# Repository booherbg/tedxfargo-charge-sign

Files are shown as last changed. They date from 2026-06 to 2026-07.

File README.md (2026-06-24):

# TEDxFargo CHARGE — LED Sign

Parametric OpenSCAD system for generating 3D-printable STLs for an illuminated
"CHARGE" sign: channel-letter shells lit from behind by 12mm bullet pixels
through a clear, swappable diffuser panel.

See [`docs/superpowers/specs/2026-06-24-charge-led-sign-design.md`](docs/superpowers/specs/2026-06-24-charge-led-sign-design.md)
for the full design.

## Build

```bash
./build.sh          # renders every part in src/parts/ to ./stl/
```

Requires [OpenSCAD](https://openscad.org/). Override the binary with
`OPENSCAD=/path/to/openscad ./build.sh`.

## Layout

```
src/config.scad     all tunable knobs (edit this, then rebuild)
src/collar.scad     imports the calibrated press-fit collar
src/diffuser.scad   swappable diffuser panel
src/coupon.scad     depth-ladder test coupon
src/parts/*.scad    build targets (open any in the OpenSCAD GUI)
assets/             bullet-collar.stl, letter EPS, logo
stl/                generated output (git-ignored)
```

## First print: the stackup coupon

`stl/coupon_body.stl` is a 3-cell test rig with LED-to-panel gaps of 20 / 35 /
50mm and three merged press-fit collars. Print it in **opaque** filament. Print
`panel_{1,2,3}mm.stl` in **clear** filament and vary slicer infill
(gyroid/grid, top & bottom solid layers = 0) to test the diffuser. The panels
**press-fit** into the chimneys (size = opening − `panel_press_clear`), so you
can swap thicknesses freely. Press a pixel into each collar, and compare.

> Tune `dome_clear` in `config.scad` to your actual pixel's dome protrusion —
> the gap distances depend on it.

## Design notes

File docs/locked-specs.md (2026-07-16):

# Locked specs (validated)

Finalized, print-validated parameters for the **TEDxFargo CHARGE** neon-sign replica.
Change only with a new test. Full onboarding context: `docs/HANDOFF.md`.

## Bullet pixel — the hardware everything keys off
- dome **Ø8**, barrel **Ø12**, flange **Ø13.6 × 2mm**, dome-tip → flange **5.5mm**
- dome protrusion (`dome_clear`) = **4.0mm**; plate bore (`pixel_through`) = **12.3mm**
- calibrated press-fit collar `assets/bullet-collar.stl` (bore ~Ø12.19)
- 24V; **own 300, can buy up to 600**; 150W/24V PSU

## Diffusion recipe ✅ THE WIN
Cross-section = **white reflective shell + ~15mm air gap + chunky clear lens with a BAKED fuzzy top.**
- **Fuzzy winner = V3**: ~**1.5mm** bump cells, ~**0.8mm** bump height (`src/parts/fuzz_v3.dat`,
  regen `tools/make_fuzz.py OUT 1.5 0.8`). Best balance of texture + brightness; **hides individual
  LEDs**; pure heightfield → **no supports, no spaghetti**. (Bambu fuzzy-skin can't texture tops, so it's baked.)
- **Top surface pattern: Concentric.** Print **lens-UP**.
- **White interior recycles light** (fewer LEDs, more even). **Never a dark interior** facing the LEDs.
- Print settings (Adafruit-derived): 0.16mm layer · 0.42 line · 2 walls · 10% gyroid · 6 top/bottom ·
  supports off · brim · bridge fan on.

## LETTER cross-section — 3 colors (filament change)
1. **BLACK** — base/tile (billboard negative space) + channel outer structure.
2. **WHITE** — a couple layers lining the channel **rear (floor) + inner walls** (reflector).
3. **CLEAR** — chunky lens on top with the **V3 baked fuzzy skin**.

## Letters — faithful widened neon outline
- **Faithfully replicate the logo's hollow neon-outline letters** (`assets/svg/{C,H,A,R,G,E,CHARGE}.svg`,
  from EPS via `tools/eps2svg.sh`). **Both neon lines lit.**
- **Widen each neon tube +3mm/side → ~18mm channel** so the Ø12 pixel + collar fit; the hollow-outline
  look is preserved (verified in render).
- **NO letter splitting.** Cap height **270mm** — **rotate the wide letters 90°** so their width runs
  along the 320mm bed axis (at 270mm the widest letter H is ~320mm = the full bed; heights fit easily).
  Sign ≈ **1.6m** wide. (Absolute max ~310mm, but that splits ~5 of 6 letters for +40mm — not worth it.)
- **Pixel pitch ~17mm (TIGHT — chosen)** for a smooth "solid tube" glow → CHARGE + bolt ≈ **~510 pixels**
  at 270mm cap. Buy up to 600 (own 300 + 300 more). (Sparser ~32mm ≈ 270px is the fallback if budget bites.)
- Pixel placement needs a **tube-centerline extractor** (skeletonize each letter) — **TODO tooling.**

## Bolt lens fit ✅ printed & snapped — superseded by the INTEGRATED lens
- `bolt_lip_clear = -0.2` → lip Ø18.2 into the 18.0 channel (0.2mm interference). Material-robust
  (clear PETG + clear PLA). Dialed via `lens_fit_*` slices. The bolt is a **solid-stroke** channel;
  letters use the same channel construction along the neon path.
- **CURRENT (2026-07-02): the lens is co-printed** (`bolt_lens_integrated` in `src/bolt.scad`,
  print `stl/bolt2_2color.3mf`): welded roof + baked V3 fuzzy top, printed lens-UP in use
  orientation — no flip, no mirror, no press-fit. The -0.2 fit stays locked for any future
  separate-lens part. ALL-PETG build (same-material welds; settings-based haze levers dropped —
  tweaks proved unnoticeable; texture is baked geometry).
- **Slicing note (user-verified):** the baked fuzzy top staggers where top/bottom shells land in
  the thin lens → one mid-lens layer shows small "internal island" artifacts (a map of the tallest
  bumps). **Fix: bottom shell layers +1** (or lens infill 100%). Harmless either way — internal,
  hidden by the frosted top.

## Pixel clearance (matrix) ✅ collision-verified
- `led_void = 14.0`, `led_clear = 2.5`, masks on flared floor legs. `src/parts/lens_pixel_collision.scad`.

## Print orientation & support
- Everything prints **lens-up / plate-down, NO supports.** Chiral flip-to-use parts must be pre-mirrored
  (see the chiral-flip note) — but letters/testbox print in use-orientation, so it's moot for them.

## Bed envelope ✅ VALIDATED in Bambu Studio (2026-07-03)
- H2D dual-nozzle ("left/right nozzle only" side bands): the **both-nozzle zone fits the
  worst-case piece 316 × 295** placed 295-across / 316-deep — confirmed by placing
  `stl/bedcheck_316x295.stl` (chamfer = orientation) with the real 3-filament profile.
- Multi-color pieces must sit ENTIRELY between the side bands (every region needs both
  nozzles). Panelizer limits stay `--bed-long 316 --bed-short 296`.
- Print-card notes: prime tower **ON** (right-nozzle-only column — it fits: every plate and
  letter is ≤316 across, and the tower absorbs the black→clear flush), brim OFF on the long
  sides (~2mm spare); consider inner mouse-ears on big black plate corners.

## Letters — build pipeline ✅ LIVE (2026-07-02)
- **`tools/centerline.py`** (pure stdlib + ghostscript): EPS → raster → Zhang-Suen skeleton →
  ordered tube centerline(s) → pixel points at pitch → `src/parts/letter_<L>_data.scad`
  (+ a `.debug.ppm` overlay — always eyeball it). Letters are OPEN neon-tube runs, not closed
  outlines (the C = ONE 1161mm tube: outer sweep + mouth turn + inner sweep; 69 px @ 17mm).
- **`src/letter.scad`**: 3-color tile — BLACK base+outer wall / WHITE liner+inner wall+collars /
  CLEAR welded fuzzy lens. Channel cross-section identical to the bolt (18 interior / 22 outer).
- **C @ 270 cap**: tile 313×298×23mm — H2D fit only with width along the 320 axis, `lt_margin=2.5`.
  ⚠ At 270 cap the H's art is ~321mm wide and the +3mm/side WIDENED band ≈ **331mm → H will NOT
  fit the 320 axis**. When H's turn comes: cap ~255–260, or split H after all, or widen H's
  outer verticals inward-only. (Rotation can't save a 331×~290 tile on a 300×320 bed.)

## Still open
- **Generate the other letters** (H A R G E — extractor is generic) + integrate the bolt into the layout.
- **Mounting:** rear rail / black backer board (hides wiring + controller). Deferred.
- **Full-billboard extras** (arrow, TEDxFargo badge, 2026, yellow border, truss) — later scope.

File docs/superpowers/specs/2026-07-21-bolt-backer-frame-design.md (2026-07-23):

# Bolt backer frame — printed torsion box, vented, internal PSU

**Goal:** give the bolt board (410×550, 4 plates + 4 seam straps, no frame today)
a fully printed enclosure: stiff, clean, fully closed back with vent slits,
wall-hung or free-standing, controller AND PSU fully enclosed — ONE mains cable
through a side-wall gland and that's it. Experiment to replace the heavy
carpenter-built wood frame style used on the word sign.

User decisions (2026-07-21, three revision rounds same day): **picture-frame
torsion box** over sparse ladder and monocoque tub; **internal PSU from day
one** — plan for the whole 30-mm-tall LRS family (**LRS-50 / 75 / 100**, one
tray profile); cavity **36 mm** (tray floor 4 over the flange + PSU 30 + 2
clear; wall-FACE mounting like the word sign's exterior would need 50+ mm
walls, rejected); fully closed back **with vent slits**; snap-in **feet** in
bottom-rail slots; **two thick top handles** for carrying + wall-hanging
(replace the loops/keyhole idea); controller = **Gledopto Elite 2D-EXMU
(GL-C-616WL, 129×50×23)** inside, shell end-tab screws; **one PG9 gland,
printed open** — no knockouts to punch or drill, alternates are swap plates.
M3 self-tap into printed bosses now, bores sized so M3 heat-set inserts are a
later drop-in.

Total sign body ≈ 40 mm behind the plate front (plate 2 + cavity 36 + panel
2.4), plus the front shell as built.

**V1 AS-BUILT CONFIGURATION (2026-07-22, user simplification):** controller
mounts OUTSIDE on the left-wall pads (`fr_ctl_ext`, screws at the probed
122 × 26 diagonal, body spans y ≈ 96..225), fed by a plug-in PSU — nothing
electrical inside. One **PG7 gland threaded directly into the 3.0 mm wall**
(Ø12.5 hole at y = 275, z = 19; 3.0 ≤ the 3.5 clamp limit, so no plate)
passes the single jacketed 3 × 18 AWG V+/V−/D line into the cavity, 50 mm
(2 in) above the controller's top/output end for working room — the position
is capped by the y = 300 segment joint (asserted). Everything below —
internal trays, PSU patterns, gland plate — is BUILT and KEPT as the
enclosed-future path; `GLAND_PLATE = 1` in tools/boltframe.py restores the
plate opening for the internal-PSU pivot (rails reprint required then).

**V1.1 (2026-07-22, user): cavity 36 → 48, trim dropped.** Wall becomes
50.4 ≥ the Elite's 50 width, so the exterior controller sits FULLY FLUSH on
the outer face (body z 0.4..50.4, back coplanar with the panel plane — no
front/back overhang, wall-hang unaffected). Trim strips and their groove are
dropped (`TRIM = 0`; PART=6 remains printable if ever wanted). S3/S4 rails
8 → 44, legs parametrized to `fr_cavity`. Sign body ≈ 52 mm behind the plate
front. Note: the controller DOES fit INSIDE lying flat (27 < cavity) — the
deepening is only for the flush wall-face mount; interior tray unchanged.

## Frame rails (4 corner-L segments, white PETG)

- C-channel: **flange** 16 × 4 mm behind the plate perimeter with 14 pilot
  bosses at the existing `bb_scr` kind-0 positions (the wood-rail band —
  keepout already validated); plates screw down from the front, screws they
  already have. **Outer wall** 3 mm. **AS-BUILT AMENDMENT:** the 2 mm front
  reveal is a separate **snap-on trim strip** (frame_parts PART=6, groove in
  the wall outer face) — one-piece lip + rail can't print support-free, and
  the split lets rails print FLANGE-DOWN cleanly; `reveal=0` = don't print
  trim. The trim never covers a screw: holes sit 6 mm from the plate edge,
  hole rim at 3.75, trim covers 2 (generator asserts). Assembly: sign
  face-down, segments laid flange-down onto the plate backs, dovetails
  joined, flip once, drive the 14 screws, snap trim on last.
  **Ledge** 8 × 4 mm at cavity depth 36 with M3 panel bosses.
- Segments are corner-Ls meeting at **x=205 / y=300** (AS-BUILT: y moved
  275→300 — the probe caught the joint splitting the (6,275)/(404,275)
  bosses, and 300 also clears the S1/S2 strap band; asserted now). Joint =
  printed dovetail key in an inner-face pocket + M3 cross-screws from
  outside through wall+pad into the key.
- **Handles ×2** on the top rail near the corners: thick printed bars
  (grip opening ≈ 100 × 28, body ≥ 14 thick), each bolted with 2 × M4 +
  washer/nut into top-rail bosses. Back faces sit FLUSH with the back-panel
  plane so the sign hangs flat on a wall — the grip opening doubles as the
  hang point (screw head, cleat, chain, or zip tie through it) and as the
  carry handle. Printed lying flat so layer lines run along the load path.
- Bottom rail: 2 snap sockets in the underside for **snap-in feet**
  (AS-BUILT: split-prong arrowhead tab + barb pocket — a true T-slot can't
  insert from below; squeeze the prongs from inside to release; blade
  ≈ 90 mm fore-aft); sign is wall-hung with feet out.

## Strap interface (folds in the chirality reprint)

- **S3/S4 reprint** (already required — chirality fix 6edb95e): rails raised
  8 → 32 mm (web 4 + 32 = 36 = cavity depth) with M3 bosses on top; they become
  the panels' mid-span supports. Pass-hole chamfers already cut through rails.
- **Captive hex pockets dropped on the reprint** (user 2026-07-21: nut depth/
  alignment in a pocket is fiddly — prefers flat + washer): screw bores become
  plain Ø4.5 through-holes with a FLAT back face; washer + M4 nut tightened
  from the open back (panels aren't on yet at strap-install time; the 38 mm
  gap between the raised rails leaves driver room). Screw length changes:
  plate 2 + web 4 + washer + nut ≈ 10 — the existing M4×8 are too short,
  **use M4×10 (flush) or M4×12**. `nut_pocket` param restores the old pocket
  if wanted. S1/S2 keep their pockets (installed, working).
- **S1/S2 stay installed** (correct as printed): three Ø10 printed legs drop
  into the existing leg sockets, M3 boss on top at panel height (36).
- Plates, pixels, wiring untouched.

## Back panels (4 quadrants, vented, removable)

- ≈ 209 × 279 each (bed-fit), 2.4 mm skin + ribs, half-lap rebates at
  panel-to-panel edges so they register flush. M3 screws into ledge bosses,
  raised S3/S4 rail bosses, and S1/S2 leg tops — back comes off without
  touching the plates.
- Vents: angled louver slits (light-tight, dust-shedding), intake rows along
  the bottom panels, exhaust rows in the top third; one consistent pattern,
  plus a small cluster over the controller (mic aperture for audioreactive +
  convection over the equipment corners — PSU and controller both live up
  top, so the exhaust rows do double duty).

## Internal equipment (top corners — the verified pixel-free zones)

Placement is pinned by a clearance sweep against the real pixel map (the
originally-sketched lower-left PSU spot FAILED it — a pixel sat inside the
rect; the bolt's bottom and diagonal channels fill the lower half). The two
clean zones are the TOP corners. Devices lie FLAT on 4-mm tray floors that
span the flange band, integrated into the top corner-L segments; devices stay
with the sign when panels come off.

- **PSU tray (upper-LEFT)**: zone x ≈ 1..98, y ≈ 407..536 (AS-BUILT: slid
  down 8 so the top ledge bosses clear the tray) — 28.6 mm to the nearest
  pixel, 4 mm to S3's raised rail. Fits the whole family in portrait
  (all 30 tall, L=3.0 bottom taps, M3×7 through the 4 mm floor = 3 mm in):
  - LRS-50 (case 239A, 99×82) + LRS-75 (240A, 99×97): shared **slots** at
    length 20.5/75.5 spanning width 40.5→45.5 (AS-BUILT: the two patterns
    are 5 mm apart — one slot serves both)
  - LRS-100 (case 238A, 129×97): round holes (78, 34) + (78, 67)
  Terminals point DOWN toward the cavity. Before buying: match the voltage
  to the pixel string — LRS is 5/12/24 V.
- **Controller tray (upper-RIGHT)**: Elite vertical, zone x ≈ 342..392,
  y ≈ 405..534 (10.7 mm to the nearest pixel — generator asserts ≥ 8.5 + 2).
  Two bosses at the shell's end screws — **122.0 × 26.0 diagonal, Ø4.6**
  (probed from docs/elite2d_mount.stl; no adapter plate needed). Terminals
  face the cavity; WiFi works through PETG. USB-C/Ethernet/button need the
  panel off — accepted, WLED is OTA.
- **Wiring run**: mains in low on the left wall → up the flange shelf to the
  PSU AC end (cord FG lands on the LRS FG terminal); DC across the top rail
  channel to the controller INPUT; OUTPUT drops to the chain entry at
  (194, 180). All runs < 500 mm.
- **Gland plate** low on the LEFT side wall (side entry keeps free-standing
  on the feet stable; low = hidden, cord drops to the floor): a 2.5-mm-thick
  screwed-on plate (2 × M3 into wall bosses) over a rectangular opening.
  V1 plate ships with ONE **PG9** hole printed OPEN (Ø15.2, clamps 4–8 —
  takes a 3-wire SVT mains cord; no drilling, no punch-outs). Variant plates
  (PG7 Ø12.5, PG11 Ø18.6, or two-hole for a word-sign link) are 5-minute
  prints — swap the plate, not the rail. **Seats stay ≤ 3.5 mm** — PG thread
  is ~8 mm and the locknut needs ~5 (user has over-thickened walls before;
  generator asserts). Fusing and relays live on the controller.

## Fasteners / material / mass

White PETG throughout (matches straps). SIMPLIFIED BOM (2026-07-23): three
screw SKUs, all ordinary machine screws threading printed pilots —
- M4×12 black button ×25: 11 strap (+ M4 nuts, washers optional) + 14
  plate→flange (flange pilots Ø3.4; the M4 head covers the Ø4.5 plate hole,
  no washers anywhere)
- M4×30 button ×4 + washers: handles
- M3×12 flat/countersunk ×37: 29 panels + 8 dovetail keys (every M3 pilot
  Ø2.8 × 10.5 deep so one length fits all)
Boss OD 7 keeps the M3 heat-set upgrade path. Estimate ≈ 1.3–1.7 kg total:
4 rails (2 with equipment trays) + 4 panels + 2 handles + 2 feet + 3 legs
(+ S3/S4 ~265 g at the taller rails; trim strips optional glue-on).

## Build & verify

- New generator emits `frame_layout.scad` (rail segments, boss positions from
  `bb_scr`, panel outlines, tray anchors + PSU hole patterns, gland position,
  handle bosses) + part scads in the existing `-D PART=` style; build lines
  added to build_board.sh. Generator asserts: both tray rects ≥ 11 mm from
  every `bb_px`/`bb_bite`; PSU top clearance ≥ 2; tray clear of S3 rails.
- qa_board.py grows frame checks: flange bosses == `bb_scr` kind-0 positions
  (axis-aware — see the chirality lesson), every segment/panel fits 316×295,
  panel screw bosses land on ledge/strap/leg supports, joint keys clear
  screw holes, reveal lip clears every `bb_scr` hole rim, gland-plate seat
  thickness ≤ 3.5 (PG clamp limit), handle back faces coplanar with the
  panel plane.
- Print order: S3/S4 straps first (unblocks the strap swap), then rails,
  panels, handles, feet, gland plate.

## Config params (all have working defaults)

`psu` (LRS-50/75/100 hole pattern, default all), `gland` (PG9 default /
PG7 / PG11 / two-hole link variant), `reveal` (2, 0 disables), `nut_pocket`
(off), supply-cord diameter only if it falls outside PG9's 4–8 mm clamp.

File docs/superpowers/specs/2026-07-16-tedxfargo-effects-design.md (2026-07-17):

# TEDxFargo custom WLED effects — design (2026-07-16)

Geometry-aware custom effects for the CHARGE sign, compiled into one small WLED
usermod. This spec is written to be built from a **clean session** with no
dependence on the conversation that produced it — every load-bearing WLED fact is
stated with a source reference so the builder never guesses.

---

## 1. Goal

A handful of bespoke effects that know what the pixels *are* (which letter, where
in space, where in the wiring chain) — things no stock effect can do because stock
effects only see an anonymous grid. First deliverable: the full build pipeline
proven end-to-end on hardware with **one** effect (the neon boot-up), flashable and
eyeball-verifiable. Everything after is thin additions.

**Non-goals (this spec):** the bolt/board controller (deferred — still being
built), any triggered/event-cued show logic, cross-controller sync, and the
multiplayer letter game. All explicitly out of scope (§12).

---

## 2. Current state (what already exists)

- **The sign — word controller only for now.** 459 WS281x pixels, 6 letters
  C H A R G E, wired as one greedy tube-order chain. Physically a lightning/neon
  aesthetic in electric cyan with yellow/red accents.
- **The device is in 2D matrix mode** via a flashed `ledmap.json` (134×25 grid,
  12 mm cells — committed at `ad19744`, hardware-confirmed). `isMatrix` is true;
  stock 2D effects render in true sign space. ~90% of the 3350 grid cells are `-1`
  gaps (no LED). Controller: Gledopto **GL-C-616WL** (ESP32, **no PSRAM**, ~73 KB
  free heap — this is why heavy 2D effects sometimes deplete RAM).
- **`tools/gen_wiring.py`** already loads `src/parts/word_pixmap.json`, computes
  each pixel's grid (col,row) at `WORD_CELL_MM = 12.0`, and emits the ledmap +
  presets. It is the single source of truth for geometry. We extend it to also
  emit the C header this design needs.
- **`src/parts/word_pixmap.json`** — the wiring truth. `pixels[]`, one per LED, in
  chain order (index 0..458). Fields per pixel: `x`, `y` (physical mm), `letter`
  (`"C".."E"`), `piece` (1..6, physical print piece), `chain` (== array index).
- **Letters are contiguous ranges in chain order** (verified): C 0–61, H 62–142,
  A 143–214, R 215–295, G 296–378, E 379–458. So "letter membership" is just a
  range test — no per-pixel lookup table needed for grouping.
- **Custom palettes on device** (`wled/backups/palette0-2.json`): electric cyan +
  yellow/red lightning accents. These are the effects' default color intent.

---

## 3. Key decisions (with rationale)

1. **2D substrate — keep the ledmap, do NOT switch to a 1D strip.** The user's
   favorite effects (Palette bars sweeping, Hiphotic, Fire-from-both-sides, Meteor,
   Shimmer, PS Vortex) are all *spatial* — color moving through 2D space, letters
   relating to each other. That is exactly what a 2D matrix provides and a 1D strip
   fundamentally cannot (a strip has only chain order, no vertical axis, no
   "across"). Going 1D would mean reimplementing every favorite *and* discarding the
   quality that makes them land. So the device stays 2D; custom effects address
   real LEDs via a baked geometry table + `setPixelColorXY`.
2. **A usermod is the container; the effects are ordinary custom effects.** New
   effect logic must be compiled in — presets/playlists/JSON can only recombine
   existing effects. The two homes are core `FX.cpp` (scatters our code through
   core, fights every WLED update) or a usermod (isolated in `usermods/tedxfargo/`,
   registers via `strip.addEffect()` in `setup()`, and is the natural home for the
   shared geometry helpers and the future letter-coloring HTTP endpoint). Usermod
   wins on every axis. It's lightweight: a folder + a small class + one build flag.
3. **Ambient loop.** Effects live in normal playlists next to stock effects. No
   trigger, cue, or sync layer. The "hero moment" (boot-up → strike → burst) is a
   single phased effect that loops, not an event system.
4. **Base repo: direct clone of `GLEDOPTO/WLED` @ `gledopto-16.0.1`.** This is the
   exact firmware already running on the sign — stock WLED 16.0.1 plus a thin
   Gledopto config commit (board env, onboard mic, branding). Cloning it directly
   guarantees we build against a known-good config and only add our usermod.
   (Fork-strategy cleanup — rebasing onto a clean WLED fork — is deferred; "rectify
   later.") Every API fact below was verified against WLED 16.0.1, which this
   branch is.

---

## 4. Architecture

```
src/parts/word_pixmap.json ──► tools/gen_wiring.py ──► usermods/tedxfargo/charge_geometry.h
                                                              │
                                                              ▼
        usermods/tedxfargo/usermod_tedxfargo.h  (Usermod class)
          • setup(): strip.addEffect(255, &mode_fn, PSTR("meta")) per effect
          • owns geometry helpers over charge_geometry.h (the 5 primitives)
          • (later) registers the letter-coloring HTTP endpoint
                                                              │
             mode functions: mode_charge_bootup(), ...        │  each ~20 lines
                                                              ▼
        platformio env GL-C-616WL:  custom_usermods = tedxfargo
                                                              │
                                                              ▼
                              build ──► flash ──► effect appears in WLED effect list
```

Every effect follows one uniform pattern: iterate the 459 pixels, compute a color
from the baked fields (letter / x / y / height / chain), and place it with
`SEGMENT.setPixelColorXY(col, row, color)`. The ledmap routes (col,row) → the
physical LED. **Effects assume a full-canvas 2D segment anchored at (0,0)** (the
default segment), so segment-relative XY equals absolute grid XY.

---

## 5. The baked geometry header (`charge_geometry.h`)

Emitted by `gen_wiring.py`, indexed by chain index `i` (0..458). All arrays
`PROGMEM`, ~3 KB flash total.

```c
// Generated by tools/gen_wiring.py — DO NOT EDIT. Regenerate with the ledmap so
// COL/ROW stay in sync with the flashed ledmap.json (same WORD_CELL_MM).
#define CHARGE_NUM_PIXELS  459
#define CHARGE_NUM_LETTERS 6
#define CHARGE_GRID_W      134   // must equal the active ledmap width
#define CHARGE_GRID_H      25    // must equal the active ledmap height

// enum order = chain order of first appearance: C,H,A,R,G,E
const uint8_t  CHARGE_LETTER[459] PROGMEM = { 0,0,...,5 };  // 0=C .. 5=E
const uint8_t  CHARGE_COL[459]    PROGMEM = { ... };        // grid col 0..133
const uint8_t  CHARGE_ROW[459]    PROGMEM = { ... };        // grid row 0..24 (0=top)
const uint8_t  CHARGE_HEIGHT[459] PROGMEM = { ... };        // 0..255, 0 = base of its letter, 255 = top
const uint8_t  CHARGE_XNORM[459]  PROGMEM = { ... };        // 0..255 x across whole sign (left..right)

// letters are contiguous in chain order → ranges, not a lookup
const uint16_t CHARGE_LETTER_START[6] PROGMEM = { 0, 62, 143, 215, 296, 379 };
const uint16_t CHARGE_LETTER_COUNT[6] PROGMEM = { 62, 81, 72, 81, 83, 80 };
```

Derivations (all in `gen_wiring.py`, from the same data that builds the ledmap):
- `CHARGE_COL/ROW[i]` = `gen_wiring`'s existing grid mapping at `WORD_CELL_MM`
  (`gx = int((x-ox)/cell)`, `gy = int((h_mm-(y-oy)-eps)/cell)`). **Must match the
  flashed ledmap** — regenerate both together.
- `CHARGE_HEIGHT[i]` = normalize `y` within pixel i's letter's [ymin,ymax] → 0..255,
  base=0. (Physical y increases upward; base = smallest y.)
- `CHARGE_XNORM[i]` = normalize `x` across the whole sign [xmin,xmax] → 0..255.
- `CHARGE_LETTER_START/COUNT` computed from `letter` runs (assert contiguity).

**Coupling note:** the header's COL/ROW and the flashed `ledmap.json` are two
outputs of the same mapping. If `WORD_CELL_MM` changes, regenerate both and
re-flash both. `gen_wiring.py` emits them in one run — keep it that way.

---

## 6. The five primitives (helpers on the usermod class)

Thin accessors over the header. This is the entire shared surface every effect uses.

1. **Letter groups** — `for (i = LETTER_START[L]; i < LETTER_START[L]+LETTER_COUNT[L]; i++)`.
   Powers: boot-up, per-letter Pac-Man, per-letter Fireworks, letter flicker.
2. **Tube order within a letter** — chain order *is* tube order (wiring is greedy
   along the neon path), so iterating a letter's range walks its tube. Powers:
   tube-trace, flames climbing into a letter.
3. **Height within letter** — `CHARGE_HEIGHT[i]` (0=base). Powers: flames rising,
   bottom-up fills.
4. **X across the sign** — `CHARGE_XNORM[i]`. Powers: jet-stream / lightning /
   meteor sweeps, with letters as spatial waypoints.
5. **Audio** — the AudioReactive usermod is compiled into this build (§10). Effects
   read its shared FFT data (`um_data` bins) for reactive flames. (Access pattern:
   the standard `usermods.getUMData(&um_data, USERMOD_ID_AUDIOREACTIVE)` handshake —
   verify signature against the audioreactive usermod at build time.)

Place with `SEGMENT.setPixelColorXY(CHARGE_COL[i], CHARGE_ROW[i], color)`.

---

## 7. The usermod

Scaffold by **copying an in-repo template** so registration boilerplate is exact:
`usermods/EXAMPLE/` (general) and `usermods/PS_Comet/` (a usermod that adds an
effect — the closest reference). Do not hand-write the registration macro from
memory; copy it.

```
usermods/tedxfargo/
  charge_geometry.h        # generated (§5)
  usermod_tedxfargo.h      # Usermod subclass
```

`usermod_tedxfargo.h` responsibilities:
- Include `charge_geometry.h`.
- Define each effect's `mode_*` function + its metadata string (§8).
- In `setup()`: `strip.addEffect(255, &mode_charge_bootup, _data_CHARGE_BOOTUP);`
  once per effect. `id == 255` means "append to the next free slot" (verified,
  `FX.cpp` `addEffect`). Returns the assigned id, or 255 on failure — log if 255.
- Self-register with the same static-instance + registration macro the template
  uses.

Enable it in the board env: `custom_usermods = tedxfargo` (§10; the Gledopto env
enables the mic via a legacy define, so ours is the only `custom_usermods` entry).
The `pre:pio-scripts/load_usermods.py` script includes it from the folder name.

---

## 8. Writing an effect (verified API)

A WLED effect is a free/static function `void mode_x()` (WLED 16.0.1 —
`typedef void (*mode_ptr)()`; older WLED returned `uint16_t`). It reads/writes
through the `SEGMENT` macro; frame timing is derived from `strip.now`
(frame-coherent millis) inside the effect, not from a return value.

```c
static const char _data_CHARGE_BOOTUP[] PROGMEM = "CHARGE Boot@Speed,Flicker;;!;2";

void mode_charge_bootup() {
  // strip.now = frame-coherent millis (drive time-based animation from this)
  // SEGENV.step / .aux0 = free per-segment state; SEGENV.call = frame counter
  // SEGMENT.speed, SEGMENT.intensity = the two sliders (0..255)
  // ... compute per pixel, then:
  //   SEGMENT.setPixelColorXY(pgm_read_byte(&CHARGE_COL[i]),
  //                           pgm_read_byte(&CHARGE_ROW[i]), color);
  // no return (void)
}
```

**Metadata `@`-string format** (from `FX.cpp` `_data_FX_MODE_*`, verified examples):
`"Name@slider1,slider2,...;color1,color2,...;palette;flags;defaults"`
- `!` = use the default label (Speed, Intensity, `!` color = primary, etc.).
- Empty slot = hide that control.
- `flags`: `1`=offer in 1D, `2`=offer in 2D, `12`=both. **Ours use `2`** (we call
  `setPixelColorXY`, so they must be 2D-capable / offered in 2D mode).
- `defaults` (optional): e.g. `sx=128,ix=200,pal=6`.
- Real references: `"Meteor@!,Trail,,,,Gradient,,Smooth;;!;1"`,
  `"Fireworks@,Frequency;!,!;!;12;ix=192,pal=11"`. Copy the shape from the closest
  stock effect.

Verified API surface (all in the clean WLED 16.0.1 checkout):
| Need | Symbol | Source |
|---|---|---|
| Register an effect (append) | `strip.addEffect(255, fn, meta)` | `FX.h` decl / `FX.cpp` body |
| Current segment | `SEGMENT` macro | `FX.h` (`*strip._currentSegment`) |
| Place a 2D pixel | `SEGMENT.setPixelColorXY(x,y,color)` | `FX.h` |
| Per-segment runtime state | `SEGENV.call/.step/.aux0/.aux1`, `SEGENV.allocateData()` | `FX.h` |
| Sliders / options | `SEGMENT.speed/.intensity/.custom1..3/.check1..3` | `FX.h` |
| Palette color | `SEGMENT.color_from_palette(...)` | `FX.cpp` |
| Frame timing | `strip.now` (frame-coherent millis); mode fn is `void` | `FX.h` / `FX_fcn.cpp` |
| Is this segment 2D | `SEGMENT.is2D()`, `.virtualWidth()`, `.virtualHeight()` | `FX.h` |

---

## 9. First cut — "neon boot-up" (the deliverable to flash and see)

**What the first plan builds:** the whole pipeline — `gen_wiring.py` emits
`charge_geometry.h`; the `usermods/tedxfargo/` scaffold; one registered effect; the
`GL-C-616WL` env with the usermod enabled; a successful build; flash — proven by
one effect on the wall.

**Effect: "CHARGE Boot".** The sign ignites like a neon sign warming up.
- Letters light in chain order C → H → A → R → G → E, one at a time, paced by
  `Speed`.
- Each igniting letter flickers on — a few random on/off dips (amount = `Flicker`
  / `intensity`) before settling to steady cyan (the CHARGE electric color).
- Once all six are lit, hold briefly, then loop (re-ignite).
- Primitives used: **1** (letter groups) + light use of flicker randomness. Color:
  fixed electric cyan for v1 (palette wiring can come later).

**Why this is first light:** it exercises letter grouping *and* placement, and it's
trivially falsifiable — if letters light **in the right places and the right
order**, the entire chain (header correctness, COL/ROW ↔ ledmap agreement,
`addEffect` registration, `setPixelColorXY` routing, the build/flash) is proven at
once. If a letter lights in the wrong spot, the geometry header is wrong; if
nothing lights, registration/build is wrong. Clean signal either way.

**Verification (definition of done for cut 1):**
1. Build the `GL-C-616WL` env succeeds; "CHARGE Boot" appears in the effect list.
2. On hardware: selecting it makes the six letters ignite in order, in their
   correct physical positions, with visible flicker, then hold and loop.
3. Stock 2D effects still work (usermod didn't disturb the matrix).

---

## 10. Build & flash

**Base:** direct clone of `GLEDOPTO/WLED`, branch `gledopto-16.0.1` — the exact
build on the sign. Do our work on a new branch off it. `[env:GL-C-616WL]` already
exists there and already configures the board: `extends = esp32_eth`, relay
GPIO18, button GPIO17, data pins 16 & 2, Ethernet (`WLED_ETH_DEFAULT=13`), and the
onboard PDM mic via `${mic_pdm.build_flags}` (`-D UM_AUDIOREACTIVE_ENABLE`,
I2S SD=32 WS=15). We do **not** recreate any of that.

**Only env change — enable our usermod.** Add one line to `[env:GL-C-616WL]`:

```ini
custom_usermods = audioreactive tedxfargo
```

Notes:
- **`audioreactive` MUST be relisted** (corrected 2026-07-16 during the build,
  verified against the checkout): the parent `[env:esp32_eth]` sets
  `custom_usermods = audioreactive`, and defining the option in the child env
  REPLACES the inherited value — `custom_usermods = tedxfargo` alone silently
  drops the audioreactive usermod (mic + all AR effects gone). The env's
  `-D UM_AUDIOREACTIVE_ENABLE` does *not* compile the usermod in; in 16.0.1 it
  only flips the usermod's boot-time `enabled` default (audio_reactive.cpp).
- The real 459-LED count comes from the device config already on the controller —
  nothing to set in the env.
- Flash: `pio run -e GL-C-616WL -t upload` (USB) or OTA. Back up config + presets
  first (WLED UI → Backup).

**Toolchain:** VS Code + PlatformIO, or `pio run -e GL-C-616WL`.

---

## 11. Effect backlog (post-cut-1, each a thin function over §6)

Grouped by the primitive they lean on. Build/iterate in roughly this order.

- **Per-letter (prim 1,2):** per-letter Pac-Man; per-letter Fireworks (TedX
  colors); letter flicker (blue ↔ TedX morph); tube-trace comet.
- **Base-up + audio (prim 1,3,5):** flames at each letter's base, rising into the
  letter, height/energy driven by that letter's audio band; over a solid / gradient
  / slowly-rotating palette background.
- **Cross-sign sweeps (prim 4):** jet-stream pulse (burning edge sweeping across all
  letters, red bg / blue-yellow front); lightning that forks across the letters;
  meteor variants.
- **Composited:** sparkle / "electrical" layer (popcorn-style) over a palette field
  — mirrors the segment-overlay look the user already likes, as one effect.
- **Hero narrative (composes prim 1,4):** boot-up → hold → pause → lightning strike
  through all six letters → multicolor 2D burst finale → reset → loop.

The six stock 2D keepers (Hiphotic, Palette, PS Vortex, Shimmer+transpose, Fire
2012 both-sides, Meteor) stay as-is in playlists — no work.

**Letter-coloring HTTP app (later):** a usermod web endpoint that colors pixels by
`CHARGE_LETTER[i]` (zero bleed, unlike 2D rectangles). Lives in this usermod.

---

## 12. Out of scope

- **Bolt/board controller** — still being physically built; its geometry header,
  zones, and effects come later (the pattern here ports directly).
- **Multiplayer letter-completion game** — a networked, stateful, multi-client app,
  not an effect. Separate project.
- **1D device mode** — rejected (§3.1).
- **Triggered/cued show control & cross-controller sync** — ambient loop only.

---

## 13. Risks, gotchas, assumptions to verify at build start

- **Header ↔ ledmap sync.** COL/ROW must match the flashed ledmap grid. Both come
  from `gen_wiring.py` at `WORD_CELL_MM=12`; regenerate and re-flash together.
- **Ledmap byte-format gotcha (already handled, keep handled).** WLED finds the map
  with a raw byte search for `"map":[` — a space after the colon loads zero cells
  silently. `gen_wiring.py` already dumps compact + asserts; `tools/test_wled_ledmap.py`
  guards it. Not our code to touch, but don't regress it.
- **RAM.** Custom effects on the 459-real-LED set are light (iterate 459, one
  `setPixelColorXY` each — no big buffers). Safe on the 73 KB heap. Only avoid
  allocating a full W×H shadow buffer.
- **Usermod-enable.** `custom_usermods = audioreactive tedxfargo` — audioreactive
  must be relisted because setting the option in `[env:GL-C-616WL]` replaces the
  value inherited from `[env:esp32_eth]` (see §10 note; the original claim here
  was wrong and was corrected during the build).
- **Audio data access.** The `um_data` handshake signature — verify against the
  audioreactive usermod in the checkout before writing flame effects (not needed
  for cut 1).
- **Segment assumption.** Effects assume a full-canvas 2D segment at origin. If a
  preset uses a sub-segment, XY is segment-relative — document this for effect users.
- **`addEffect` returns 255 on failure** (list full / id clash). Log it in `setup()`.

---

## 14. Verification & testing

- **Unit-ish (host):** extend `tools/test_wled_ledmap.py` or add a small check that
  `charge_geometry.h` is internally consistent — letter ranges contiguous and
  covering 0..458, COL/ROW within grid bounds, every pixel's COL/ROW equals the
  ledmap's position for that physical index (header ↔ ledmap agreement).
- **On hardware (cut 1):** the boot-up acceptance in §9.
- **Regression:** stock 2D effects still render correctly after flashing the usermod
  build (the matrix/ledmap path is untouched).

---

## 15. Build order (for the implementation plan)

1. `gen_wiring.py`: emit `usermods/tedxfargo/charge_geometry.h` (+ host consistency
   check).
2. Scaffold `usermods/tedxfargo/` from the `EXAMPLE`/`PS_Comet` template; empty
   `setup()` that registers nothing yet; get it building + enabled in the env.
3. Add `mode_charge_bootup` + metadata; register in `setup()`.
4. Build `GL-C-616WL`, flash, run the §9 acceptance.
5. Then iterate the §11 backlog, one thin function at a time.

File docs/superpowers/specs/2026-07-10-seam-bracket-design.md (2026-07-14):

# Bolt-board seam brackets — continuous LEDs across the plate joints

**Goal:** kill the 34–58 mm dark spots where the bolt board's channels cross the
4-plate seams (pixels were kept ≥12.5 mm off every joint), while replacing the
LED-blocking y-seam wood rail with printed splice brackets the plates screw into.

User decisions (2026-07-10): plates NOT yet printed (regenerate freely); keep the
board at **137 pixels** (re-spread, no inventory impact — hard cap 600); captive
M4 hex nuts in the bracket, M4×8 black button-heads from the front; leg sockets
now, snap-in "pizza saver" legs only if the mounted panel flexes. Approach B
(hybrid) chosen over straddle-only (A) and full collar-carrier (C).

## Placement (approach B, verified by simulation)

- Keepout shrinks 12.5 → **9.5 mm** perpendicular (Ø16 collar hole keeps a
  1.5 mm web to the plate edge).
- At each channel/seam crossing, pixels are **pinned** symmetrically at arc
  offset 9.5/sinθ each side. Where the straddle arc exceeds 25 mm — the two
  shallow crossings, 31° at (153, 51) and 29° at (126, 401) — pin **one pixel ON
  the seam** instead; its collar lives in the bracket.
- Even-fill between pins/path ends; pitch solved to land exactly 137
  (sim: 21.5 mm). Existing relaxation de-conflicts tube crossings; pins are
  immovable and never dropped.
- Verified: every seam-adjacent gap ≤ 23.2 mm vs 21.5 running pitch; min pair
  spacing 14.2 (snug band 13–14.5 OK). Remaining big *arc* gaps are the
  bolt-tail hairpin (14.4 mm chord, both walls lit) and crossing pockets lit by
  the crossing tube — both exist in the approved design.

## Brackets (4 white PETG straps + pusher tool)

S1+S2 y=255 (410 mm, two lap-jointed segments), S3 x=126 (295 mm), S4 x=153
(255 mm). ~48 mm wide, 4 mm web, two 8 mm back rails (shallow U). Printed
**front-face-down** so the plate-mating face is flat and an embedded collar
prints in the same first-2 mm-on-bed orientation as plate collars (calibrated
press-fit transfers).

Generated features:
1. **Ø17 chamfered pass-through holes** at every pixel inside the strap
   footprint (pixel presses into its normal plate collar through the bracket).
2. **2 embedded collars** (standard collar STL) flush in the front face at the
   on-seam pixels; Ø14.5 flange pocket behind (bracket is exactly 4 = 2+2).
   Pixel seats 2 mm deeper: dome tip 17.5 mm from lens — inside the validated
   10–20 window. Plates get a **Ø13 bite** split across the mating edges
   (through black + white liner). No plate collar at these two positions.
3. **M4 nut pockets** (7.2 AF, 3.2 deep, opening back) paired across the seam
   every ~60–80 mm in black-field intervals; generator asserts ≥2 pairs per
   segment + a pair per T-junction quadrant, and that screw holes never pierce
   a channel (new check). ~15 pairs ≈ 30 × M4×8 + nuts.
4. **Leg sockets** Ø10.2 in 16 mm bosses at the two T-junctions + y-midspan;
   legs printed later at measured plenum depth if needed.

No wire slots needed: assembly is brackets-first (plates butted face-down →
brackets screwed on → panel to frame by perimeter screws → pixels press in from
behind through the bracket holes → chain). Wires always route behind the
bracket plane. Pusher = Ø13.5 slotted tube for seating pixels through Ø17 holes.

## Pipeline

`boltboard.py` gains the anchored placement + emits `bracket_layout.scad` and
bite positions in `board_layout.scad`; new `src/parts/bracket.scad` → white
STLs (single color, plain STL). Plates re-render via `build_board.sh` with mesh
audit + 2D-projection visual check. `bolt_pixmap.json`/chain regenerate.
Assembly card: y-seam rail removed from the frame plan; perimeter rails only.

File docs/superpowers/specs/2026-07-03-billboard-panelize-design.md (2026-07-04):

# CHARGE billboard — whole-word panelization + wood-frame mount (approved 2026-07-03)

Supersedes the per-letter rectangular-tile plan. The sign face is designed as ONE continuous
billboard and then cut into printable pieces; a wooden frame mounts it and swallows the wiring.
Cross-section/diffusion recipe is unchanged from `docs/locked-specs.md`.

## Size & face
- **Cap height 250 mm, uniform** (no per-letter distortion; the shared horizontal cut line across
  all letters aligns by construction). CHARGE face ≈ **1.56 m wide**.
- **Piece height uniform ≈ 295 mm** (tallest letters ~257 + top/bottom screw bands ~14 mm each;
  also keeps every piece ≤ 300 mm on the bed's short axis). Final number set by the generator.
- Face is **continuous black between letters** — no gaps, no per-letter tiles.
- Letters: hollow neon outlines from `assets/letters/*.eps`, tube centerlines extracted, channels
  widened to the locked **18 mm interior / 22 mm outer**; pixels at **~17 mm pitch** (~420 px for
  CHARGE; +22 bolt; 600 owned/ordered).
- Cross-section (locked): black 2 mm base + 1.2 black outer wall / 0.4 white liner + 0.8 white
  inner wall / 19 mm channel / 1.2 welded clear lens, baked fuzzy top (texture .dat swappable
  after the PETG fuzz bake-off). **All-PETG, 3-color** (black/white/clear → extruders 1/2/3).

## Panelization
- Generate the whole word, then cut into **~6 full-height pieces** along **corridor cuts**:
  top-to-bottom paths threaded entirely through black field, **≥5 mm clearance from any channel
  outer wall** — a seam never crosses a lit tube.
- **Flat butt joints**, ~0.12 mm clearance per cut face. No interlock tabs in v1 (wood rails do
  registration); optional printed back straps across a seam if needed.
- Panelizer must **verify every piece against the bed** (H2D 300×320; targets ≤296 short axis,
  ≤316 long axis) and fail loudly with dimensions if a piece won't fit.

## Wood frame (user-built; printed parts only interface with it)
- **Top + bottom horizontal rails** behind fixed bands; pieces screw to rail faces:
  **Ø4.5 screw holes, ≥2 top + 2 bottom per piece**, auto-placed in black field only.
  Black pan-head screws — invisible on the black face at distance.
- Rails lift the face **50–75 mm** → the cable plenum (pixel ~25 mm + ~85 mm folds hang loose).
  Free **Ø3.2 zip-tie hole pairs** along the path as transport insurance.
- Side verticals complete the rectangle; **PSU/controller board** on one side; **thin back skin**
  (hardboard/ply or printed) screwed to rails = anti-racking shear web. French-cleat or
  truss-mount the assembled box.

## Electrical
- **4-inch-pitch strings** chained in path order; jumpers with slack across piece seams.
- ~440 px ≈ 130 W at full white ≈ the 150 W/24 V PSU's edge → cap brightness ~80% or add a PSU.

## Pipeline (implementation scope)
1. **Extractor upgrade** (`tools/centerline.py`): graph-based segment decomposition (junction
   clusters, sliver-rung dropping) so the A extracts correctly; whole-word extraction from
   `CHARGE.eps` in one pass (all letters in shared word coordinates, cap 250 via H reference).
2. **Panelizer** (`tools/panelize.py`): clearance field on a coarse grid → corridor cuts between
   adjacent letters → piece regions, bboxes, bed-fit report; screw + zip-tie hole placement.
3. **Billboard generator** (OpenSCAD): continuous face from word paths; per-piece 3-color
   geometry clipped at cuts; per-piece 3MFs via `tools/make_3mf.py`.
4. **Cut preview** (web view): word bands + cut paths + piece dims/weights/pixel counts for
   approval BEFORE any geometry is rendered.
5. **Assembly map**: seams, screw positions, rail lines, wiring direction, per-piece stats.

## Estimates
~330 g and ~6–8 h per piece → **~2.0 kg, ~40 h print for CHARGE** (plus bolt).

## Later scope (explicitly deferred)
- **Bolt at logo proportion** (current `bolt2` print validates construction; final bolt is larger,
  gets its own board left of CHARGE, likely its own panelization).
- **Yellow accents** like the original billboard (yellow border tube, arrow, X-brace) — same
  channel construction with yellow/amber lensing or warm pixels; revisit after CHARGE.
- Full-billboard extras (TEDxFargo badge, 2026, truss dressing).

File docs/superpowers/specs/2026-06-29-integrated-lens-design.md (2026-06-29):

# Integrated lit-lens design — diffusion test matrix

**Date:** 2026-06-29
**Status:** implemented; STLs ready for a first print/eval pass
**Eventual goal:** a glowing **TEDxFargo** logo. These square cells are the optical
*coupon* — they find the cross-section (depth, mask, material split) that gives an
even, "sourceless" neon-style glow; that recipe then transfers to the letter-stroke
channels of the logo (the lightning-bolt work was the stroke-geometry precursor).

## Goal & principle

One **single-print, dual-material** cell that is *integrated* (no separate snap-in
lens, no assembly beyond inserting the pixel). The geometry simultaneously holds the
pixel, structures the light, and diffuses it. Primary visual target: **even sourceless
glow** (individual LED invisible), brightness second. Tension acknowledged up front:
"pull light forward" (brightness) and "scatter perfectly" (evenness) oppose each
other; the matrix samples several points on that trade-off.

## Hardware context

- **Printer:** Bambu **H2D**, dual independent nozzles → two materials co-printed in
  the same layer with minimal purge. Build vol (dual) 300×320×325; 350°C / 65°C chamber.
- **Material pair:** **white PETG + clear PETG** (same family → fused boundary; PETG
  heat-tolerant next to warm LEDs; ~95% white reflectance vs ~70% for white PLA).
- **Pixel:** 12mm bullet pixel, dome ~4mm above the plate (`dome_clear`), in the
  calibrated press-fit collar (`collar.scad`), bore Ø12.3.

## Cell architecture (`src/lens_cell.scad`)

Print **plate-down** (collar on bed, optic on top): no flip, **no chirality trap**
(see `[[chiral-flip-mirror-gotcha]]`), pixel inserts from the back afterward.

- **30mm interior square**, 2mm white walls (opaque → no cross-cell light bleed),
  6mm gaps, all tied to **one base slab** = a handleable tray.
- **Material split:** WHITE = base + walls + masks/reflectors (nozzle 1); CLEAR =
  face / fill / puck (nozzle 2). White and clear **abut with 0.1mm overlap** so the
  slicer fuses them.
- **Output:** two **co-registered** STLs — `stl/matrix_white.stl`, `stl/matrix_clear.stl`
  (same origin; verified bbox X −17..137, clear inset 1mm). Load both, assign nozzles,
  print as one job.
- **Labels:** each cell has *N* debossed dots on the tray bottom (cell index 1–8).

## Families & test matrix (8 cells, 4×2)

| # | Code | Family | Key params |
|---|---|---|---|
| 1 | A0 | Masked cavity — baseline | no mask, gap 15 |
| 2 | A1 | Masked cavity | **perforated white dot d14, 5mm above dome**, gap 15 |
| 3 | A2 | Masked cavity | perforated dot d16, gap 15 |
| 4 | A3 | Masked cavity — deeper | perforated dot d14, gap 18 |
| 5 | R1 | Reflector cone | white "volcano" around LED, gap 15 |
| 6 | B1 | Volumetric scatter | clear fill → **slice with ~15% gyroid infill**, gap 15 |
| 7 | C1 | TIR puck | clear + 90° center cone refractor, gap 15 |
| 8 | C2 | TIR puck | clear + 60° center cone refractor, gap 15 |

The **mask is perforated (~43% open), floated close to the LED** — this is the crucial
detail: it attenuates+recycles the central peak with a soft penumbra. An *opaque* mask
near the face creates a dark spot (see physics below). Family A is the workhorse; R/B/C
are exploratory points (efficiency vs evenness vs "alien" aesthetic).

## Research basis (sources)

- Hotspot masking → use **semi-transparent / perforated** masks, not opaque; reflective
  white dot recycles blocked light. [masking study](https://www.sciencedirect.com/science/article/abs/pii/S0030401813010419),
  [diffuser-dot patent](https://image-ppubs.uspto.gov/dirsearch-public/print/downloadPdf/11719978)
- Uniformity geometry: D/H ≈ 3 → uniformity > 0.88; gap/width ≈ 0.5 → **gap ≈ 15mm**.
  [panel design](https://www.researchgate.net/publication/286536701_Direct-down_LED_panel_light_design_for_uniform_illumination)
- White reflectance & per-bounce loss (~5%/bounce, compounding) → **white PETG**, keep
  bounce budget low. [reflector patent](https://image-ppubs.uspto.gov/dirsearch-public/print/downloadPdf/8740442)
- 3D-printed diffuser recipe: gyroid ~10–20%, few top layers, thin walls.
  [Adafruit neon](https://learn.adafruit.com/led-neon-signs-with-neopixels/3d-printing),
  [gyroid as diffuser](https://bigrep.com/posts/gyroid-infill-3d-printing/)
- TIR/batwing cone 60–90° spreads the forward beam sideways. [TIR optics](https://www.tandfonline.com/doi/full/10.1080/15980316.2019.1693436)

## Physics validation (2D Monte-Carlo, `analysis/cavity_sim.py`)

R_wall=0.92, 120k rays. peak/mean 1.0 = flat; CoV lower = more even.

| Config | Eff | peak/mean | CoV |
|---|---|---|---|
| A0 no mask | 94% | 1.21 | 14.8% |
| A1 perforated d14 | 82% | 1.07 | 5.0% |
| A2 perforated d16 | 81% | 1.07 | 6.4% |
| A3 perforated, gap18 | 81% | 1.06 | 5.2% |
| A1 *opaque* (contrast) | 66% | 1.22 | **center inverts → dark spot** |

Confirms: perforated dot flattens the hotspot (CoV 15→5%) at modest brightness cost;
opaque masking is the documented failure mode. 2D + idealized (no Fresnel/face
refraction) → trends/ranking, not absolute photometry.

## Known risks

- **A/R clear faces bridge ~30mm** (open cavity). Print with strong part cooling + a few
  solid top layers (Adafruit-proven). Minor sag is acceptable (adds diffusion). If it
  fails: add a 2mm crown or a clear cross-rib (round 2).
- **Perforations may clog** (over-extrusion shrinks holes) → would read as a dark center;
  fix by widening holes / pitch. The sim's opaque-contrast row is the tell.
- **C1 90° cone** sidewalls are at the ~45° self-support limit; C2 (60°) is safer.
- **B1** needs a per-object gyroid infill setting in the slicer (graceful: prints as a
  solid clear block if forgotten — still a diffuser, just not volumetric).

## Path to TEDxFargo

The winning cross-section (gap + mask/optic + white/clear split) becomes the channel
profile applied along the **TEDxFargo letter strokes** (stadium cross-section like the
bolt channel). Pixel pitch along strokes and per-letter wiring are later sub-projects.

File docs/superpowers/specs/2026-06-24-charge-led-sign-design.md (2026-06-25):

# CHARGE LED Sign — Parametric STL Generator

**Date:** 2026-06-24
**Status:** Approved (design); coupon fast-tracked for first print

## Goal

Generate 3D-printable STLs for an illuminated sign based on the TEDxFargo
"CHARGE" logo. Each letter is a channel-letter-style shell lit from behind by
12mm bullet pixels, with a clear printed diffuser face. Build the **CHARGE**
word first; the X/lightning bolt and other elements are stretch goals.

## Physical concept (per-letter stackup)

Front (viewer) → back (wall):

1. **Diffuser face** — clear filament; tunable thickness + slicer infill.
2. **Light-mixing air gap** — the main optical distance (LED tip → diffuser).
3. **Bullet pixel** — 12mm, press-fit nose-forward through a calibrated collar.
4. **Rear collar wall** — printed wall; collars merged in at each pixel.
5. **Mounting / wiring cavity** — room for wires + flat wall mount (later).
6. **Cover / backing panel** — separate, optional, added once optics work.

## Key decisions

- **Print strategy B (chosen):** print the shell *rear-wall-down* (collar holes
  flat on the bed for the crispest press-fit), front open; the **diffuser is a
  separate flat panel** that drops into / glues onto the front. This eliminates
  trapped supports and makes diffusers swappable for testing. Strategy A
  (one-piece, sparse transparent infill standing in for the air gap + support)
  is kept as a later optical experiment.
- **Collar:** `assets/bullet-collar.stl` is a pre-calibrated press-fit ring,
  OD 16mm, bore Ø12.19 necking to a Ø11.44 retention lip at mid-height, 2mm
  tall, **symmetric** (insertion direction agnostic). It is **merged (unioned)
  into the rear wall** at each pixel position; the wall gets a Ø12.3 clearance
  hole and the collar re-establishes the calibrated grip.
- **Toolchain:** **OpenSCAD**. Decisive because it natively imports the collar
  mesh and boolean-unions it at N positions, and exports STLs headlessly via
  CLI. (build123d/CadQuery rejected: poor mesh-STL booleans, would force
  re-modeling the collar and losing its calibration.)
- **Letters:** supplied as Illustrator EPS (vector). For OpenSCAD they must
  become SVG/DXF — export SVG from the `.ai` (preferred) or install
  `ghostscript`/`inkscape`. Not needed for the coupon.
- **Diffuser tuning split:** *thickness* = STL parameter (print slabs at
  1/2/3mm); *infill pattern/density* = Bambu Studio slicer setting on those
  slabs (gyroid/grid, top & bottom solid layers = 0 so the infill diffuses).
- **Pixel layout:** parameterized **density** — `pixel_pitch` along the path
  and `pixel_rows` across the stroke width (single centerline row for small
  letters; multiple rows when the stroke is wide).
- **Printer:** Bambu H2D (~350×320×325mm build volume). A single letter at
  ~300mm tall fits the bed.

## System architecture (OpenSCAD)

```
src/config.scad      all tunable knobs + derived values (the file you edit)
src/collar.scad      import bullet-collar.stl; place_collar(x,y)
src/diffuser.scad    diffuser_panel(thickness)
src/coupon.scad      depth-ladder test coupon
src/letter.scad      (later) outline -> shell -> collars -> rebate
src/pixel_layout.scad(later) outline/path -> pixel positions
src/main.scad        build entry point; selects part via -D part="..."
build.sh             openscad CLI -> exports STLs to ./stl/
assets/              bullet-collar.stl, *.eps, (later) *.svg
stl/                 generated output (git-ignored)
```

One module = one job. `build.sh` regenerates every STL from `config.scad`.

## Deliverable 1 — Stackup coupon (first print)

A single shared rear plate (2mm, on the bed, 3 merged collars) with **three
chimneys of different heights** = a depth ladder. Chimney heights set
`led_gaps` = 20 / 35 / 50mm clear LED-to-panel distance. Each chimney is a plain
open box; the diffuser panel **press-fits** straight into the opening
(`panel_press_clear` undersize), so panel thickness can vary freely and the
print stays support-free (every face is on the bed or an open top).

Print: 1 coupon body + diffuser panels at 1/2/3mm. Vary slicer infill on the
panels. Outcome: read distance × thickness × infill against each other, and
verify the real press-fit in a printed collar.

Tunables that matter: `dome_clear` (dome protrusion above the plate — measure on
the actual pixel), `led_gaps`, `panel_thicks`, `pixel_through`.

## Deliverable 2 — Mini "C" (150mm)

`C.svg` → `linear_extrude` open-front shell → `pixel_layout` places collars
along the stroke (`pixel_pitch`, `pixel_rows`) → front rebate → diffuser panel.
Applies the optical recipe found by the coupon and validates the EPS→collar
pipeline.

## Validation loop

Press a real pixel into a printed collar (calibration) → light it → compare
wells and panels → lock the recipe into `config.scad` → print the C.

## Pixel spec (measured from datasheet, 2026-06-25)

12mm bullet pixel: dome lens Ø8, barrel Ø12, flange+clip ring Ø13.6 × 2mm
thick, dome-tip→flange 5.5mm, flange→rear housing 13.5mm, overall 37mm. The
rear housing is wider than the flange and stays behind the rear wall. Collar
fit confirmed: Ø12 barrel through the Ø12.19 bore, Ø11.44 lip bites ~0.28mm/side,
Ø13.6 flange seats on the plate back. `dome_clear` set to 4.0mm.

## Cable management (constraint for the letter/cover, not the coupon)

Each pixel has molded leads; a few inches of cable + the rear housing (~13.5mm)
sit behind the rear wall. The mounting/wiring cavity and cover must allow:
rear-housing clearance + cable bend radius + a short service loop per pixel,
cable routing channels between pixels, an exit point, and tie-down/strain-relief
anchors. Leave ~15-25mm cavity depth as a starting point.

## Letter connection & mounting — chosen direction (detailed design deferred)

Join the letters with a **back spine / raceway** (option A). Chosen because it
solves spacing, cable routing, and wall-hanging in one move, and absorbs the
cover/backing.

- **Rail:** aluminum **2040 T-slot extrusion** (~1.5m for CHARGE). Stiffer than
  2020 over the span, holds ~2–3kg of letters without sag. Wood (1×3) is the
  budget fallback; a segmented printed rail is the all-printed fallback.
- **Attach:** two **printed bracket pads built into each letter's rear plate**
  (flat boss, counterbored Ø5.5 hole) → **M5 button-head screw** → **T-nut**
  dropped into the extrusion slot. Slide the letter to its mark, tighten,
  spacing locked. Removable / re-adjustable. Add a registration notch per
  letter position so spacing is foolproof.
- **Cables:** ride in a spare extrusion slot (slot clips / zip-ties). Controller
  + power injection can mount to the rail too.
- **Wall mount:** L-bracket or French cleat at each end → 2 anchors into studs;
  the whole word lifts on/off as one piece.
- **TODO when we return:** parametric `bracket` module (M5 + standard 2040
  T-nut dims); test-print one against a scrap of extrusion.

## Collar refinement ideas (STL is calibrated and works; change sparingly)

- Add an entry lead-in chamfer (~Ø13→Ø12.19 over 0.4mm) for easier starts —
  can be added in our model as a back-face countersink without editing the STL.
- If pixels pop out under cable tug, add a second lip / sharper cavity-side barb.
- If insertion force is too high at scale, switch the full lip to 3–4 discrete tabs.

## Open / deferred

- Confirm `dome_clear` by seating a real pixel and measuring protrusion.
- How literally to follow the neon-tube outline aesthetic vs. solid channel
  letters (a later letterform decision).
- EPS→SVG conversion path (Illustrator export vs. installed tool).
- Backing/cover, heat-sink posts, mounting features (after optics are proven).

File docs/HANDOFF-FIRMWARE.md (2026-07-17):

# TEDxFargo CHARGE — Firmware & Effects Handoff (2026-07-17)

**What this is:** the custom-effects subsystem, written to be picked up from a
clean session. 16 geometry-aware WLED effects run on the sign's word controller,
developed and QA'd in a bit-exact browser simulator, **flashed and confirmed on
hardware 2026-07-17**. The physical build is covered by `docs/HANDOFF.md`;
design rationale in `docs/superpowers/specs/2026-07-16-tedxfargo-effects-design.md`.

## 0. State at a glance
- **On the wall:** all effects working after OTA. 16 registered (Raider shelved
  behind `CHARGE_ENABLE_RAIDER`). Flash 85.4% of the 1.5 MB OTA slot — watch
  headroom as effects grow.
- **Two repos:** this one is the source of truth; the WLED clone
  (`~/workspace/WLED-charge`) is **disposable** — `sh tools/setup_wled.sh
  [--build]` rebuilds it from nothing (pins base commit `0e009863` of
  GLEDOPTO/WLED @ gledopto-16.0.1, patches the ini, syncs the usermod).
- **Everything lives in** `wled/usermods/tedxfargo/` + `sim/` + one ini line.
  WLED core is never modified.

## 1. The one-source-of-truth architecture
```
tools/gen_wiring.py ──► charge_geometry.h (PROGMEM tables: letter/col/row/height/xnorm
                        per chain index; letters are contiguous chain ranges)
wled/usermods/tedxfargo/charge_fx.h   ◄── ALL effect logic. No WLED includes.
        │                                  Compiled into BOTH targets:
        ├── tedxfargo.cpp + wled.h  ──► firmware (usermod; also registers the
        │                                8 goblin palettes as native usermod
        │                                palettes, IDs 255..248)
        └── sim/sim_main.cpp + sim/wled_shim.h ──► wasm simulator
```
The shim's fidelity tiers (in order): (1) **compile the real thing** —
`sim/vendor/fastled_slim.{h,cpp}` vendored byte-for-byte from the checkout;
(2) **verbatim ports with the source cited** — color_fade, color_blend,
ColorFromPalette, color_from_palette, loadPalette, allocateData; (3)
**documented approximations** — seeded PRNG, hash-based Random-Cycle palette.
Palette DATA is extracted from source by `sim/extract_palettes.py`, never
transcribed. **On WLED upgrade: re-vendor fastled_slim, re-run the extractor,
re-diff every cited port.**

## 2. Daily workflows
```bash
python3 sim/serve.py                  # sim at localhost:8000/sign-preview/simulator/
                                      #   (no-store headers — ALWAYS use this server;
                                      #    3 different stale-cache bugs died here)
sh sim/build.sh                       # rebuild wasm + refresh sim data files
sh sim/qa.sh                          # full QA (must stay green; see §4)
sh sim/test_native.sh                 # UBSan soak, 16 fx × 7 param corners × 20 min
sh tools/setup_wled.sh --build        # firmware build (also re-syncs the usermod)
node sim/render_dump.mjs DIR && python3 sim/render_sheets.py DIR
                                      # frame dumps + PNG contact sheets — LOOK at
                                      # them; visual review caught ~15 real issues
python3 tools/test_charge_geometry.py # geometry ↔ ledmap agreement (after regen)
```
**OTA:** upload `~/workspace/WLED-charge/build_output/release/WLED_16.0.1_GL-C-616WL.bin`
at `http://<device-ip>/update`. Via the device AP you must first uncheck the
same-subnet OTA guard (Config → Security & Updates). USB fallback:
`pio run -e GL-C-616WL -t upload`. Config/presets/ledmap survive OTA.

## 3. Hardware truths (each cost real debugging)
1. **Effects assume the clean full-canvas segment** — one segment, 0,0→134,25,
   grouping 1, spacing 0, reverse/mirror/transpose OFF. The device had
   reverse+spacing from an old preset → letters reversed + every-other-LED
   dark. Normalize in the UI, save as the boot preset.
2. **WLED recycles effect data buffers without zeroing.** Stateful effects
   (Pac-Man, Ants, Gravity tube-fall) MUST use magic-byte init guards
   (0x9C / 0xA7 / 0x6B) — `inited == 1` trusts garbage. The sim's zeroed pool
   cannot reproduce this class; only hardware shows it.
3. **WLED-macro collisions:** FX.h defines WHITE, GREY, RED, ORANGE, PINK…
   Locals with those names break ONLY the firmware build (the shim compiled
   fine both times it happened). Prefer `duskC`-style names.
4. **WLED's web UI caches effect metadata keyed by version** — both firmwares
   say 16.0.1, so hard-refresh the device UI after flashing or new
   sliders/checkboxes silently don't appear.
5. **Timeline effects must anchor to effect start** (`SEGENV.step` latch),
   never `now % total` — or selecting the effect joins mid-scene.
6. Effect **indices shift** when the registry changes → re-save any presets
   that reference effect IDs after flashing.

## 4. Effect-code rules (QA enforces most)
- Names start with **"CHARGE "** (QA-enforced). Metadata carries smart
  defaults; palette-aware effects declare `!,!,!;!` + a `pal=` default and keep
  **palette Default = the classic look** (Boot cyan, Lava classic, Storm
  electric…). `custom3` is WLED's 5-bit slider (0..31).
- **Frame-coherent randomness:** persistent choices come from `charge_hash()`
  of stable inputs; `hw_random8()` is for ephemeral flicker only. Timers
  compare wrap-safe: `(int32_t)(now - deadline) >= 0`.
- **Palette blend zones:** WLED palettes resample to 16 entries and always
  interpolate between adjacent entries, so hard-banded palettes (TEDx) have
  ~16/255-wide washed transitions. Deliberate color *picks* go through
  `charge_cfp_vivid()` (nudges to the nearest saturated hue);
  `charge_letter_colors()` also keeps adjacent letters visibly different.
  Continuous gradients (Flow trail, Dreamwave field) stay raw on purpose.
- Brightness falloffs: prefer **hold-bright quadratics** (`255 - t²/256`) —
  linear/ease-out curves read dim on the wall (Comet tails, firework sparks).
- QA (`sim/qa.mjs`) checks: name prefix, defaults, determinism, liveness, no
  writes to unmapped cells, **every declared param changes output** (with a
  dependent-param retry), millis-wrap survival, palette response, audio
  response. Add effects ⇒ keep it green; it has caught real bugs (undeclared
  Tube fall checkbox, invisible ants).

## 5. The 16 effects (30-second tour)
Ambient: **Boot** (neon ignition; Electrify lightning, per-letter palette
colors), **Surge** (packets + arc-flashes; Accumulate → Color wave finale),
**Comet**, **Marquee** (Color-mode slider), **Neon Morph**, **Lava**, **Flow**
(synced palette comets), **Dreamwave** (letters take turns "speaking").
Games/sims: **Pac-Man** (real rules, portals from tube geometry, magic-pellet
2D shockwaves), **Ants** (colony economy — piles = palette colors, rich
colonies glow their letter), **Gravity** (bounce + Tube-fall marble drain).
Particles: **Fireworks** (PS-1D-style physics; Grand dial c3 = whole-sign
showpiece w/ flood), **Drip**, **Pulse** (audio: device mic / sim beat+mic).
Stories: **Premiere** (~22 s film: right-side spotlight sweep → fills →
lightning → full-color blast) and **Storm** (rain forever; stepped-leader
lightning loads letters C→E; barrage + shockwave finale).

## 6. Where discussion lives
- Spec: `docs/superpowers/specs/2026-07-16-tedxfargo-effects-design.md`
  (§10 corrected: `custom_usermods = audioreactive tedxfargo` — the child env
  REPLACES the inherited value; the legacy define never compiled the mic in).
- Plan (executed through hardware acceptance):
  `docs/superpowers/plans/2026-07-16-tedxfargo-effects-firstcut.md`.
- Session memory: `memory/charge-led-sign-project.md` +
  `memory/wled-firmware-build-gotchas.md` (pio needs Python ≤3.13; pipx venv
  needs ensurepip).
- Deferred: bolt/board controller effects (same pattern ports directly),
  Raider revival, show control/sync, the multiplayer letter game.

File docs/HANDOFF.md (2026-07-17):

# TEDxFargo CHARGE — Sign Build Handoff (refreshed 2026-07-05, overnight bolt sprint)

**What this is:** a 3D-printed, LED-lit replica of the TEDxFargo CHARGE 2026 neon-billboard logo
(`assets/tedxfargo-full-logo.png`). White-reflector channels + frosted clear lenses, lit from
behind by 12 mm bullet pixels. Read top-to-bottom for full context; numeric truth lives in
`docs/locked-specs.md`; print/assembly steps in `docs/assembly-charge.md`.

> **Firmware / effects / simulator have their own handoff:** `docs/HANDOFF-FIRMWARE.md`
> (16 custom WLED effects, flashed and confirmed on hardware 2026-07-17).

## 0. State at a glance
- **CHARGE word: RESTORED to the APPROVED design (2026-07-05) — do not restyle.**
  A bridging experiment (closing the letterforms' open strokes) was built and then
  REVERTED at the user's direction: the open strokes ARE the font; "no gaps" applies to
  the BOLT BOARD ONLY. Word = the approved 454 px / original letterforms / original cuts.
  Pieces re-rendered from the restored data (identical inputs to what the user sliced);
  prints pending white PETG delivery. tools/bridge_word.py remains in the repo but MUST
  NOT be run on the word.
- **Bolt board: CONTINUOUS MODE, plates rebuilt 2026-07-05.** Element 6 (the logo's left
  panel) as ONE bridged closed loop + the billboard's red zigzag. 410×550 face, 4 plates;
  channels now CROSS the plate joints (no pullback breaks — user chose continuity over
  joint-free lenses); 7 hairline lens joints; one global fuzz field keeps texture continuous.
  137 px @20 mm, **sign total 591 px** (of EXACTLY 600 owned — hard inventory cap).
  `stl/board1..4_3color.3mf`. User approved the look; gaps feedback applied (BOLT ONLY);
  slicing pending.
- **PETG fuzz bake-off** (testboxes v3–v6, picks the lens texture): ready to print on the
  ~100 g white remnant; a texture change is a one-line .dat swap + clear-body re-render.
- Wood frame, wiring, mounting: user-built later; interface specs in the assembly card.

## 1. Locked build facts (never re-derive)
- Word: cap 250 mm uniform; face 1597×295; 6 pieces, corridor cuts through black only; auto-kern
  applied (A|R +1.2, R|G +5.9). Letters @17 mm pitch.
- Cross-section (word AND board): black 2 mm plate + 1.2 black outer wall / 0.4 white liner +
  0.8 white inner wall / 19 mm channel (18 interior) / 1.2 clear lens + baked **V8 texture**
  (jittered pyramid facets 2.0/0.6 mm, max-union tents, FLOATED 0.02 mm above the lens plane —
  no dead-band pass; see make_fuzz.py --mode=pyramid-jitter). ALL-PETG, 3 colors.
- Pixels: Ø12 bullets, flange Ø13.6 (**14.5 mm min spacing; 13.0–14.5 = snug/flange-snip**),
  collar `assets/bullet-collar.stl`. 4-inch strings.
- Bed truth (H2D, validated `stl/bedcheck_316x295.stl`): both-nozzle zone 316×295; place 295
  across, long side deep. Multi-color parts must sit between the nozzle bands.
- Slicing: 0.20 Standard + card overrides. LAYOUT (chosen 2026-07-05): black+clear on the
  RIGHT nozzle (AMS, black backup pair), white LEFT external; 3MF filament order 1=black,
  2=clear, 3=white. Only swap = black→clear ≈ z21 (flush 700–800 mm³); prime tower ON in
  the right-nozzle column; skirt/brim OFF.
- **PIXEL INVENTORY IS THE HARD CAP: user owns EXACTLY 600 (strings of 50).** Sign total
  **591** (word 454 + board 137 @20 mm) → 9 spares. Any change that adds pixels needs
  user sign-off. (Power is secondary: ~591 px also sits at the 150 W PSU's full-white
  edge → cap ~80% or add PSU.)

## 2. Bolt board — final design (element 6, C1 colorway)
- **Source truth:** `RedNeon/TEDx_RedNeon_6.psd` = the logo's left panel: flat-top bolt and X
  are ONE fused outline (one closed loop in art, painted with a neon break at the bolt-tail
  tip + two kiss-junctions where the tail weaves the X's top bar). Extraction:
  `assets/bolt_element6.pgm` → `tools/centerline.py --target-h 505` → `src/parts/boltx_data.scad`
  (3 open runs, 2,456 mm tube, centerline bbox 355×493, panel ≈ 2.06× letter cap — the
  deployed-logo proportion).
- **Red inner:** the billboard's red is a SINGLE-STROKE zigzag tube (not an outline): top tip →
  long diagonal down-left → flat bar right → long diagonal down to a tip just below the weave.
  Ours is 4 vertices, hand-fit to the billboard and clearance-audited legal (26 mm rule):
  `RED_PATH` in `tools/bolt_compose6.py` = (228,466)→(118,349)→(253,349)→(194,239) in boltx
  data coords. **Billboard-fidelity compromises (physics, not taste):** the bar can't tilt
  up-right (X-top-bar/notch-shelf corridor is exactly 0 mm at 22 mm bands) and the tail stops
  at y≈239 (wedge corridor pinches shut below). An 18 mm red band would buy only ~10 mm more
  tail — not worth a second cross-section.
- **Board:** 410×550, content margins ~17 mm. **Piecewise seams** (a full-height vertical seam
  cannot avoid grazing the X's near-vertical legs): y=255 full width, then top row splits at
  x=126, bottom row at x=153. Plates B1 153×255 / B2 257×255 / B3 126×295 / B4 284×295 — all
  fit 316×295. **CONTINUOUS MODE (2026-07-05):** channels cross the joints — 7 hairline lens
  joints instead of pullback breaks; graze/corner checks still gate seam placement;
  ONE global fuzz field (fuzz_board_global.dat).
- **SEAM STRAPS (2026-07-10, spec docs/superpowers/specs/2026-07-10-seam-bracket-design.md):**
  4 white PETG splice straps (S1+S2 y=255 butt @145.5 / S3 x=126 / S4 x=153; 48 wide, 4 web +
  8 rails, ~226 g) behind the seams REPLACE the y-seam wood rail. Plates screw to them with
  M4×8 + captive hex nuts (23); frame catches PERIMETER wood screws only (14). Straps carry
  Ø17 pass-holes for near-seam pixel bodies, leg sockets (Ø10.2 ×3, empty until sag says
  otherwise), and TWO embedded collars.
- **Pixels:** 137 (116 yellow / 21 red) @21.5 mm pitch, ANCHORED at the 7 seam crossings
  (straddle pinned at ±9.5 mm perpendicular, keepout floor 9.5 — 1.5 mm collar web).
  The two shallow crossings (31°/29°) pin the pixel ON the seam: collars live in the straps,
  plates get Ø13 bites, pixel seats 2 mm deeper (inside the 10–20 optics window). Worst
  seam-adjacent gap 23.5 mm (was 34–58). Assembly is BRACKETS-FIRST, then pixels through the
  strap holes (printed pusher) — wires always route behind. `src/parts/bolt_pixmap.json` =
  color zone + plate + `mount` (plate|bracket) + chain (136 links, jumpers at 86/107).
  Review page: docs/sign-preview/bracket-preview.html (tools/gen_bracketpreview.py).
- (Historic note: the earlier pullback design read as 4 aligned breaks across the X's waist;
  superseded by continuous mode per user feedback.)

## 3. Pipeline (all committed, reproducible)
Word: `tools/centerline.py` → `tools/panelize.py` → `tools/gen_pieces.py` →
`src/parts/piece.scad` → `build_pieces.sh` → `tools/make_3mf.py` (manifold audit inline).
Word bridging: `tools/bridge_word.py` (letters -> closed loops, in word_cuts.json).
Board: `tools/bolt_compose6.py` (bridge + piecewise seam scan, CONTINUOUS mode; graze check,
corner keepout, tangent-apex rejection) → `tools/boltboard.py` (anchored seam-crossing
placement, pitch auto-solved to the 137 budget; channel-aware seam screw pairs; emits
board_layout + bracket_layout + pixmap; zip-ties removed 2026-07-06 — light leaks) →
`src/parts/bolt_piece.scad -D PIECE=1..4 -D COL=1..3` + `src/parts/bracket.scad -D STRAP=1..4`
→ `build_board.sh` (plates, straps, pusher).
Audits: `tools/clearance_audit.py` (26 mm channel rule with crisp-crossing exemption — run it
on any new path vs the yellow), `tools/bolt_preview.py` (fast raster comps).
Letter pixel truth: `src/parts/word_cuts.json` (454). Board: `bolt_el6.json` + pixmap.

## 4. Morning-review queue (user)
0. The overnight review artifact (lit-sign render, billboard gate-check, physics notes,
   iteration verdicts, wiring chain, print queue, phase-2 accents teaser):
   https://claude.ai/code/artifact/1eb4e351-e13a-43f7-a56d-8fafd92376fa
1. Look at `docs/sign-preview/full-sign.html` (regenerate: `python3 tools/gen_preview.py`)
   and the artifact — composition, seams, red shape.
2. If the red gesture or seam positions want tweaking: edit `RED_PATH` / re-run composer
   (the seam scanner re-picks automatically), then `boltboard.py`, then `build_board.sh`.
3. Slice `stl/board1..4_3color.3mf` in the GUI (same 0.20 process as the word; plates are
   smaller). Note: Bambu's headless CLI was probed overnight — it only slices project 3MFs
   with plate metadata and silently no-ops on our geometry 3MFs, so GUI import remains the
   flow (our 3MFs load as ONE co-registered multi-part object, verified).
4. Bolt-vs-word hang alignment is a frame decision (word band currently centered on 550).

## 5. Non-obvious gotchas (hard-won, keep)
- Skeleton tips have no degree-1 endpoints (ZS clumps) → open/closed by walk behavior.
- The art paints breaks as notches; element 6's outline is 3 open runs, not a closed loop —
  two of the six ends are kiss-junctions that FUSE in the 22 mm band (by design).
- A vertical seam through this art almost always grazes a steep stroke — the graze check in
  bolt_compose6.py is what makes seams legal; don't bypass it. (Historic pullback-mode note:
  pullbacks must be perpendicular-normalized, arc = 13/sin θ.)
- Fuzz heightfields near the lens plane make CGAL micro-slivers → 0.02 floor + off-lattice
  base (0.1504) + ±50 µm dead-band; `make_3mf.py` audits every mesh.
- Bambu: "filament change times" on H2D = free per-layer nozzle swaps, not purges. 3MF-imported
  filaments are unbound until synced; verify mapping in the send dialog. AMS backup = identical
  preset+color in two slots on the SAME side. Left nozzle has no AMS (weigh before big blacks).
- Nesting two 22 mm channels needs ≥26 mm centerline gap; long parallel sub-26 = rejected mush;
  crisp crossings/pockets = accepted (letter-A precedent). `clearance_audit.py` encodes this.
- OBSOLETE (deleted 2026-07-05): el-5 bolt artifacts (bolt5*_data, bolt_final2.json c1/c2,
  bolt_c1_clean.json, old 2-plate board*_c* STLs/3MFs, tools/bolt_compose.py). Element 5
  turned out to BE the red inner's slim-bolt shape, not the panel outline.

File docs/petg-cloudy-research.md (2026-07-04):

# Making transparent PETG print CLOUDY (for LED diffusion)

Research summary (2026-07-01). Goal: take on-hand *clear* PETG and make it milky/diffusing.

> **UPDATE 2026-07-02:** in practice, slicer-setting adjustments made **no noticeable difference**
> for us — the project's cloudiness lever is now **baked lens geometry** (the fuzz-texture ladder,
> `tools/make_fuzz.py`; V5 chunky + V6 two-scale added for the PETG bake-off). All-PETG decided.
> The settings recipe below is kept for reference; the white-skin-over-clear V2 lens remains the
> fallback if geometry alone isn't milky enough.

**Mechanism:** haze = light scattering at internal air↔plastic interfaces (unfused
bonding-neck gaps, micro-voids, moisture bubbles; air n≈1.0 vs PETG n≈1.57, same physics
as frosted glass). To make PETG cloudy you **maximize** those interfaces — the exact
inverse of every "crystal-clear PETG" recipe.

## Ranked methods (best → worst for an *even* milky glow)

| # | Method | Setting | New filament? | Notes |
|---|---|---|---|---|
| 1 | **Textured PEI plate, face-DOWN** | use the H2D's textured plate; print diffuser face against it | **No** (own it) | Most *even*, zero tuning. Frosts only the face touching the plate — but our lens already prints face-down, so it's free. |
| 2 | **Under-extrude** | flow **~88–92%** (start 90%, lower = more haze) | **No** | Even *volumetric* haze through the whole wall; stacks with #1. Don't go so low layers fail/weaken. Test. |
| 3 | **Cooler nozzle** | **~225–235°C** (vs 240–260 for clarity) | **No** | Incomplete fusion → voids. Modest lever; non-monotonic (too hot also hazes). Too cold → blotchy. |
| 4 | **High part-cooling fan** | **80–100%** (vs 0% for clarity) | **No** | Locks in layer boundaries. Weak effect ("a bit milky") and can be uneven. |
| 5 | **Fast print speed** | above the ~20mm/s clarity setting | **No** | ⚠ Least reliable — the peer-reviewed study found faster = *clearer*, and it adds uneven ringing. Don't lead with it. |
| — | **Wet/undried PETG** | skip drying | No | ❌ Not recommended — real mechanism (steam microbubbles) but uncontrolled, blotchy, weakens the part. |

**Recommended starting recipe (H2D, clear PETG):** face-**down** on the textured plate +
flow **~90%** + nozzle **~230°C** + fan **~100%**; dial flow down further for more milk.

## Refuted / not a lever
- **Layer height** — NOT a reliable lever. The study found **0.2mm = peak clarity**; both
  thinner *and* thicker transmit less, so "thicker = cloudier" is false. Don't rely on it.

## Untested here (no verified evidence — treat as unknown)
- Infill pattern/gyroid volumetric scatter behind a thin skin; top/bottom/wall counts
- Fuzzy skin on the diffuser face
- Matte/frosted PETG or diffusion-additive filament
- Post-processing: sanding, bead/sand blasting, matte clear-coat spray, solvent vapor
  (note: PETG is largely **acetone-resistant**, so ABS-style vapor smoothing likely won't work)
- Bed temperature effect on face clarity

## How this fits our project
- If the **PLA heat test passes**, PLA is cloudy for free → this is moot.
- If heat forces **PETG**, two paths: (a) the **white-skin-over-clear** trick (V2 lens) —
  the white layer does the diffusing, so PETG's clarity no longer matters (likely simplest);
  or (b) make the PETG itself cloudy via the recipe above (no second filament needed).
- **Free win regardless of material:** the lens already prints face-down, so using the
  **textured plate** frosts the viewer face automatically.

Sources: [CNC Kitchen](https://www.cnckitchen.com/blog/transparent-fdm-3d-prints-are-clearly-stronger) ·
[Bambu wiki](https://wiki.bambulab.com/en/knowledge-sharing/transparent-petg) ·
[NCSU BioResources 2024](https://bioresources.cnr.ncsu.edu/resources/effect-of-slicing-parameters-on-the-light-transmittance-of-3d-printed-polyethylene-terephthalate-glycol-products/) ·
[3DBite](https://3dbite.com/transparent-glass-like-3d-prints-petg-pla-settings/) ·
[Hackaday](https://hackaday.com/2025/11/29/how-to-print-petg-as-transparently-as-possible/)

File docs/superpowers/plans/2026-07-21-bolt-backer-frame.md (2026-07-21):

# Bolt Backer Frame Implementation Plan

> **For agentic workers:** REQUIRED SUB-SKILL: Use superpowers:subagent-driven-development (recommended) or superpowers:executing-plans to implement this plan task-by-task. Steps use checkbox (`- [ ]`) syntax for tracking.

**Goal:** Generate and render every part of the printed torsion-box frame for the
bolt board (spec `docs/superpowers/specs/2026-07-21-bolt-backer-frame-design.md`),
with layout-level asserts, QA checks, build lines, and a committed web preview.

**Architecture:** A new generator `tools/boltframe.py` reads the existing
`board_layout.scad` / `bracket_layout.scad` (source of truth for plates, pixels,
screws, straps) and emits `src/parts/frame_layout.scad` + runs clearance
asserts. Three OpenSCAD part files consume it: `frame.scad` (4 corner-L rail
segments, `-D SEG=`), `frame_panel.scad` (4 vented quadrant panels,
`-D PANEL=`), `frame_parts.scad` (handle/foot/leg/key/gland-plate/trim/coupon,
`-D PART=`). The strap part `bracket.scad` gains two `-D`-able params
(`bk_rail_h`, `bk_nut_pocket`) so the S3/S4 reprint builds tall flat-seat
variants from the SAME source. QA and preview follow the house pattern.

**Tech Stack:** Python 3 (no deps), OpenSCAD CLI, existing qa_board.py probe
helpers (`read_stl`, `vset`, `ring_r`).

## Global Constraints

- Board 410 × 550; plate back = z 0, cavity grows +z; plate front at z −2.
- CLR 0.5, WALL 3.0, CAVITY 36.0, PANEL_T 2.4, WALL top 38.4 (= 36 + 2.4).
- FLANGE 16 wide × 4 thick (z 0..4); LEDGE 8 wide × 4 thick (z 32..36).
- Frame outer rect −3.5..413.5 × −3.5..553.5; segment joints at x=205, y=275.
- **Print orientation decision (amends spec):** rails print FLANGE-DOWN
  (flange + tray floors on the bed, wall rising 38.4, 45° chamfer under the
  ledge). The 2 mm reveal lip therefore CANNOT be part of the rail — it is a
  separate snap-on **trim strip** (PART=6); `reveal=0` = don't print trim.
- Straps S3/S4 rebuild with `-D bk_rail_h=32 -D bk_nut_pocket=0` (web 4 +
  32 = 36); S1/S2 untouched.
- Chirality insurance: every mirrored-part lesson applies — tray hole
  patterns get a 1.2 mm printable COUPON (PART=7) and `ctl_diag` / PSU
  patterns stay parametric until the coupon is verified against the units.
- Bed cap 316 × 295. All M3 pilots Ø2.8, boss OD 7. White PETG.
- Commit after every task; `openscad` binary from PATH (as build_board.sh).

---

### Task 1: `tools/boltframe.py` — layout generator with clearance asserts

**Files:**
- Create: `tools/boltframe.py`
- Output (generated): `src/parts/frame_layout.scad`

**Interfaces:**
- Consumes: `src/parts/board_layout.scad` (`bb_scr`, `bb_px`, `bb_bite`),
  `src/parts/bracket_layout.scad` (`bk_span`, `bk_socket`).
- Produces `frame_layout.scad` variables (all consumed by Tasks 3–5, 6, 8):
  `fr_face, fr_clr, fr_wall, fr_cavity, fr_panel_t, fr_flange_w, fr_flange_t,
  fr_ledge_w, fr_ledge_t, fr_reveal, fr_boss` (14 pts), `fr_joint` (=[205,275]),
  `fr_panels` (4 rects), `fr_panel_scr` (per-panel [x,y] lists),
  `fr_ledge_boss, fr_rail_boss` (S3/S4 rail-top pts), `fr_leg` (3 pts),
  `fr_tray_psu, fr_psu_holes` (6 pts), `fr_tray_ctl, fr_ctl_holes` (2 pts),
  `fr_gland` (=[cy, cz]), `fr_handle` (2 spans + bolt xs), `fr_feet` (2 xs),
  `fr_vent_rows`, `fr_mic` (=[367,470]).

- [ ] **Step 1: Write the generator** — full content:

```python
#!/usr/bin/env python3
"""Backer-frame layout for the bolt board (spec 2026-07-21).
Reads board_layout/bracket_layout (truth), emits frame_layout.scad.
Every placement is asserted against the pixel map — the lower-left PSU
lesson: never place cavity equipment without sweeping bb_px."""
import math, re

def grab(txt, name):
    return eval(re.search(name + r"\s*=\s*(\[.*?\]);", txt, re.S).group(1))

bl = open("src/parts/board_layout.scad").read()
bk = open("src/parts/bracket_layout.scad").read()
SCR, PX, BITE = grab(bl, "bb_scr"), grab(bl, "bb_px"), grab(bl, "bb_bite")
SOCK = grab(bk, "bk_socket")
FW, FH = 410.0, 550.0
CLR, WALL, CAV, PT = 0.5, 3.0, 36.0, 2.4
FLW, FLT, LGW, LGT, REV = 16.0, 4.0, 8.0, 4.0, 2.0
JX, JY = 205.0, 275.0
PXPTS = [(p[0], p[1]) for p in PX] + [tuple(b) for b in BITE]

def rect_px_clear(r, need, what):
    x0, y0, x1, y1 = r
    d = min(math.hypot(max(x0-x, 0, x-x1), max(y0-y, 0, y-y1))
            for x, y in PXPTS)
    assert d >= need, f"{what}: {d:.1f} < {need} to a pixel"
    return d

# 14 frame bosses = the wood-screw band (validated keepout)
boss = [(s[0], s[1]) for s in SCR if s[2] == 0]
assert len(boss) == 14, "expected 14 perimeter wood-screw points"
for x, y in boss:   # reveal lip (trim) never covers a hole rim
    e = min(x, y, FW - x, FH - y)
    assert e - 2.25 >= REV + 0.5, f"lip too close to screw at {(x,y)}"

# trays (verified zones; see spec)
TRAY_PSU = (1.0, 415.0, 98.0, 544.0)
TRAY_CTL = (342.0, 405.0, 392.0, 534.0)
rect_px_clear(TRAY_PSU, 11.0, "PSU tray")
rect_px_clear(TRAY_CTL, 10.5, "controller tray")
S3L = 126 - 24          # S3 raised-rail outer edge
assert TRAY_PSU[2] <= S3L - 3.5, "PSU tray must clear S3's raised rail"
assert 4 + 30 + 2 <= CAV, "PSU (30) + floor (4) + 2 clear must fit cavity"

# PSU bottom-hole patterns (Mean Well datasheets; L=3.0 max depth).
# Portrait, terminal end DOWN, case corner at tray corner (x0, y0):
# (w_off across x, l_off along y) per model.
x0, y0 = TRAY_PSU[0], TRAY_PSU[1]
psu = {"LRS-50":  [(40.5, 20.5), (40.5, 75.5)],
       "LRS-75":  [(45.5, 20.5), (45.5, 75.5)],
       "LRS-100": [(34.0, 78.0), (67.0, 78.0)]}
psu_holes = [(round(x0+w, 2), round(y0+l, 2)) for m in psu.values() for w, l in m]
for i in range(len(psu_holes)):     # union pattern must not merge bores
    for j in range(i+1, len(psu_holes)):
        assert math.dist(psu_holes[i], psu_holes[j]) >= 5.5, "PSU holes collide"

# Elite shell screws: ±61 along length, ±13 across width (probed from
# docs/elite2d_mount.stl). ctl_diag flips the diagonal after coupon check.
ctl_diag = 1
cx, cy = (TRAY_CTL[0]+TRAY_CTL[2])/2, (TRAY_CTL[1]+TRAY_CTL[3])/2
ctl_holes = [(round(cx - 13*ctl_diag, 2), round(cy - 61, 2)),
             (round(cx + 13*ctl_diag, 2), round(cy + 61, 2))]

# panel quadrants + fixing points
panels = [(0, 0, JX, JY), (JX, 0, FW, JY), (0, JY, JX, FH), (JX, JY, FW, FH)]
ledge_c = 3.5           # ledge boss centerline, inboard of plate edge
ledge_boss = ([(x, ledge_c) for x in (60, 150, 260, 350)]          # bottom
            + [(x, FH - ledge_c) for x in (60, 150, 260, 350)]     # top
            + [(ledge_c, y) for y in (120, 210, 340, 395)]         # left
            + [(FW - ledge_c, y) for y in (120, 210, 340, 470)])   # right
for p in ledge_boss:    # bosses must not sit inside a tray footprint
    for r, nm in ((TRAY_PSU, "PSU"), (TRAY_CTL, "ctl")):
        assert not (r[0]-4 < p[0] < r[2]+4 and r[1]-4 < p[1] < r[3]+4), \
            f"ledge boss {p} inside {nm} tray"
rail_boss = ([(126 - 21.5, y) for y in (330, 470)]     # S3 raised rails
           + [(126 + 21.5, y) for y in (330, 470)]
           + [(153 - 21.5, y) for y in (60, 190)]      # S4
           + [(153 + 21.5, y) for y in (60, 190)])
legs = [(q[0], 255.0) for s in SOCK for q in s]
assert len(legs) == 3, "expected 3 S1/S2 leg sockets"
supports = ledge_boss + rail_boss + legs
pscr = [[p for p in supports
         if r[0] - 1 <= p[0] <= r[2] + 1 and r[1] - 1 <= p[1] <= r[3] + 1]
        for r in panels]
for i, ps in enumerate(pscr):
    assert len(ps) >= 6, f"panel {i+1} has only {len(ps)} fixings"

# gland (left wall, low), handles (top rail), feet (bottom rail)
GLAND = (70.0, 19.0)            # (y along wall, z up the wall) hole center
assert not (TRAY_PSU[1] - 30 < GLAND[0] < TRAY_PSU[3]), "gland under PSU tray"
HANDLE = [(60, 150, 65, 145), (260, 350, 265, 345)]   # span x0,x1, bolt xs
for h in HANDLE:
    assert not h[0] < JX < h[1], "handle crosses the top joint"
FEET = [105.0, 305.0]
vent_rows = {"intake": [14, 23, 32, 41, 50], "exhaust": [500, 509, 518, 527, 536]}
MIC = (367.0, 470.0)

def fmt(pts):
    return "[%s]" % ",".join("[%.2f,%.2f]" % (p[0], p[1]) for p in pts)

with open("src/parts/frame_layout.scad", "w") as f:
    f.write("// AUTO-GENERATED by tools/boltframe.py — backer frame layout\n")
    f.write("// Board coords, z=0 at plate BACK, +z into the cavity.\n")
    f.write("fr_face=[%.1f,%.1f]; fr_clr=%.1f; fr_wall=%.1f; fr_cavity=%.1f;\n"
            % (FW, FH, CLR, WALL, CAV))
    f.write("fr_panel_t=%.1f; fr_flange_w=%.1f; fr_flange_t=%.1f;\n"
            % (PT, FLW, FLT))
    f.write("fr_ledge_w=%.1f; fr_ledge_t=%.1f; fr_reveal=%.1f;\n"
            % (LGW, LGT, REV))
    f.write("fr_joint=[%.1f,%.1f];\n" % (JX, JY))
    f.write("fr_boss=%s;\n" % fmt(boss))
    f.write("fr_panels=[%s];\n" % ",".join(
        "[%.1f,%.1f,%.1f,%.1f]" % p for p in panels))
    f.write("fr_panel_scr=[%s];\n" % ",".join(fmt(ps) for ps in pscr))
    f.write("fr_ledge_boss=%s;\n" % fmt(ledge_boss))
    f.write("fr_rail_boss=%s;\n" % fmt(rail_boss))
    f.write("fr_leg=%s;\n" % fmt(legs))
    f.write("fr_tray_psu=[%.1f,%.1f,%.1f,%.1f];\n" % TRAY_PSU)
    f.write("fr_psu_holes=%s;\n" % fmt(psu_holes))
    f.write("fr_tray_ctl=[%.1f,%.1f,%.1f,%.1f];\n" % TRAY_CTL)
    f.write("fr_ctl_holes=%s;\n" % fmt(ctl_holes))
    f.write("fr_gland=[%.1f,%.1f];\n" % GLAND)
    f.write("fr_handle=[%s];\n" % ",".join(
        "[%.1f,%.1f,%.1f,%.1f]" % h for h in HANDLE))
    f.write("fr_feet=[%.1f,%.1f];\n" % tuple(FEET))
    f.write("fr_vent_intake=%s;\n" % vent_rows["intake"])
    f.write("fr_vent_exhaust=%s;\n" % vent_rows["exhaust"])
    f.write("fr_mic=[%.1f,%.1f];\n" % MIC)
print("frame_layout: 14 bosses, %d PSU holes, %d panel fixing sets — asserts OK"
      % (len(psu_holes), len(pscr)))
```

- [ ] **Step 2: Run it** — `python3 tools/boltframe.py`
Expected: `frame_layout: 14 bosses, 6 PSU holes, 4 panel fixing sets — asserts OK`
- [ ] **Step 3: Negative test** — temporarily set `TRAY_PSU = (22,55,121,137)`
  (the failed lower-left zone), rerun, expect `AssertionError: PSU tray: 0.0 <
  11` — then restore. This proves the sweep guards.
- [ ] **Step 4: Commit** — `git add tools/boltframe.py src/parts/frame_layout.scad
  && git commit -m "feat: backer-frame layout generator with pixel-sweep asserts"`

### Task 2: tall flat-seat S3/S4 straps

**Files:**
- Modify: `src/parts/bracket.scad` (params + conditional nut pocket)
- Rebuild: `stl/strap_s3.stl`, `stl/strap_s4.stl`
- Modify: `tools/qa_board.py` (strap C-section knows tall/flat variants)

**Interfaces:**
- Produces: `bk_rail_h` / `bk_nut_pocket` as `-D`-able params; S3/S4 STLs
  become web 4 + rail 32 with plain Ø4.5 bores (flat z=4 seat, no hex).

- [ ] **Step 1: Parameterize bracket.scad** — change the two constants:

```scad
bk_rail_h    = 8.0;   // stiffening rails above the web (-D 32 for frame)
bk_nut_pocket = 1;    // 1 = captive hex (as-built S1/S2); 0 = flat seat
```

and make the nut cut conditional:

```scad
        for (q = bk_nut[i]) translate([q[0], q[1], 0]) {
            translate([0, 0, -0.1])
                cylinder(h = bk_web_t + bk_rail_h + 0.2, d = bk_scr_d);
            if (bk_nut_pocket)
                translate([0, 0, bk_web_t - bk_nut_t])
                    cylinder(h = bk_nut_t + 0.1, d = bk_nut_af / cos(30), $fn = 6);
        }
```

(bore extended through any rail the screw line crosses — harmless when clear.)
- [ ] **Step 2: Rebuild tall straps**
`for S in 3 4; do openscad -D STRAP=$S -D bk_rail_h=32 -D bk_nut_pocket=0 -o stl/strap_s${S}.stl src/parts/bracket.scad 2>stl/strap${S}.log; done`
- [ ] **Step 3: Probe** — max z == 36.0; screw bores present as Ø4.5 rings at
  z=0; NO hex ring at z 0.7–0.9 (reuse qa ring_r via a one-liner or the
  scratch probe script).
- [ ] **Step 4: Teach QA the variants** — in qa_board.py section C, replace the
  unconditional hex probe with:

```python
TALL = {"S3", "S4"}          # tall flat-seat frame variants
rail_h = 32.0 if name in TALL else 8.0
...
        rh = ring_r(verts, q[0], q[1], 0.7, 0.9, 6, rmin=3.0)
        if name in TALL:
            if rh is not None:          # flat seat: hex must be ABSENT
                bad.append(("hex-should-be-flat", q, rh))
        elif rh is None or not 3.4 <= rh <= 4.3:
            bad.append(("hex", q, rh))
```

and assert strap height: `zmax = max(v[2] for v in verts)` == `bk_web_t + rail_h`
(±0.1) as a new per-strap check.
- [ ] **Step 5: Run** `python3 tools/qa_board.py` — expect all PASS (45 checks:
  43 + 2 height checks fold into existing strap lines is fine either way).
- [ ] **Step 6: Commit.**

### Task 3: `src/parts/frame.scad` — 4 corner-L rail segments

**Files:**
- Create: `src/parts/frame.scad` (`-D SEG=1..4`; 1=BL, 2=BR, 3=TR, 4=TL)

**Interfaces:**
- Consumes: every `fr_*` from frame_layout.scad.
- Produces: `stl/frame_seg1..4.stl`, printable flange-down, bbox ≤ 316×295.

- [ ] **Step 1: Write frame.scad** — model the FULL frame in board coords
(z per Global Constraints), then clip per segment and lay flat. Core:

```scad
include <frame_layout.scad>
SEG = 1;
ox0=-fr_clr-fr_wall; ox1=fr_face[0]+fr_clr+fr_wall;
oy0=-fr_clr-fr_wall;  oy1=fr_face[1]+fr_clr+fr_wall;
wz1 = fr_cavity + fr_panel_t;          // wall top 38.4
in0x=-fr_clr; in1x=fr_face[0]+fr_clr;  // wall inner faces
in0y=-fr_clr; in1y=fr_face[1]+fr_clr;

module ring(w) difference() {          // outer perimeter band, width w inboard
    translate([ox0,oy0]) square([ox1-ox0, oy1-oy0]);
    translate([ox0+w,oy0+w]) square([ox1-ox0-2*w, oy1-oy0-2*w]);
}
module frame_body() {
    linear_extrude(wz1) ring(fr_wall + fr_clr);                  // walls
    linear_extrude(fr_flange_t) ring(fr_wall + fr_clr + fr_flange_w); // flange
    translate([0,0,fr_cavity-fr_ledge_t]) linear_extrude(fr_ledge_t)
        ring(fr_wall + fr_clr + fr_ledge_w);                     // ledge
    hull_ledge_chamfer();
    tray_floors(); boss_pads();
}
```

with these features (each a module, subtracted or unioned as appropriate):
- `hull_ledge_chamfer()` — 45° wedge under the ledge ring (printable shelf).
- `tray_floors()` — PSU rect + controller rect, z 0..4, merged to the walls.
- 14 flange bosses: cylinder Ø7 z 0..4 at `fr_boss` + Ø2.8 pilot z −0.1..4.1
  (bosses live INSIDE the flange band — union then drill).
- ledge bosses at `fr_ledge_boss`: Ø7 columns z 4..fr_cavity, Ø2.8 pilot from
  the top, 8 deep.
- tray drills: `fr_psu_holes` Ø2.8 through floor; `fr_ctl_holes` Ø3.2.
- gland: on the LEFT wall at y `fr_gland[0]`, z `fr_gland[1]`: outer-face
  recess 45×30×1.5, through-opening 36×22, two Ø2.8 pilots at y ±20.
- handle pads: top wall inner face, 20×12 pads z wz1−12..wz1 at `fr_handle`
  bolt xs, Ø3.4 pilot bored 10 down from the top face.
- feet pads: bottom wall inner, 36×12 pads z 0..14 at `fr_feet`, T-slot cut
  from below: stem 10.4×3.2 + cross 16.4×3.2, 9 deep.
- dovetail joints at x=fr_joint[0] (top+bottom) and y=fr_joint[1] (sides):
  bowtie pocket 24×14×5 recessed into the wall inner face spanning the cut,
  Ø2.8 pilot each side for the key screws.
- trim groove: 1.6×2 groove in the wall front edge (z −? n/a — wall starts
  z 0; groove in the wall OUTER face at z 0..3, 1.2 deep) for the snap trim.
- segment clip: `intersection()` with the quadrant box for SEG (split at
  fr_joint), then `translate` so bbox min = origin (print plate placement).
- [ ] **Step 2: Render all 4** — `for G in 1 2 3 4; do openscad -D SEG=$G -o
  stl/frame_seg$G.stl src/parts/frame.scad 2>stl/frameseg$G.log; done`
- [ ] **Step 3: Probe** — per segment: manifold (log "Simple: yes"), bbox ≤
  316×295×38.5, flange-boss rings found at the expected subset of `fr_boss`
  (transformed by the same clip translate — emit the offset in a comment line
  of frame_layout or derive: segment 1 offset = (−ox0, −oy0)).
- [ ] **Step 4: Commit.**

### Task 4: `src/parts/frame_panel.scad` — 4 vented quadrant panels

**Files:**
- Create: `src/parts/frame_panel.scad` (`-D PANEL=1..4`)

**Interfaces:**
- Consumes: `fr_panels`, `fr_panel_scr`, `fr_vent_*`, `fr_mic`, `fr_joint`.
- Produces: `stl/frame_panel1..4.stl`, flat prints, outside face down.

- [ ] **Step 1: Write it** — per panel: 2.4 skin sized to its quadrant minus
  0.3 edge clearance, +half-lap rebates (6 wide, 1.2 deep — panels 1,3 carry
  the lap on top of the x=205 edge, panels 2,4 the underside; same for
  y=275 between 1↔3, 2↔4), rib grid 4×8 on 60 pitch on the inside face,
  Ø3.4 screw holes countersunk at its `fr_panel_scr` points, louver rows
  (`louver()` = 22×2.6 slit + 45° interior hood, open DOWNWARD in sign
  orientation): intake rows on panels 1–2 at `fr_vent_intake` y's, exhaust
  on 3–4 at `fr_vent_exhaust`; mic cluster on panel 4 (contains `fr_mic`):
  5×5 grid of Ø2.5 at 6 mm pitch centered on `fr_mic`... panel 4 is
  x>205 — `fr_mic=(367,470)` lives in panel 4 ✓.
- [ ] **Step 2: Render 4 panels; probe** bbox ≤316×295, screw holes present at
  transformed `fr_panel_scr` points, manifold.
- [ ] **Step 3: Commit.**

### Task 5: `src/parts/frame_parts.scad` — small parts + chirality coupon

**Files:**
- Create: `src/parts/frame_parts.scad` (`-D PART=1..7 [-D GLAND=7|9|11]`)

**Interfaces:**
- Produces: `stl/frame_handle.stl` (×2 print), `frame_foot.stl` (×2),
  `frame_leg.stl` (×3), `frame_key.stl` (×4), `frame_gland_pg9.stl`
  (`GLAND` variants), `frame_trim.stl` (edge trim strips, ×4 corner-L),
  `frame_coupon.stl`.

- [ ] **Step 1: Write the parts:**
  1 handle: outer 120×44×15 rounded bar, 96×24 grip opening, 2 tabs with
    Ø4.5 counterbored bolt holes at 80 spacing; prints on its side.
  2 foot: T-tab (16.0×3.0 cross, 10.0×3.0 stem, 8.6 tall, split spring slot
    + 0.8 click ridge) on a 90×24×6 blade.
  3 leg: Ø10.0×13 pin + Ø14×2 shoulder + Ø10 column to z 36 from plate
    back = total 13+2+20... column such that top face lands at cavity 36
    over the S1/S2 strap boss (boss top at 14): 22 above shoulder; Ø2.8
    pilot 8 deep in top.
  4 gland plate: 45×30×2.5, PG bore per `GLAND` (7→12.5, 9→15.2, 11→18.6),
    2 Ø3.4 holes at ±20.
  5 key: bowtie 23.6×13.6×4.8 with 2 Ø3.4 holes.
  6 trim: corner-L strips matching each segment's outer profile: L-angle
    4.5 (covers plate edge + clr + wall front) × (fr_reveal+... ) — profile:
    leg A covers the wall front edge (3 wide), leg B the reveal face 2 over
    the plate front; snap tongue 1.4×1.8 engaging the wall groove. Rendered
    per SEG via `-D SEG=` like frame.scad, flat.
  7 coupon: 60×150×1.2 plate with BOTH candidate Elite diagonals (holes +
    embossed "A"/"B") and all 6 PSU holes + case-corner engraving — verify
    against the physical units, then set `ctl_diag`/`psu` and reprint straps
    of truth (rails) only after it passes.
- [ ] **Step 2: Render each; probe** hole positions on gland plate + coupon
  (ring probe), manifold all.
- [ ] **Step 3: Commit.**
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

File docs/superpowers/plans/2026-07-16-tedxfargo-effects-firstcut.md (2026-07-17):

# TEDxFargo Effects — First Cut Implementation Plan

> **For agentic workers:** REQUIRED SUB-SKILL: Use superpowers:subagent-driven-development (recommended) or superpowers:executing-plans to implement this plan task-by-task. Steps use checkbox (`- [ ]`) syntax for tracking.

**Goal:** Prove the whole custom-effect pipeline end-to-end on hardware with one effect — the CHARGE sign ignites like neon (letters flickering on C→H→A→R→G→E), driven by a geometry-aware WLED usermod.

**Architecture:** `tools/gen_wiring.py` emits a baked geometry header (`charge_geometry.h`) from the wiring data. A small WLED usermod (`usermods/tedxfargo/`) includes it, defines the `mode_charge_bootup` effect, and registers it via `strip.addEffect()`. The usermod source is versioned in this (CHARGE) repo and copied into a clone of the WLED firmware to build/flash. The device stays in 2D matrix mode; the effect places color at real LEDs with `SEGMENT.setPixelColorXY(col, row, color)`.
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

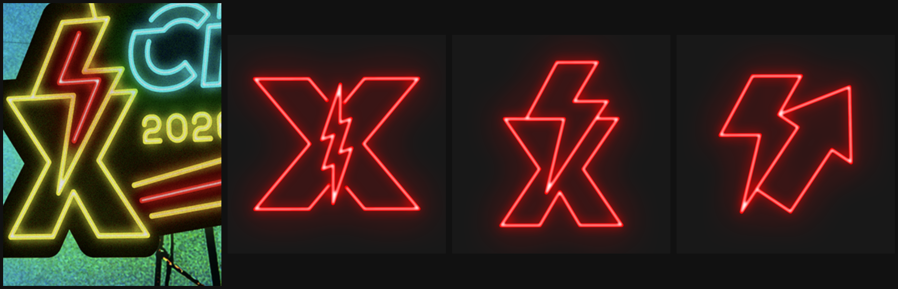
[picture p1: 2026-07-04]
docs/img/bolt-element-compare.png

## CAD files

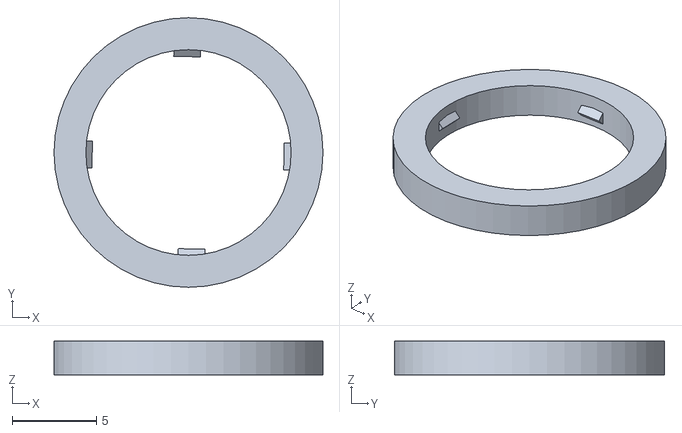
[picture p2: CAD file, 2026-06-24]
assets/bullet-collar.stl
16.0 x 16.0 x 2.00

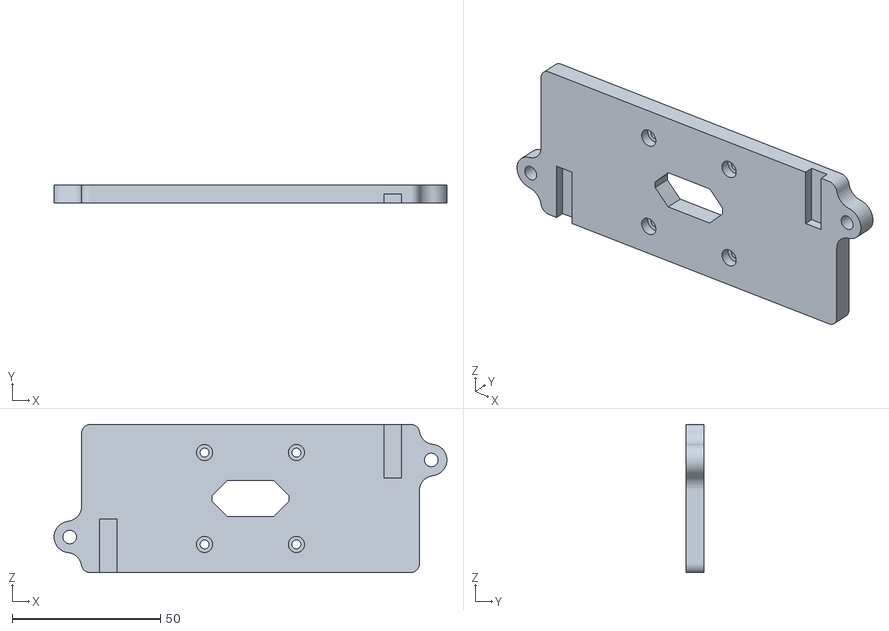
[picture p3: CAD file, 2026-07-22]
docs/elite2d_mount.stl
132.6 x 6.00 x 50.0

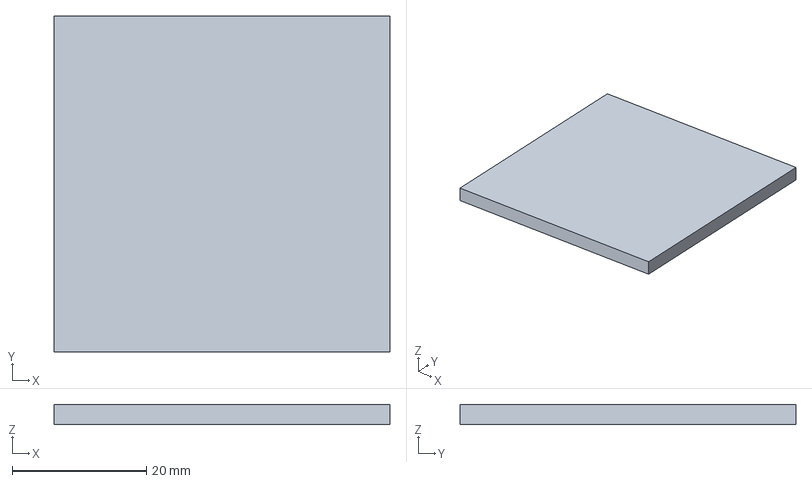
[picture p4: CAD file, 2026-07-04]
profiles/petg_-_transparent_parameters_-_0.4_mm_nozzle.3mf
50.0 x 50.0 x 3.00 mm

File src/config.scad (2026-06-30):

// ===== CHARGE LED sign — global config =====
// Edit this file; then run ./build.sh to regenerate every STL.

$fn = 72;

// ---- bullet pixel datasheet (measured + validated) ----
// dome Ø8, barrel Ø12, flange Ø13.6 x 2mm, dome-tip -> flange 5.5mm.
// Above the plate: ~Ø12 barrel for ~0.5mm, then the Ø8 dome to a tip ~dome_clear
// above the plate front. Drives pixel_through, dome_clear, and led_void clearances.

// ---- calibrated collar (press-fit for 12mm bullet pixel) ----
collar_stl    = "../../assets/bullet-collar.stl"; // path resolved from src/parts/ entry files
collar_h      = 2.0;     // Z span of the collar STL
collar_od     = 16.0;    // collar outer diameter
collar_cx     = 43.0;    // STL native X center (Y center is 0)
pixel_through = 12.3;    // clearance hole through the plate (just over bore Ø12.19)
dome_clear    = 4.0;     // dome protrusion above plate front. Spec: 5.5mm dome-tip-to-flange,
                         // flange seats on plate back, minus 2mm plate ~= 3.5-4mm. Seat a real
                         // pixel and measure to lock it in.

// ---- shell ----
plate_t    = 2.0;        // rear plate thickness (== collar_h, so the collar sits flush)
wall_t     = 2.5;        // chimney wall thickness
cell_inner = 30;         // square interior of each test cell (the press-fit opening)

// ---- diffuser panels (flat, drop-in — kept for the final glued option) ----
panel_press_clear = 0.25; // panel is this much SMALLER than the opening (total) -> friction fit
panel_thicks      = [1, 2, 3];

// ---- diffuser CAP (slides over an ISOLATED chimney; not used on touching rows) ----
cap_fit_clear = 0.4;   // skirt-inner minus chimney-outer (total); bigger = looser slide
cap_skirt_t   = 1.6;   // skirt wall thickness
cap_skirt_h   = 7;     // how far the skirt grips down over the chimney

// ---- diffuser LID = flanged plug (plug locates in the opening, flange catches on the rim) ----
lid_flange_cover = wall_t;  // flange overhang per side ~= wall width (rests on rim, can't fall in)
lid_flange_gap   = 0.3;     // shrink the flange a hair so neighbour lids don't clash
lid_plug_h       = 4;       // how far the plug drops into the opening (0 = plain flat tile)
lid_plug_clear   = 0.2;     // plug-outer = opening minus this (total) -> friction fit
                            // (was 0.5/loose; PETG plug in a PLA hole grips well at 0.2)
lid_plug_wall    = 1.5;     // plug-frame wall thickness

// ---- coupon depth ladder ----
led_gaps = [10, 15, 20]; // clear LED-tip -> diffuser distance, per cell (mm)
                         // (was [20,35,50] — 35/50 went too dim/washed; 20 is the new max)

// ---- collar v2: original bore + lip, plus a 45-deg lead-in chamfer ----
bore_face_r   = 6.10;    // collar bore radius at each face (~Ø12.2)
chamfer_depth = 0.5;     // axial depth of the 45-deg lead-in at each face
mouth_r       = bore_face_r + chamfer_depth;  // chamfer mouth radius (~Ø13.2)

// ---- collar A/B test harness ----
harness_w     = 52;      // tile width
harness_d     = 30;      // tile depth
harness_t     = plate_t; // match the real wall thickness for a faithful fit test
harness_pitch = 24;      // spacing between the two hole centers

// ---- derived ----
cell_pitch = cell_inner + 2 * wall_t;      // outer cell footprint (35)
n_cells    = len(led_gaps);
plate_w    = n_cells * cell_pitch;
plate_d    = cell_pitch;
panel_side = cell_inner - panel_press_clear;
function cell_x(i)     = i * cell_pitch + cell_pitch / 2;   // column center (distance)
function cell_y(j)     = j * cell_pitch + cell_pitch / 2;   // row center (for grid coupons)
function chimney_H(i)  = plate_t + dome_clear + led_gaps[i];

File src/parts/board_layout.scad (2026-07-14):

// AUTO-GENERATED by tools/boltboard.py — element-6 bolt board
bb_face = [410.0, 550.0];
bb_plates = [[0.0,153.0,0.0,255.0],[153.0,410.0,0.0,255.0],[0.0,126.0,255.0,550.0],[126.0,410.0,255.0,550.0]];
bb_paths = [
  [[190.14,173.29],[192.38,176.59],[194.62,179.91],[196.87,183.22],[199.07,186.56],[201.31,189.87],[203.54,193.19],[205.79,196.50],[208.01,199.81],[210.26,203.12],[212.48,206.45],[214.72,209.76],[216.94,213.09],[219.17,216.42],[221.38,219.74],[223.59,223.08],[225.85,226.38],[228.10,229.68],[230.34,233.00],[232.60,236.30],[234.82,239.62],[237.04,242.95],[239.26,246.28],[241.47,249.61],[243.70,252.93],[245.91,256.25],[248.13,259.59],[250.35,262.90],[252.56,266.25],[254.85,269.52],[257.06,272.86],[259.30,276.18],[261.51,279.50],[263.75,282.81],[266.00,286.12],[268.23,289.44],[270.44,292.78],[272.67,296.10],[274.88,299.43],[277.10,302.75],[279.31,306.09],[281.54,309.42],[283.82,312.69],[286.03,316.03],[288.25,319.35],[290.48,322.68],[292.70,326.00],[294.93,329.31],[297.18,332.62],[299.42,335.94],[301.67,339.25],[303.94,342.54],[306.24,345.81],[308.55,349.07],[311.90,351.09],[315.80,351.54],[319.80,351.50],[323.80,351.50],[327.80,351.50],[331.77,351.22],[335.77,351.22],[339.77,351.22],[343.77,351.22],[347.77,351.22],[351.77,351.22],[355.77,351.22],[359.77,351.22],[363.77,351.22],[367.77,351.22],[370.57,349.44],[369.67,345.55],[368.63,341.69],[366.59,338.26],[364.38,334.94],[362.15,331.61],[359.94,328.29],[357.68,324.99],[355.42,321.69],[353.12,318.41],[350.89,315.10],[348.61,311.81],[346.36,308.50],[344.12,305.19],[341.81,301.92],[339.57,298.61],[337.32,295.31],[335.03,292.03],[332.80,288.70],[330.53,285.41],[328.25,282.13],[326.01,278.81],[323.74,275.52],[321.44,272.25],[319.23,268.93],[316.94,265.63],[314.68,262.35],[312.45,259.02],[310.17,255.74],[307.88,252.46],[305.65,249.14],[303.36,245.87],[301.11,242.56],[298.84,239.27],[296.55,235.99],[294.32,232.67],[292.05,229.38],[289.75,226.09],[287.55,222.77],[285.23,219.51],[282.99,216.20],[280.76,212.88],[278.45,209.61],[276.20,206.31],[274.19,202.87],[273.24,199.01],[274.01,195.11],[276.09,191.70],[278.31,188.38],[280.53,185.05],[282.84,181.78],[285.08,178.48],[287.31,175.15],[289.59,171.87],[291.87,168.58],[294.08,165.26],[296.33,161.95],[298.65,158.69],[300.87,155.36],[303.15,152.08],[305.43,148.79],[307.65,145.47],[309.94,142.19],[312.21,138.90],[314.44,135.58],[316.75,132.30],[319.00,129.00],[321.20,125.67],[323.50,122.40],[325.77,119.11],[328.00,115.78],[330.28,112.50],[332.56,109.21],[334.78,105.89],[337.06,102.60],[339.33,99.31],[341.56,95.99],[343.86,92.71],[346.12,89.42],[348.37,86.11],[350.65,82.83],[352.89,79.52],[355.18,76.23],[357.44,72.94],[359.69,69.62],[361.94,66.32],[364.20,63.03],[366.44,59.71],[368.69,56.40],[370.89,53.07],[373.12,49.74],[375.33,46.42],[377.53,43.07],[379.70,39.72],[380.99,35.96],[381.94,32.08],[380.08,29.27],[376.08,29.26],[372.08,29.26],[368.08,29.26],[364.08,29.26],[360.08,29.21],[356.11,28.98],[352.11,28.98],[348.11,28.98],[344.11,28.98],[340.11,28.98],[336.11,28.98],[332.11,28.98],[328.11,28.98],[324.11,28.98],[320.11,28.98],[316.11,28.98],[312.12,28.98],[308.12,28.98],[304.12,28.98],[300.12,28.98],[296.12,28.98],[292.12,28.98],[288.12,28.98],[284.12,28.98],[280.12,28.98],[276.12,28.98],[272.12,28.98],[268.12,28.98],[264.13,29.21],[260.55,30.71],[258.22,33.96],[256.07,37.34],[254.00,40.76],[251.95,44.19],[249.89,47.62],[247.84,51.05],[245.78,54.48],[243.72,57.91],[241.66,61.33],[239.59,64.76],[237.53,68.19],[235.47,71.62],[233.41,75.04],[231.34,78.47],[229.28,81.90],[227.23,85.33],[225.19,88.76],[223.12,92.19],[221.06,95.62],[219.00,99.04],[216.94,102.47],[214.87,105.89],[212.81,109.31],[210.69,112.72],[208.62,116.13],[206.56,119.56],[204.25,122.79],[200.69,124.48],[196.91,123.45],[194.25,120.56],[192.19,117.13],[190.14,113.69],[188.10,110.26],[186.06,106.82],[184.01,103.38],[182.00,99.93],[179.97,96.48],[177.91,93.05],[175.88,89.61],[173.82,86.18],[171.79,82.73],[169.73,79.30],[167.69,75.86],[165.66,72.42],[163.62,68.98],[161.57,65.54],[159.53,62.10],[157.50,58.66],[155.46,55.22],[153.43,51.78],[151.38,48.35],[149.32,44.91],[147.28,41.48],[145.25,38.03],[143.03,34.71],[140.59,31.53],[137.53,29.12],[133.57,28.71],[129.57,28.71],[125.58,28.71],[121.59,28.68],[117.60,28.43],[113.60,28.43],[109.60,28.43],[105.60,28.43],[101.60,28.43],[97.60,28.43],[93.60,28.43],[89.61,28.43],[85.61,28.43],[81.61,28.43],[77.61,28.43],[73.61,28.43],[69.61,28.43],[65.61,28.43],[61.61,28.43],[57.61,28.43],[53.61,28.43],[49.61,28.43],[45.61,28.43],[41.61,28.43],[37.62,28.43],[33.62,28.43],[29.62,28.43],[28.06,31.30],[29.04,35.17],[30.27,38.94],[32.43,42.31],[34.63,45.66],[36.86,48.97],[39.10,52.29],[41.33,55.60],[43.56,58.92],[45.80,62.24],[48.03,65.55],[50.25,68.88],[52.47,72.21],[54.69,75.54],[56.90,78.87],[59.16,82.17],[61.46,85.44],[63.69,88.76],[65.91,92.09],[68.12,95.42],[70.36,98.73],[72.64,102.01],[74.90,105.32],[77.12,108.64],[79.34,111.97],[81.56,115.30],[83.83,118.59],[86.07,121.90],[88.34,125.19],[90.56,128.52],[92.78,131.85],[95.00,135.17],[97.28,138.46],[99.52,141.77],[101.77,145.08],[104.00,148.40],[106.22,151.73],[108.43,155.05],[110.71,158.34],[112.95,161.66],[115.21,164.95],[117.44,168.27],[119.65,171.59],[121.92,174.90],[124.15,178.22],[126.40,181.53],[128.62,184.84],[130.85,188.16],[133.13,191.45],[135.16,194.88],[136.16,198.75],[135.31,202.62],[133.28,206.06],[131.03,209.37],[128.72,212.62],[126.50,215.95],[124.17,219.20],[121.94,222.52],[119.63,225.78],[117.38,229.09],[115.07,232.34],[112.82,235.66],[110.53,238.94],[108.26,242.23],[105.95,245.49],[103.70,248.80],[101.41,252.06],[99.14,255.37],[96.87,258.65],[94.57,261.93],[92.33,265.24],[90.02,268.50],[87.78,271.81],[85.45,275.06],[83.23,278.38],[80.90,281.64],[78.67,284.95],[76.36,288.23],[74.10,291.53],[71.83,294.81],[69.55,298.10],[67.28,301.40],[64.98,304.67],[62.75,307.98],[60.42,311.23],[58.19,314.55],[55.90,317.82],[53.65,321.13],[51.38,324.43],[49.13,327.74],[46.89,331.05],[44.67,334.38],[42.48,337.72],[40.45,341.15],[39.37,345.00],[38.40,348.88],[39.50,350.40],[43.49,350.40],[47.48,350.40],[51.46,350.40],[55.45,350.40],[59.44,350.40],[63.42,350.40],[67.41,350.40],[71.40,350.40],[75.39,350.40],[79.37,350.40],[83.36,350.40],[87.35,350.40],[91.33,350.40],[95.32,350.40],[99.30,350.66],[103.22,350.56],[107.18,350.40],[111.16,350.40],[115.15,350.40],[119.14,350.40],[123.13,350.40],[127.11,350.40],[131.09,350.23],[135.06,350.12],[139.06,350.12],[143.03,350.30],[147.02,350.40],[151.00,350.40],[155.00,350.40],[158.97,350.40],[162.97,350.40],[166.95,350.40],[170.94,350.40],[174.92,350.40],[178.91,350.40],[182.91,350.40],[186.88,350.40],[190.88,350.40],[194.87,350.40],[198.85,350.40],[202.84,350.40],[206.82,350.40],[210.50,349.28],[210.94,345.49],[210.54,341.51],[209.82,337.60],[208.89,333.73],[207.94,329.86],[207.06,325.97],[206.16,322.09],[205.20,318.20],[204.34,314.31],[203.42,310.44],[202.50,306.56],[201.62,302.68],[200.66,298.81],[199.73,294.93],[198.82,291.05],[197.89,287.17],[196.95,283.29],[196.03,279.40],[195.12,275.54],[194.14,271.67],[193.22,267.79],[192.31,263.90],[191.38,260.02],[190.44,256.15],[189.53,252.28],[188.60,248.40],[187.64,244.53],[186.75,240.64],[185.79,236.77],[184.88,232.89],[183.94,229.02],[183.03,225.14],[182.09,221.26],[181.17,217.38],[180.25,213.50],[179.34,209.62],[178.38,205.75],[177.51,201.86],[176.62,197.97],[175.70,194.09],[174.78,190.22],[173.84,186.34],[172.91,182.46],[171.97,178.59],[171.06,174.71],[170.09,170.84],[169.19,166.96],[168.54,163.03],[168.16,159.06],[167.88,155.09],[190.14,173.29]],
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

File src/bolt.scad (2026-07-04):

bolt_pts  = [[155.0,300.0], [75.0,180.0], [130.0,180.0], [45.0,30.0]];
pixel_pts = [[155.0,300.0], [145.5,285.8], [136.0,271.5], [126.5,257.2], [117.0,243.0], [107.5,228.8], [98.0,214.5], [88.5,200.2], [79.0,186.0], [95.1,180.0], [112.3,180.0], [129.4,180.0], [121.4,164.8], [113.0,149.9], [104.5,135.1], [96.1,120.2], [87.6,105.3], [79.2,90.4], [70.8,75.5], [62.3,60.6], [53.9,45.7], [45.4,30.8]];

// ===== CHARGE lightning-bolt test piece — option C (~18mm channel) =====
bolt_inner     = 18;                       // channel interior (collar O16 fits)
bolt_wall      = 2;                         // wall thickness
bolt_outer     = bolt_inner + 2*bolt_wall; // 22mm outer stroke
bolt_gap       = 15;                       // LED-tip -> lens
bolt_ch_h      = dome_clear + bolt_gap;    // wall height above plate
bolt_lens_t    = 1.5;                       // lens face thickness  <-- TUNE (look/diffusion; = white-base layer count if 2-tone)
bolt_lip_h     = 2;                         // lens locating lip depth  <-- TUNE (how far the lip grips into the channel)
bolt_lip_clear = -0.2;                      // LOCKED: 0.2mm interference = perfect snap-in, material-robust (clear PETG and clear PLA both validated), 2026-06-30
bolt_lip_t     = 1.2;                       // lip wall thickness

module bolt_stroke(w) {
    for (i = [0 : len(bolt_pts) - 2])
        hull() {
            translate(bolt_pts[i])     circle(d = w);
            translate(bolt_pts[i + 1]) circle(d = w);
        }
}

// wall_h = channel wall height above the plate (gap = wall_h - dome_clear).
// The lens caps the cross-section, so the SAME lens fits any wall_h.
module bolt_shell(wall_h = bolt_ch_h) {
    difference() {
        union() {
            linear_extrude(plate_t) bolt_stroke(bolt_outer);
            translate([0, 0, plate_t]) linear_extrude(wall_h)
                difference() { bolt_stroke(bolt_outer); bolt_stroke(bolt_inner); }
        }
        for (p = pixel_pts)
            translate([p[0], p[1], -0.1]) cylinder(h = plate_t + 0.2, d = pixel_through);
    }
    for (p = pixel_pts) place_collar(p[0], p[1]);
}

module bolt_lens() {
    // Pre-mirror: same chirality-on-flip reason as bolt_overcap (this lens is
    // printed face-down and flipped lip-down to drop into the channel).
    mirror([1, 0, 0]) union() {
        linear_extrude(bolt_lens_t) bolt_stroke(bolt_outer);
        translate([0, 0, bolt_lens_t]) linear_extrude(bolt_lip_h)
            difference() {
                bolt_stroke(bolt_inner - bolt_lip_clear);
                bolt_stroke(bolt_inner - bolt_lip_clear - 2 * bolt_lip_t);
            }
    }
}

// ---- INTEGRATED lens (current spec): welded clear roof + baked fuzzy top ----
// One 2-color print, lens-UP, in USE orientation: white = bolt_shell() as-is
// (filament 1), clear = this (filament 2), fused to the wall tops by i_fuse overlap.
// Same construction as the proven testbox. No flip -> NO mirror (chirality moot).
// Replaces the press-fit bolt_lens: no lip, no clearance — the print welds it on.
i_lens_t = 1.2;    // integrated lens thickness (testbox-validated)
i_fuse   = 0.1;    // white/clear overlap so the slicer fuses them
bolt_ctr = [100, 165];  // bolt bbox center (x 34..166, y 19..311) — fuzz grid center

module bolt_lens_integrated(datfile = "fuzz_bolt.dat", cell = 1.5) {
    z0  = plate_t + bolt_ch_h - i_fuse;                  // fused to walls
    top = plate_t + bolt_ch_h + i_lens_t;                // nominal flat top
    union() {
        translate([0, 0, z0]) linear_extrude(top - z0) bolt_stroke(bolt_outer);
        intersection() {                                  // baked fuzzy bumps, clipped
            translate([bolt_ctr[0], bolt_ctr[1], top - 0.1]) scale([cell, cell, 1])
                surface(file = datfile, center = true, convexity = 8);
            translate([0, 0, top - 0.3]) linear_extrude(3) bolt_stroke(bolt_outer);
        }
    }
}

// ----- snap-OVER lens: a cap that wraps the WHOLE bolt outside (skirt grips the
// 22mm outer wall). Works because the bolt is a single isolated piece. Top = the
// diffuser face. Print top-down, flip in use; fits any bolt height.
// 2-filament: clear for the first cap_top_t (top), white above (skirt) via a
// slicer height color-change. 3-filament: also paint the skirt's outer wall black.
cap_clear   = 0.3;   // skirt-inner = bolt_outer + this (slide/snap over)
cap_wall    = 1.6;   // skirt wall thickness
cap_top_t   = 1.2;   // diffuser top thickness
cap_skirt_h = 9;     // how far the skirt wraps down the bolt sides

module bolt_overcap() {
    si = bolt_outer + cap_clear;
    so = si + 2 * cap_wall;
    // Pre-mirror: this cap prints skirt-up (top face on bed) and is FLIPPED to
    // seat. A flip mirrors the footprint, and the bolt is chiral, so without this
    // the flipped cap is a backwards bolt that won't register. Mirroring here means
    // the flipped part is just a rotation of the bolt footprint -> aligns by eye.
    mirror([1, 0, 0]) union() {
        linear_extrude(cap_top_t) bolt_stroke(so);
        translate([0, 0, cap_top_t]) linear_extrude(cap_skirt_h)
            difference() { bolt_stroke(so); bolt_stroke(si); }
    }
}

// Fit-test chunk: a short straight section of the over-cap at a chosen skirt
// clearance. Slide it onto a straight part of the printed bolt to feel the fit.
// `marks` debossed dots on the bed face = which one it is (more dots = tighter).
module cap_chunk(clear, marks, L = 45) {
    si = bolt_outer + clear;
    so = si + 2 * cap_wall;
    difference() {
        union() {
            linear_extrude(cap_top_t)
                hull() { translate([-L/2,0]) circle(d=so); translate([L/2,0]) circle(d=so); }
            translate([0,0,cap_top_t]) linear_extrude(cap_skirt_h)
                difference() {
                    hull() { translate([-L/2,0]) circle(d=so); translate([L/2,0]) circle(d=so); }
                    hull() { translate([-L/2,0]) circle(d=si); translate([L/2,0]) circle(d=si); }
                }
        }
        for (i = [0 : marks - 1])
            translate([-L/2 + 9 + i*4, 0, -0.1]) cylinder(h = 0.8, d = 1.8);
    }
}

// Fit-test slice of the INNER lens: a short STRAIGHT section of the lens face +
// locating lip at a chosen lip clearance. Press the lip into a straight run of
// the printed channel (the bolt's middle segment is ~55mm straight) to feel the
// fit -- no need to print a whole lightning bolt. `clear` = total lip clearance
// into the channel (lip outer = bolt_inner - clear); SMALLER = tighter. `marks`
// debossed dots on the bed/face = which one (more dots = tighter). Straight =>
// mirror-symmetric, so no chirality concern (unlike the full lens).
module lens_chunk(clear, marks, L = 40, label = "") {
    lip_o = bolt_inner - clear;          // lip outer width (drops into channel)
    lip_i = lip_o - 2 * bolt_lip_t;      // lip inner width
    difference() {
        union() {
            // face: full outer width, bed-face down
            linear_extrude(bolt_lens_t)
                hull() { translate([-L/2,0]) circle(d=bolt_outer); translate([L/2,0]) circle(d=bolt_outer); }
            // locating lip on top of the face
            translate([0,0,bolt_lens_t]) linear_extrude(bolt_lip_h)
                difference() {
                    hull() { translate([-L/2,0]) circle(d=lip_o); translate([L/2,0]) circle(d=lip_o); }
                    hull() { translate([-L/2,0]) circle(d=lip_i); translate([L/2,0]) circle(d=lip_i); }
                }
        }
        // dots = quick tightness order (more = tighter), at the centerline
        for (i = [0 : marks - 1])
            translate([-L/2 + 9 + i*4, 0, -0.1]) cylinder(h = 0.8, d = 1.8);
        // clearance value debossed on the bed face (mirrored to read from below)
        if (label != "")
            translate([0, -bolt_outer/2 + 4, -0.1]) linear_extrude(0.9)
                mirror([1,0,0]) text(label, size=4.5, halign="center", valign="center");
    }
}

// ---- two-color bolt lens: white/clear STRIPE on the viewer (bed) face ----
// The lens prints face-DOWN, so the bed layers ARE the viewer face. A white region
// on the bottom ~lens_white_t scatters light (milky); the rest stays clear. In-layer
// 2-color (needs the 3MF). Two variations:
//   V1: WHITE center stripe (over the LED line) + clear edges
//   V2: CLEAR center stripe + WHITE edges
// Lip (above the face) stays clear in both -- validated -0.2 fit. Export white+clear
// STLs, combine with tools/make_3mf.py, same as the matrix.
lens_white_t  = 0.4;   // white depth from the bed/viewer face (~2 layers); = bolt_lens_t -> full-thickness stripe
lens_stripe_w = 12;    // center-stripe width over the LEDs (face is bolt_outer = 22 wide)
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

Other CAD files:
src/collar_v2.scad
src/collar.scad
src/coupon.scad
src/diffuser.scad
src/harness.scad
src/lens_cell.scad
src/letter.scad
src/parts/bolt2_clear.scad
src/parts/bolt2_preview.scad
src/parts/bolt2_white.scad
src/parts/bolt_lens.scad
src/parts/bolt_lens_2c_preview.scad
src/parts/bolt_lens_v1_clear.scad
src/parts/bolt_lens_v1_white.scad
src/parts/bolt_lens_v2_clear.scad
src/parts/bolt_lens_v2_white.scad
src/parts/bolt_overcap.scad
src/parts/bolt_piece.scad
src/parts/bolt_shell.scad
src/parts/bolt_shell_short.scad
src/parts/boltx_data.scad
src/parts/bracket.scad
src/parts/bracket_layout.scad
src/parts/cap_fit_0p0.scad
src/parts/cap_fit_0p1.scad
src/parts/cap_fit_0p2.scad
src/parts/collar_harness.scad
src/parts/collar_v2.scad
src/parts/coupon3x3.scad
src/parts/coupon_body.scad
src/parts/coupon_cut.scad
src/parts/frame.scad
src/parts/frame_layout.scad
src/parts/frame_panel.scad
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

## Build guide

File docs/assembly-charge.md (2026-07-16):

# CHARGE billboard — print & assembly card

Six 3-color word pieces (`stl/piece<N>_3color.3mf`) + four bolt-board plates
(`stl/board<N>_3color.3mf`). Cut preview / seam map:
`docs/sign-preview/cut-preview.html`; full composition `docs/sign-preview/full-sign.html`.
Specs: `docs/locked-specs.md`,
`docs/superpowers/specs/2026-07-03-billboard-panelize-design.md`.

## Pieces (rendered weights, PETG @1.27)

Letterforms are the APPROVED originals (the art's open strokes are the font).
The 2026-07-05 bridging experiment was reverted at the user's direction — the
"no gaps" scope applies to the BOLT BOARD ONLY.

| # | letter | footprint (mm) | black | white | clear | total | pixels |
|---|---|---|---|---|---|---|---|
| 1 | C | 295 × 295 | 225 g | 60 g | 43 g | 328 g | 62 |
| 2 | H | 316 × 295 | 234 g | 78 g | 56 g | 368 g | 81 |
| 3 | A | 296 × 295 | 222 g | 63 g | 46 g | 331 g | 67 |
| 4 | R | 292 × 295 | 252 g | 80 g | 57 g | 389 g | 82 |
| 5 | G | 300 × 295 | 235 g | 79 g | 57 g | 371 g | 82 |
| 6 | E | 290 × 295 | 240 g | 78 g | 56 g | 374 g | 80 |
| | **total** | face 1597 × 295 | 1408 g | 438 g | 315 g | **2161 g** | **454** |

Pixel layout is relaxation-solved: min spacing 14.2 mm (flange is 13.6). Three snug pairs
sit in the R's lower leg (~x 957–989) — press those firmly; no trimming needed. One pixel
deliberately omitted at the A's tube crossing (shared light pocket).

## Bolt board (element 6: fused bolt+X, yellow + red inner)

Board face 410 × 550 mm, four plates, piecewise seams (y=255 full width; top row
splits at x=126, bottom row at x=153). CONTINUOUS MODE: channels cross the plate
joints (7 hairline lens joints; butt the plates snug — one global fuzz field keeps
the lens texture continuous). **SEAM STRAPS (2026-07-10, spec
`docs/superpowers/specs/2026-07-10-seam-bracket-design.md`): printed white splice
straps behind each seam replace the y-seam rail; LEDs run continuously across the
joints.** 137 pixels @ 21.5 mm (116 yellow / 21 red), pinned at every crossing
(±9.5 mm straddle); worst seam-adjacent spacing 23.5 mm (was 58). TWO pixels sit ON
a seam — their collars are embedded in straps S4/S3 (they seat 2 mm deeper; in the
validated optics window). `src/parts/bolt_pixmap.json` maps color zone + plate +
`mount` (plate|bracket) + chain (136 links; extension jumpers at chain 86 and 107).
Review page: `docs/sign-preview/bracket-preview.html`
(`python3 tools/gen_bracketpreview.py`).

| plate | position | footprint (mm) | black | white | clear | total | pixels |
|---|---|---|---|---|---|---|---|
| B1 | bottom-left | 153 × 255 | 113 g | 22 g | 17 g | 152 g | 18 |
| B2 | bottom-right | 257 × 255 | 193 g | 44 g | 33 g | 270 g | 39 |
| B3 | top-left | 126 × 295 | 101 g | 13 g | 10 g | 124 g | 12 |
| B4 | top-right | 284 × 295 | 259 g | 78 g | 58 g | 395 g | 68 |
| | **total** | board 410 × 550 | 664 g | 157 g | 118 g | **939 g** | **137** |

Same 0.20 Standard process and filament layout as the word pieces (all plates are
smaller than the worst word piece; 295 side across the bed). Plates splice on the
printed straps (S1+S2 on y=255, butt joint x=145.5; S3 on x=126; S4 on x=153) with
**M4×8 black button-heads into captive hex nuts** (23 face holes along the seams);
the panel then mounts to the frame by **perimeter wood screws only** (Ø4.5, 14 —
bottom/top rails + side stiles; NO y-seam rail). Straps print in white PETG,
front-face-down, no supports (S1 37 g / S2 67 g / S3 68 g / S4 54 g ≈ 226 g total),
plus the pixel-pusher tool. Leg sockets (Ø10.2, three on the y-straps) stay empty
unless the mounted panel flexes — then print Ø10 friction legs at plenum depth.
Labels debossed on bed faces (B1–B4).

## Slicing (per validated specs)
- **CHOSEN LAYOUT (2026-07-05): black + clear on the RIGHT nozzle (AMS side), white on
  the LEFT (external spool).** 3MF filament order matches: **1 = black (right), 2 = clear
  (right), 3 = white (left)**. Load a second black spool in the right AMS as a
  same-filament backup pair (auto-failover on the heavy consumer — black is 2/3 of all
  filament). Black and white still sit on different nozzles → the per-layer wall
  alternation stays purge-free. The print's ONLY filament change is black→clear on the
  right nozzle at the lens (~z21, black is finished by then); bump the black→clear
  flush volume to ~700–800 mm³ — the prime tower absorbs it.
- Prime tower ON, placed in the right-nozzle-only column (fits all pieces; across-bed
  footprint is uniformly 295). Prepare-stage tower warnings that vanish after slicing
  are safe to ignore. Verify the filament→nozzle grouping in the slicer preview before
  sending (known Bambu Studio grouping quirk — use Rearrange Filament if needed).
- **These are SLICER settings — the 3MFs carry only geometry + filament order.** Set
  flush volumes / tower / nozzle mapping once per session, then **File → Import** each
  3MF into that one project (each becomes its own plate). Do NOT File → Open each file —
  that resets the project and your settings. Black→clear flush: verify the matrix cell
  (auto-calc is usually high for dark→light, but check ≈700–800 mm³).
- White (left, no backup): worst single piece uses ~81 g — weigh the spool before
  starting a piece if it's running low.
- **0.20 mm Standard** process validated in a test slice: ~8h51m/piece, ~0.25 g purged,
  ~106 "filament changes" = free per-layer nozzle swaps, not purges.
- Place **295-side across the bed** (between the H2D nozzle bands), 316-side deep. Validated
  with `stl/bedcheck_316x295.stl`.
- 0.16 mm layer · 0.42 line · 2 walls · 10% gyroid · 6 top / **7 bottom** (the +1 kills the
  fuzzy-top shell islands) · concentric top · supports OFF · **brim OFF** · bridge fan ON ·
  **prime tower ON** (see above — the tower is what absorbs the black→clear flush; do not
  re-flip this to OFF).
- Lens texture is **V8** (PETG bake-off winner): jittered pyramid facets, 2.0 mm cells /
  0.6 mm peaks — "uniform but scattered," brighter and clearer than the old V3 frost.
- **Import note:** R, G, E and board B4 may trigger Bambu's "model has issues → Fix?" on
  import — click **Fix** (it welds the µm-scale export slivers; validated benign class).
  C, H, A and B1–B3 import clean.
- Label (piece # + letter) is debossed on the bed face of each black body.

## Assembly
1. Wood frame (full sign ≈ 2.07 m wide: board 410 + 60 gap + word 1597; 50–75 mm standoff
   depth; thin back skin as shear web; PSU/controller on one side):
   - **Word zone**: top + bottom rails spanning the 1.6 m word run, catching each piece's
     corner/mid screws (as before).
   - **Board zone (seam-strap design, 2026-07-10)**: PERIMETER ONLY — bottom rail
     (screws at y≈6), top rail (y≈544), and side stiles (x≈6 / x≈404, mid-height
     screws). NO y-seam rail: the printed straps splice the plates into one rigid
     panel, and pixel bodies now live right at the seams where a rail would collide.
     Board is 550 tall vs the word's 295; share stiles at the 60 mm gap as before.
1b. **Board panel first, off the frame**: plates face-down and butted (B1|B2, B3|B4,
   rows together), M4 nuts dropped into the strap pockets, straps on (S1+S2 butt at
   x=145.5 — a screw pair flanks each side), M4×8 black button-heads from the front.
   THEN pixels — brackets-first means wires can never be pinched under a strap.
2. Word pieces butt left→right (1→6); seams are pre-relieved 0.12 mm/joint. Screw through
   the pre-drilled Ø4.5 holes (6 per piece: 4 corners + 2 mids) with black pan-heads into the rails.
   **Snug, not tight — let the pieces float.** PETG moves ~14× more than a wood rail along grain
   (70 vs 5 µm/m/°C): across the 1597 mm run a 10 °C rise wants 1.04 mm the frame won't give, and
   the 5 seams relieve only 0.6 mm total — the balance becomes bow, seam crush, or elongated holes
   (20 °C → 1.48 mm over). The LEDs make this a **standing** delta, not a seasonal one: they warm
   the PETG inside the plenum while the rail stays at ambient. If it bows, slot the outer holes on
   pieces 1 and 6. (Matched-CTE printed frame would remove it — priced and declined in
   `docs/superpowers/specs/2026-07-15-printed-frame-feasibility.md`.)
3. Pixels press into collars from behind, chained in path order within each letter, jumper
   slack across seams. 4-inch strings → ~85 mm folds; tuck loose in the plenum.
   (Zip-tie holes removed 2026-07-06: through-holes in the black face leak light
   as bright pinpricks with the plenum lit. Wood-screw holes remain.)
   **Board near-seam pixels** pass through the straps' Ø17 chamfered holes — seat them
   with the printed pusher (Ø14 slotted tube). The TWO on-seam pixels (marked
   `mount: bracket` in the pixmap, at (153,51) and (126,401)) press into the strap
   collars through the plates' Ø13 bites and sit 2 mm deeper — by design.
4. Pixels: **591 total** (454 word + 137 board) of EXACTLY 600 owned (strings of 50 —
   hard cap, user-confirmed). Leave the last string's unused 9-px tail ATTACHED and
   tucked in the plenum — it is the only spare stock (warranty covers DOA).
   Power: 591 also ≈ the 150 W/24 V PSU's full-white edge → cap ~80% or add a second PSU.
   Colors-only scenes draw far less.
5. Board wiring: ONE 137-px data chain (pixels are addressable; color zones are
   software) — follow the `chain` index in `bolt_pixmap.json`; extension jumpers
   at chain 86 and 107; jumper slack across seams like the word pieces.
6. Hardware shopping: 23× M4×8 black button-head + 23× M4 hex nut (+ spares).

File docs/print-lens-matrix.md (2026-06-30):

# Print card — lit-lens diffusion matrix

Goal: print 8 diffuser test cells in one dual-material job, light them, and pick the
recipe that glows most evenly. Full rationale: `superpowers/specs/2026-06-29-integrated-lens-design.md`.

## File to load
- **`stl/lens_matrix_2color.3mf`** — open this one file. It loads as a single object
  with two parts already mapped: **white body → filament 1, clear optic → filament 2.**

Regenerate if it gets overwritten:
```
./build.sh        # rebuilds stl/matrix_white.stl + matrix_clear.stl (source)
python3 tools/make_3mf.py stl/matrix_white.stl stl/matrix_clear.stl stl/lens_matrix_2color.3mf
```

## Bambu Studio (H2D)
1. Open the `.3mf`. (You'll get a "saved outside Bambu" banner — normal; the part→
   filament assignment still loads.)
2. Set **filament slot 1 = white, slot 2 = clear**. Use the **same polymer family for
   both** (both PLA *or* both PETG) — a PLA+PETG mix bonds poorly at the seam.
3. **Orientation:** leave as-is — already plate-down (collar tray on the bed, optics
   up). Do **not** flip.

## Slicer recipe — Adafruit neon settings (verified), go all-in
Source: https://learn.adafruit.com/led-neon-signs-with-neopixels/3d-printing

| Setting | Value |
|---|---|
| Layer height | **0.16mm** (0.20 = faster / Adafruit's implied default; avoid ≥0.24 — visible striping) |
| Line width | default **0.42mm** is fine (Adafruit says 0.4 nominal; 0.02 doesn't matter) |
| Wall loops | **2** |
| Infill | **10% gyroid** |
| Top/bottom layers | **6** |
| Supports | **off** (sealed cavities — can't remove internal supports anyway) |
| Brim | 3–5mm (adhesion for the thin walls) |
| Cooling | bridge fan **on** (A0–A3/R1 clear faces bridge ~30mm); don't crank the global fan on PETG |

Material/temps: Adafruit uses **PLA @ 220°C / 60°C bed** — match that for a literal
replication, or use **PETG** (Bambu PETG profile temps) for heat tolerance near the LEDs.
Either is fine for this test; just keep both colors the same family.

This one recipe covers all 8 cells. *Optional:* for a "purer" gyroid in the B1 cell
(light straight through the lattice, no solid skin), give it **1 top layer** instead of
6 — but that needs B1 as its own file; ask and I'll split it out.

## After printing
- Press a 12mm bullet pixel into each collar from the **back**.
- Light all 8 (white-ish, mid brightness). Look straight at the faces in a dim room.
- **Read the dot code** on the tray bottom (1–8) to know which is which.

## Cell legend (dots = cell #)
| Dots | Cell | What it is | Expect |
|---|---|---|---|
| 1 | A0 | cavity, **no mask** | brightest, but a center hotspot |
| 2 | A1 | perforated dot d14 @5mm | **even** (predicted best), ~mild dimming |
| 3 | A2 | perforated dot d16 | even, slightly wider block |
| 4 | A3 | perforated dot d14, deeper (gap18) | even, a touch softer |
| 5 | R1 | white reflector cone | bright, partial hotspot reduction |
| 6 | B1 | clear gyroid fill | even volumetric glow, dimmer ("alien") |
| 7 | C1 | clear + 90° TIR cone | bright, beam spread sideways |
| 8 | C2 | clear + 60° TIR cone | bright, more sideways spread |

## What to look for
- **Even, sourceless** glow (no bright dot over the LED) = winner.
- If a cell shows a **dark center** → its perforations clogged (over-extrusion); tell
  me and I'll open the holes up. (The physics sim shows an *opaque* dot inverts to a
  dark center — that's the tell.)
- Note brightness vs evenness per cell; we lock the winning cross-section and move it
  onto the TEDxFargo letter strokes.
```
tray layout (top view):
  [A0][A1][A2][A3]      <- masked-cavity sweep
  [R1][B1][C1][C2]      <- reflector / gyroid / TIR
```

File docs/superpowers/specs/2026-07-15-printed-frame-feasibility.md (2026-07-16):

# Printed frame / back panels / legs — feasibility (2026-07-15)

**Question:** could the wood frame, back skin, and legs all be 3D printed instead?

**Verdict: possible, and physics is never the blocker — print time is.** ~84 h and ~3.3 kg of
PETG to replace ~$25 of lumber that is stiffer per gram and per dollar. **Wood remains the
plan.** Recorded so a revisit doesn't redo the analysis.

Motivation if revisited (user, 2026-07-15, priority order): (1) avoid woodworking, (2) a
fully-printed / reproducible artifact, (3) structural integration. Mounting reality: the bolt
board hangs off the **left side of the wood-framed CHARGE sign** — so no base/stand is needed.

## Numbers

Sign envelope 2067 mm (board 410 + gap 60 + word 1597). Back-skin area 0.697 m². PETG @1.27,
observed rate ~41 g/h (360 g avg piece / 8h51m), ~$22/kg.

| item | mass | print | $ |
|---|---|---|---|
| back skin @2 mm | 1769 g | 43.5 h | $39 |
| frame @75 mm deep, ~5 m of member | 1508 g | 37.1 h | $33 |
| **added total** | **~3.3 kg** | **~84 h** | **~$72** |

Doubles project filament (3.3 kg printed → 6.7 kg). Panelization falls out exactly: back skin
needs **6 word + 2×2 board = 10 panels**, mirroring the front's 6+4 — same seams, same strap
vocabulary, nothing new to invent. Frame would need ~16 spliced joints.

## Why the section is never the problem

Every load case lands 50–200× under limits, because the word band is **295 mm deep as a beam**
over a ~2 m span:

| load case | result |
|---|---|
| hanging, full 2067 mm span | 0.37 mm sag |
| word band as a 1597 mm cantilever | 0.85 mm tip deflection |
| flange stress | 0.243 MPa = **0.5% of PETG yield** |

At 0.5% of yield, **creep is a non-issue too** (needs sustained stress near yield or temps near
Tg). The intuition "a printed frame will sag over time" is not supported by the arithmetic.
Freestanding was analysed and set aside once mounting was settled; for the record, a
self-supporting version tips at **9.8°** (95 mm footprint vs 275 mm CG) and would need 200–320 mm
of outrigger plus likely ballast — stability wants mass and width, which printing is worst at.

## Fastening (if revisited)

No new vocabulary needed — reuse the seam-strap pattern that passed 43 QA checks: butt the
members, splice with a printed strap, **M4×8 button-heads into captive hex nuts** (~16 joints ≈
64 screws + nuts). Carry over the **0.12 mm/joint seam relief**; 16 unrelieved butt joints stack
±2.4 mm across the span.

## Rule the numbers support

**Print connectors, not spans or sheets.** Brackets are complex geometry where printing wins.
Long members and flat panels are where it loses to a saw — a flat sheet is the single worst
geometry for a printer (slow, warp-prone, seam-heavy), and the sag math shows the back skin
carries no bending anyway. Its real jobs are hiding wiring and blocking light.

## The one thing this changed in the wood plan

Printing the frame would eliminate the **PETG-on-wood thermal differential** via matched CTE —
the only genuine engineering argument found in favour, and still not worth 84 h. The differential
is real and is now recorded as an assembly note in `assembly-charge.md` (step 2):

| ΔT | word run grows | wood rail grows | differential | vs 0.6 mm relief |
|----|---|---|---|---|
| 10 °C | 1.12 mm | 0.08 mm | 1.04 mm | **0.44 mm interference** |
| 20 °C | 2.24 mm | 0.16 mm | 2.08 mm | **1.48 mm interference** |

PETG ~70 µm/m/°C vs wood along grain ~5. The LEDs make this a **standing** delta — they warm the
PETG inside the plenum while the rail sits at ambient — not merely seasonal.

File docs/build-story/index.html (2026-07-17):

# Teaching a neon sign to play Pac-Man

How the CHARGE custom effects were built — one C++ header, a bit-exact browser simulator, and a long evening of live iteration. July 16–17, 2026.

▶ open the live simulator ← the sign build story

The sign is 459 WS281x pixels behind a 3D-printed neon-tube replica of the TEDxFargo CHARGE logo, driven by a Gledopto ESP32 controller running WLED 16.0.1. Stock WLED has hundreds of effects, but none of them know what the pixels are — which letter, where in space, where along the tube. This is the story of the seventeen effects that do (sixteen shipped; one shelved), and of the simulator that made it possible to build them on a couch instead of in front of the wall.

## 1 · Why the mapping had to exist first

Everything below rests on one piece of luck and two deliberate files, and it's worth understanding why — this duality is what makes every effect on this page possible.

Physically, the sign is one wire: a single 459-LED chain snaking through six letterforms, wired greedily along the neon path (each tube run end-to-end, nearest-end hops between tubes, letters strictly left to right). Out of the box, WLED sees that as an anonymous 1D strip — pixel 300 is just "pixel 300," with no idea it's halfway up the R.

The 2D layer: tools/gen_wiring.py emits ledmap.json — a 134×25 grid of 12 mm cells where each cell holds either -1 (no LED) or the chain index of the LED that physically sits there. Flash it and WLED becomes a true 2D matrix: stock spatial effects (plasma, sweeps, fire) render in real sign space, and custom effects can draw in actual geometry — lightning bolts that walk across the sky, shockwaves that radiate from a burst point, waves that wash left to right in millimeters rather than wire-order.

The 1D layer is the luck: because the wiring is greedy along the tube path, chain order is tube order. Walking indices 143→214 traces the letter A's neon tube end to end, every bend included. That's a free second coordinate system — "inside the glass" — that no grid can give you. A comet running the chain doesn't wipe across the sign; it threads through every letter. Pac-Man's maze corridors, the ants' tunnels, fireworks climbing before they burst — all of that is just iterating a contiguous index range.

The bridge between them is a baked header, generated in the same pass as the ledmap so the two can never drift:

// charge_geometry.h — emitted by tools/gen_wiring.py, indexed by chain i
const uint8_t  CHARGE_LETTER[459];   // 0=C .. 5=E  (letters are contiguous ranges!)
const uint8_t  CHARGE_COL[459];      // grid column   — the 2D world
const uint8_t  CHARGE_ROW[459];      // grid row
const uint8_t  CHARGE_HEIGHT[459];   // 0..255 within its letter — "gravity" axis
const uint8_t  CHARGE_XNORM[459];    // 0..255 across the whole sign
const uint16_t CHARGE_LETTER_START[6], CHARGE_LETTER_COUNT[6];

So a single effect can, in one frame: iterate letter A's tube (1D), find each pixel's true position (2D), ask how high it is inside its letterform (height), and place color through the same ledmap the device uses. The Storm effect is the clearest demo of the duality: its lightning bolts are jagged random walks in grid space, but the letter each bolt "loads" is addressed as a chain range — two coordinate systems, one strike.

A host-side test (tools/test_charge_geometry.py) proves the bridge: for every pixel, ledmap[row·W + col] == chain index — the header and the flashed map agree exactly, or CI fails. One hard-won detail carried over from earlier work: WLED finds the map array with a raw byte search for "map":[ — a single space after the colon and the device silently loads zero cells. The emitter asserts byte-compactness on every write.

## 2 · The bet: one source of truth, compiled twice

"i also want a detailed web simulator that uses the exact algorithms and mappings that we're using so we can test effects before actually flashing… sweet if we can transpile from c/c++ to js via wasm but not sure if it works like that... but the closer to real the better (vs two languages, same algorithm, maybe buggy)."— Blaine, opening request

That parenthetical — two languages, same algorithm, maybe buggy — is the whole design constraint. A JavaScript "port" of each effect would drift the moment anyone touched one side. So the architecture guarantees it can't:

wled/usermods/tedxfargo/charge_fx.h     ← ALL effect logic. Zero WLED includes.
        │
        ├── tedxfargo.cpp + wled.h      → ESP32 firmware (PlatformIO)
        └── sim_main.cpp + wled_shim.h  → WebAssembly    (Emscripten)

The effect header is written against a deliberately tiny API surface — SEGMENT.setPixelColorXY / fill / speed / intensity / customN / checkN, SEGENV.step/aux/call, strip.now, and a handful of color functions. The firmware provides that surface via the real wled.h; the simulator provides it via a ~200-line shim. The effect code itself is never ported — Emscripten compiles the identical .h file to wasm. When you drag a slider in the browser, the same bytes of arithmetic run that will run on the wall.

Why wasm matters here specifically: these effects are full of 8-bit integer tricks — qsub8 saturating math, fixed-point positions, deliberate uint8 wraparound in wave phases, WLED's exact color_fade rounding. In a hand-ported JS version every one of those is a chance for the sim to lie. Compiled C++ can't lie about its own arithmetic. Over the whole session the simulator's predictions held so well that every single hardware surprise turned out to be environmental (segment flags, buffer recycling, browser caches) — never the effect math.

## 3 · The steps, in the order they actually happened

1. Verify every claim against source. The design spec was written in a previous session and read confidently. Rule one of the build session: trust nothing that hasn't been grepped in the actual checkout. This immediately paid off — the plan's instruction custom_usermods = tedxfargo would have silently removed the microphone: the board env inherits custom_usermods = audioreactive from its parent, and a child env replaces that value rather than extending it. (The legacy -D UM_AUDIOREACTIVE_ENABLE define the spec leaned on turns out to only set a boot default inside the usermod — it compiles nothing in.) The fix is one line, but only if you know to write it: custom_usermods = audioreactive tedxfargo.
2. Geometry header, test-first. charge_geometry.py written against a failing test, including the ledmap round-trip check above.
3. Scaffold the usermod from WLED's own PS_Comet pattern (never hand-write registration boilerplate from memory), prove the firmware compiles with it enabled.
4. One effect end-to-end before anything else. "CHARGE Boot" — letters igniting C→H→A→R→G→E — was chosen as first light because it's trivially falsifiable: if letters light in the right places and the right order, the entire chain (header ↔ ledmap agreement, registration, XY routing, build, flash) is proven at once. If a letter lights in the wrong spot, the geometry is wrong; if nothing lights, the build is wrong. Clean signal either way.
5. The simulator (shim + wasm + canvas page), then the QA harness, then effects in batches — each new effect inheriting the whole test battery for free.
6. Palettes, hardware, and live iteration — the rest of this page.

"also - make sure all effects start w/ the same prefix so i can find them all easiliy :) (like "CHARGE" is great)"— Blaine (the QA suite now enforces the prefix, so it can never regress)

## 4 · Inside the simulator (the optional deep dive)

The shim is honest about what it is. Every piece sits on an explicit fidelity ladder, strictest first:

Tier | What | Examples
1 · Compile the real thing | WLED's own source, vendored byte-for-byte with a 12-line pgmspace.h stub | fastled_slim.{h,cpp} — CRGB, CRGBPalette16, gradient loading
2 · Verbatim ports, source cited | Functions copied line-for-line from the checkout, each with a comment naming its source file, re-diffed on WLED upgrades | color_fade, color_blend, ColorFromPalette, Segment::color_from_palette, loadPalette, allocateData, setPixelColorXY bounds semantics
3 · Documented approximations | Semantically equivalent, sequence differs — stated on the sim page itself | hw_random8() = seeded xorshift (reproducible runs!); the "Random Cycle" palette; browser mic vs. onboard mic

Palette data gets a fourth rule: never transcribed. sim/extract_palettes.py parses the 7 FastLED tables, 59 gradient palettes, and 72 names out of palettes.cpp in the WLED checkout at build time; the device's own custom palette backups load alongside them at the same IDs WLED assigns. If a byte of palette data is wrong in the sim, it's wrong in the firmware too — which is the point.

The page itself closes the loop the same way: it fetches the committed ledmap.json and applies it exactly like WLED's customMappingTable (grid cell → physical LED), then draws each LED at its true wired millimeter position from word_pixmap.json. On load it runs prechecks — byte-compact map, grid dimensions match the baked header, all 459 pixels routed, geometry round-trips — and refuses quietly plausible-looking wrongness.

Two things the sim deliberately does not simulate: stock WLED effects, and effect/palette transitions. Both proved relevant on hardware day (§7).

## 5 · The test battery

Three layers, all runnable from the repo root, all green before every commit:

- sh sim/qa.sh — per effect, against the wasm build: metadata well-formed with smart defaults and the CHARGE prefix; determinism (same seed + ticks twice → identical output); liveness (lights up and animates); cleanliness (never writes a grid cell the ledmap doesn't route — catches stray geometry writes); every declared slider and checkbox provably changes the output, with a retry harness for dependent params (palette-gated, checkbox-gated, or slow-cycle params get a longer window with other controls enabled); survival across the 49.7-day millis() wraparound; audio effects tracking the level.
- sh sim/test_native.sh — the same shared sources compiled natively and soaked: every effect × 7 parameter corners × 20 simulated minutes at 42 fps, with an audio sweep and a wrap crossing, under UBSan in trap-on-error mode. ASan turned out to be broken on this macOS/clang combo, so the harness carries its own canary guard bands around the frame buffer — which is how a real misaligned-struct bug was caught the frame Pac-Man's game state first allocated.
- Visual review — §6. The one layer a script can't do.

The param-effectiveness check earned its keep twice: it's how the sim proved that a checkbox the code implemented was never declared in the metadata (the Gravity "Tube fall" toggle existed with no way to reach it — the QA line literally said "3 params verified" where it should have said 4), and it forced a design improvement when the Ants colony-size slider changed nothing observable, which became "waiting ants visibly mill around the nest."

## 6 · "Go watch the demo"

"do a quality check on everything and use visualization to look at the Sims to make sure they're not too jarring or anything like that."— Blaine

This request produced the harness that ended up catching more real issues than anything else: sim/render_dump.mjs runs every effect in the wasm and dumps sampled LED frames plus temporal smoothness metrics (frame-to-frame luminance jumps, flash events, lit fraction), and sim/render_sheets.py renders contact sheets — pure-stdlib PNG writer, every LED drawn at its wired position. Then the sheets get looked at, frame by frame.

The metrics caught Boot ending its loop with a 66.7% full-sign luminance drop in a single frame — a hard cut to black nobody had noticed in motion. The eyeball pass caught a muddy Dreamwave, sparse Fireworks, invisible Ant tunnels, marble physics that jittered forever at the bottoms of letters. Later in the session the harness became the answer to the bluntest possible bug report:

"also gravity - way more balls, and they should respawn more often w/ tubes especially. go watch the demo its kind of boring/broken"— Blaine

…and watching the demo confirmed it exactly: balls spawned dead on the tube crest where the height gradient is zero (stuck forever), and oscillated at the bottoms because the gradient flips sign every frame. Both visible in eight still frames, both invisible in the code.

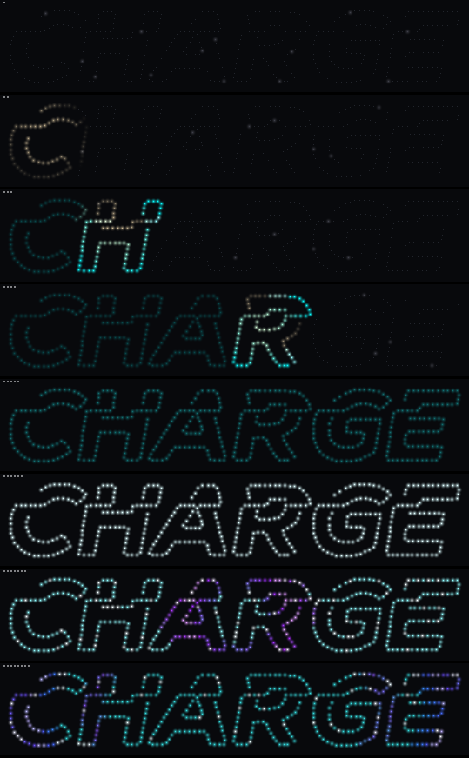
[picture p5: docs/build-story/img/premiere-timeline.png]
Premiere timeline contact sheet


Premiere's full timeline as a contact sheet: motes → spotlight → fills → swell → lightning → finale. Sheets like this verified every story effect frame-by-frame. run it live →

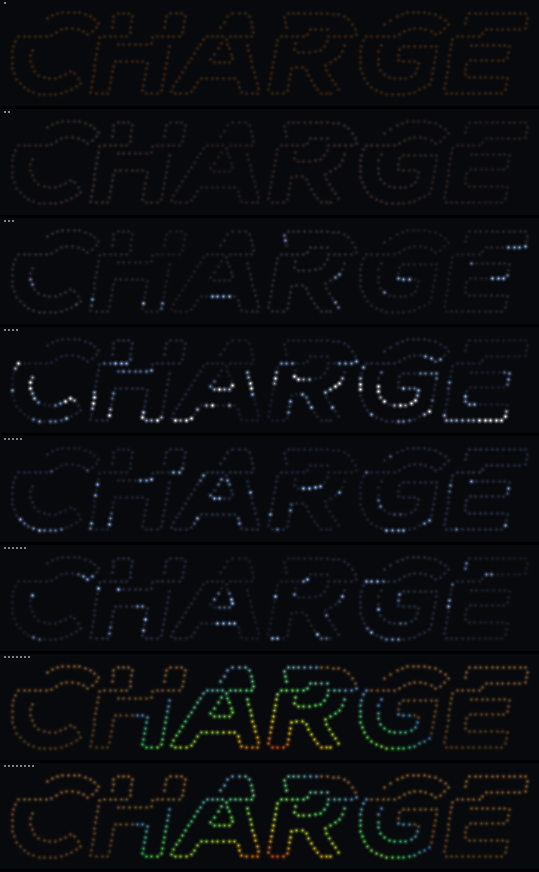
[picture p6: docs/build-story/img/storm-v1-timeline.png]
Storm v1 timeline


Storm v1's weather arc — dusk, rain, a bolt in frame 4, then the rainbow. The user's verdict rewrote it around the lightning (§8). run v2 live →

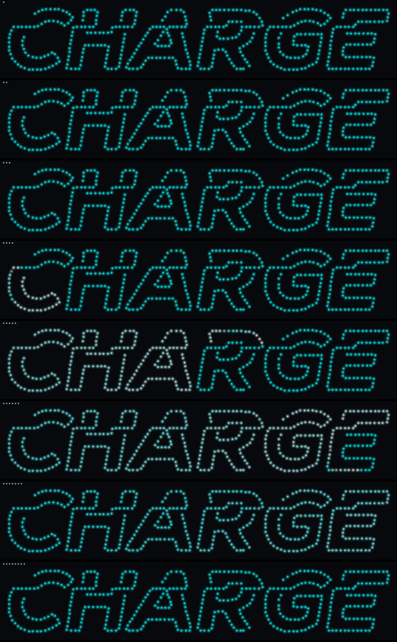
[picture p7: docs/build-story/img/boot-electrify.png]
Boot with Electrify


Boot's "Electrify": the bolt races left-to-right through the tubes (frames 4–8), leaving an overcharge glow that cools behind it. run it live →

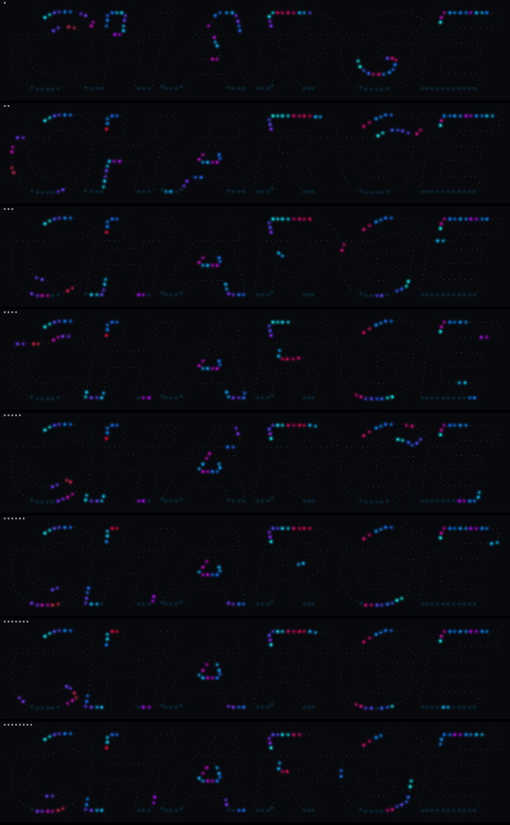
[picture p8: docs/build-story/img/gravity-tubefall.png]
Gravity tube-fall


Gravity's marble-drain after the physics fix: trains of marbles settling into the low bends of each letterform. run it live →

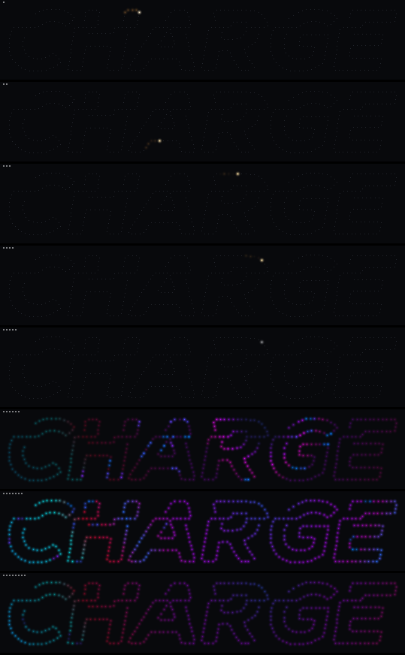
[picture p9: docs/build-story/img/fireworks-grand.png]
Grand firework sequence


The Grand firework: one rocket threads the whole 459-px chain, hangs, then floods the entire sign radially. run on the TEDx palette →

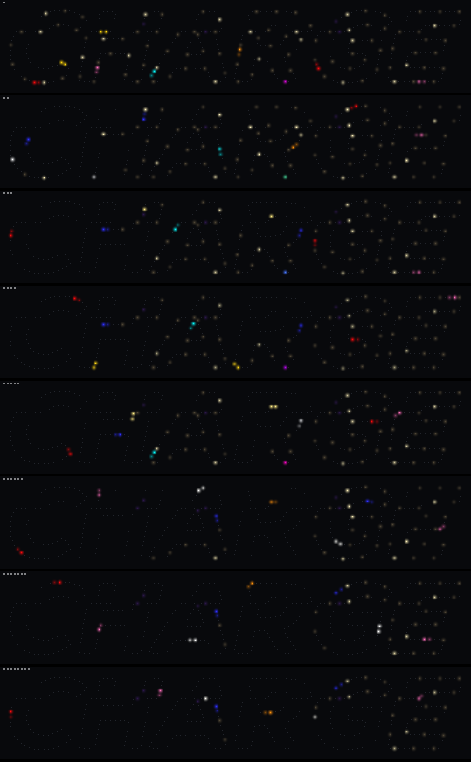
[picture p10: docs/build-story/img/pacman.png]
Pac-Man board


Pac-Man as a real game: pellets depleting across frames, classic ghosts (one frightened blue in frame 2), violet portal markers. run it live →

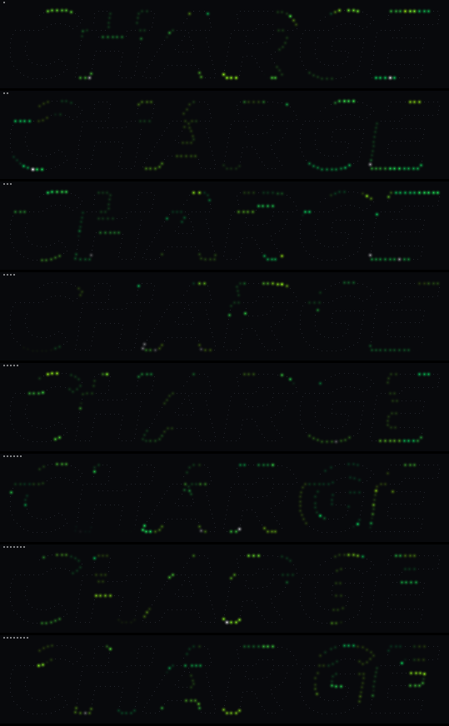
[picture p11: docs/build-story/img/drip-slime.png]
Drip in slime


Drip on the Slime palette — beads swell at the top of each letterform, fall through (x, height) space, splash at the base. run it live →

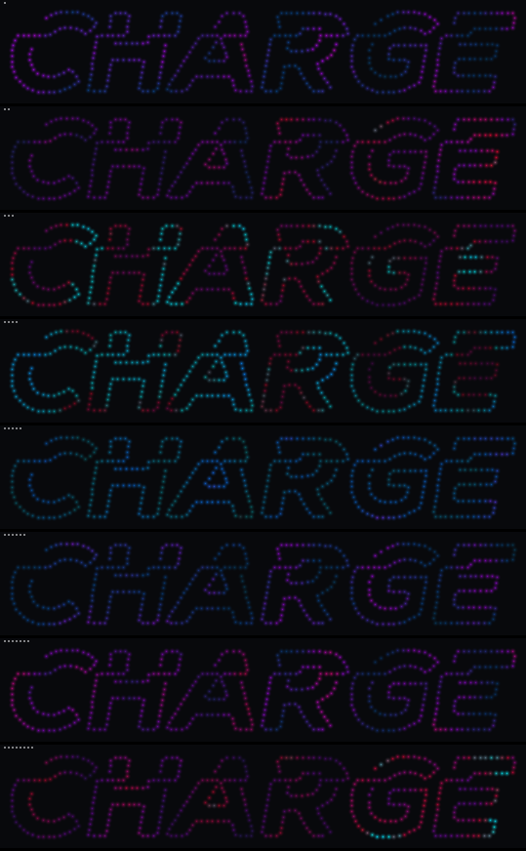
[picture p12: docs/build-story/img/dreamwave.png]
Dreamwave interference


Dreamwave: six wave sources (one per letter centroid) interfering across the sign. Its later "letters take turns speaking" story came from the review: "what's the story?" run it live →

## 7 · The palette bridge, and the patch it needed

Rather than invent a color system, the effects joined WLED's: they read the segment's palette through the real color_from_palette path, and the eight custom "goblin" palettes register as native usermod palettes — they appear in the standard WLED dropdown as "CHARGE: Brand Trip" etc., which means stock effects can use them too. House rule throughout: palette "Default" always reproduces each effect's classic look, so nothing beloved ever changed underneath a new feature.

Then the sign's own brand palette exposed a real limitation:

"for the tedx palette - i want to ensure the only options are the brightest of all: red, teal, yellow - no gradients that can be dimmer."— Blaine

First attempt: rebuild the palette as hard full-brightness bands with hairline transitions (duplicated gradient stops). It helped — and wasn't enough: "double check the TEDx palette - sometimes i still see blended colors (weaker) instead of full hue teal/red/yellow." The reason is structural: WLED resamples every palette into a 16-entry table and the renderer always linearly interpolates between adjacent entries. Even a zero-width stop in the source data becomes a ~16/255-wide washed transition zone after resampling. You cannot fix it in the palette data.

So it's fixed at the picker instead:

// palette color at pos, nudged off blend zones: step aside to the
// nearest fully saturated hue (spread = max-min channel >= 140)
static inline uint32_t charge_cfp_vivid(uint8_t pos) {
  static const int8_t off[5] = { 0, 8, -8, 16, -16 };
  ...
}

Every deliberate color choice — per-letter colors, cycle colors, finale glitter — goes through charge_cfp_vivid(), plus an adjacency rule (charge_letter_colors()) that re-rolls until neighboring letters are visibly different. Continuous gradients (Flow's trail, Dreamwave's field, the wave washes) stay raw on purpose — there, the blend is the look. On TEDx, letters now only ever come up pure teal, pure yellow, or pure red.

## 8 · Hardware day

"ok so the firmware flashed, which is good news. bad news - the effects partially work. seems like the mapping is off. for example, 'boot' light up in reverse - 'e' first... also each of the letters seems to be missing maybe every other LED - general locations seem ok - but things are definitely 'off'."— Blaine, first flash

"General locations seem ok" was the diagnostic gift in that report: it proved the ledmap had loaded and the geometry agreed with it — broken mapping looks like scrambled noise, not mirrored order. Both symptoms mapped to one cause: the active segment's transform flags, preserved from an old preset on the device filesystem. Reverse flips X across the matrix (letter C's pixels render at E's position → "E first"); Spacing=1 turns the 2D canvas into a dotted sub-grid ("missing every other LED"). Normalize the segment — one full-canvas segment, grouping 1, spacing 0, all transforms off — and:

"heck yeah that did it"— Blaine

Hardware then found the one bug class the simulator structurally cannot reproduce. Ants ran perfectly in the sim and glitched on the wall ("no resources"). Cause: WLED recycles effect data buffers without zeroing when you switch effects — if the previous effect's allocation was larger, the new effect receives its garbage. The sim's data pool always zeroes, so inited == 1 was trusting leftovers only on real hardware. All stateful effects now use magic-byte init guards (0x9C / 0xA7 / 0x6B) that garbage can't fake.

And then there was the cache saga — three separate flavors in one session: the device's own web UI caches effect metadata keyed by version (both firmwares say "16.0.1", so new sliders silently didn't appear); the browser cached charge_sim.wasm even after the JS glue was cache-busted (the metadata lives in the wasm — "i dont see it in the sim"); and finally index.html itself, which carries the busters, was cacheable. The end state kills the class: python3 sim/serve.py serves everything with Cache-Control: no-store. When a control seems missing, it's the server you're not using.

Honesty note: the "missing checkbox" was misdiagnosed as cache once when it was actually a metadata line lost to a crashed edit script — the QA output said "3 params verified" where it should have said 4, and that line got read past. The lesson stuck both ways: the harness had already caught it; the human-side failure was not reading the harness.

## 9 · Iterating live (the fun part)

"you're a psychedelic goblin who loves this sign and are creating masterpieces"— Blaine, setting the creative brief

Most of the suite's personality came from a long stretch of the user in the browser (later: in front of the wall) firing observations while effects were rewritten under them. A sampling of feedback → what it became:

The feedback, verbatim | What it became
"ants is neat but i feel like its just a version of pacman. ants should be *doing* something. maybe there's a pile of resources in one of the letters… resource = color?" | The colony economy: piles are palette colors, a lone scout recruits the colony with its first haul, and rich colonies glow their whole letter in the color of their latest delivery.
"boy the lightning is really good, how it criss-crosses and then fires. most realistic lightning yet. lets rethink this to focus on the lightning - maybe every flash loads one of the letters? and it keeps raining?" | Storm v2 — the weather-story timeline was deleted; stepped leaders hunt a dark letter, the return stroke loads it, rain never stops. (The "criss-cross then fire" they loved was stepped-leader flicker between two seeded bolt paths before the return stroke — so v2 leaned into exactly that.)
"the colors dont stay in the air very long. is that gravity? something else? fireworks 1d ps has a good way of doing that i think" | Not gravity — the decay curve. Sparks dimmed on an ease-out that dies fast; they now decay on a hold-bright quadratic (255 − t²/256), the same fix Comet's tails needed. That curve became a house rule: linear falloffs read dim on a physical wall.
"when a pellette is eaten, reverse and try to eat the ghosts" | Real Pac-Man rules: power pellets flip pac into a 4-second hunt; ghosts flee blue, blink, get eaten, respawn. Portals — tube positions far apart on the wire but physically adjacent, computed from the real grid geometry — let a cornered pac escape.
"dreamwave is neat but kind of dim at times, not quite sure what its point is again? … what's the story?" | The letters take turns "speaking": every ~12 s one letter brightens while its ripples surge across the other five. (Its later "stutter" report was a real discontinuity — integer weight steps re-normalizing the whole field — fixed with fixed-point weights.)
"its weird to me that entire letters just dont fire for sevral cycles" / "when switching to grand firework - should wait for all little ones to finish then go - it interrupts them currently" | Every letter fires every window, and Grand mode became era choreography: letters simply don't start a window they can't finish before the showpiece — they wrap up, one quiet beat, then the big one.

A pattern worth naming: the user's "something feels slightly off" reports went about six-for-six mapping to genuine discontinuities in the math — Premiere's spotlight hand-off jump, its finale brightness snap, Dreamwave's weight quantization, Flow's bounce color flip, the post-grand mid-flight resume. Perceptual instincts made excellent bug reports precisely because the simulator was trustworthy enough to rule out everything else.

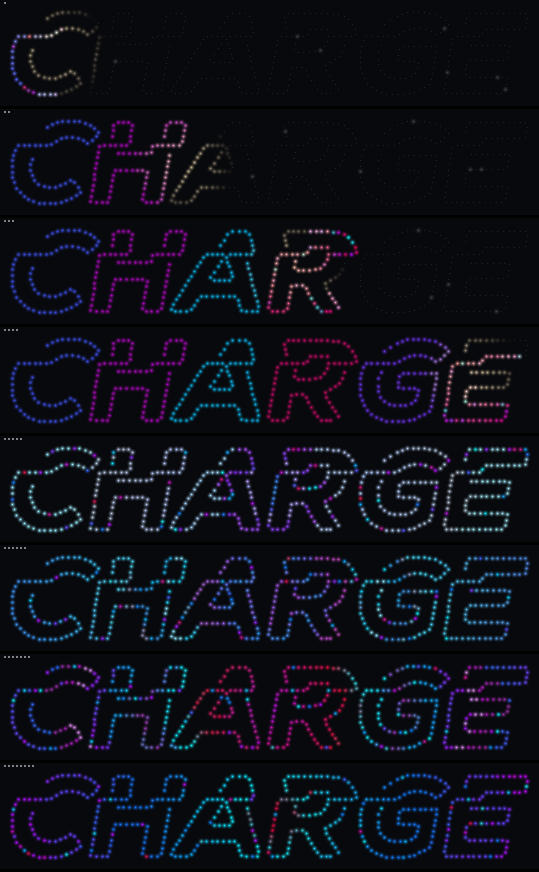
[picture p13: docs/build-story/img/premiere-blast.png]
Premiere full color finale


Premiere after "full color blast, deep saturated and beautiful" — per-letter vivid fills with palette sparkle, then the radial flood. run on Brand Trip →

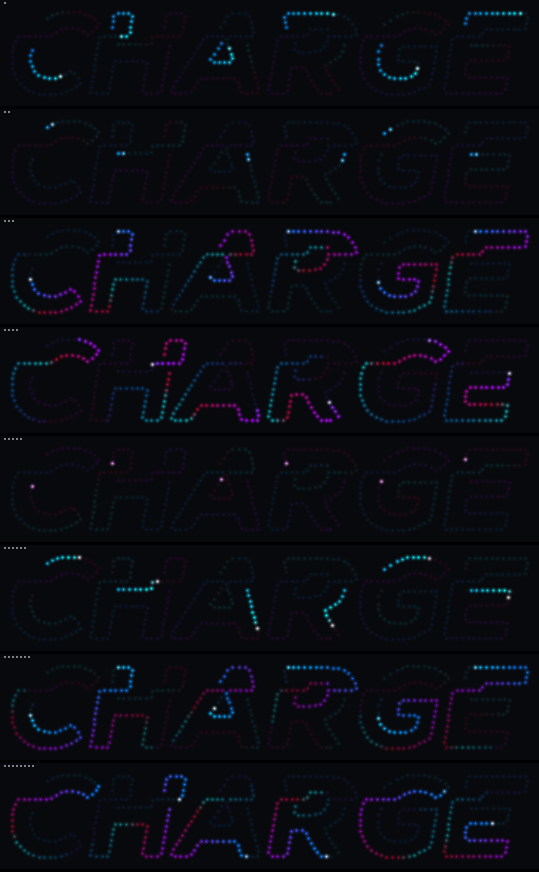
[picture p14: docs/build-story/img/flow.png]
Flow synced comets


Flow — born from the observation that Pulse's floor-up chase "can be its own effect." Every head synced at the same tube fraction; the trail is a gradient through the palette. run it live →

## 10 · What actually worked

- One source of truth, enforced by architecture — not by discipline. The sim couldn't drift from the firmware because there was nothing to drift.
- Verify against source, not documentation — including our own. The first real bug of the session was in our own plan.
- First light was falsifiable — one effect chosen so any failure mode pointed at exactly one layer.
- QA as a ratchet — every rule that mattered (name prefix, param effectiveness, no unmapped writes, determinism) became a check the moment it was articulated, so it could never silently regress.
- Render frames and look at them. The contact-sheet harness caught more real issues than any other tool — including issues the metrics quantified (a 66.7% single-frame luminance cliff) and issues only eyes catch (muddy, sparse, boring).
- Preserve the approved default. Every feature added — palettes, lightning, accumulate modes — kept "Default" pixel-identical to the look that was already loved. New drama is always opt-in.
- Frame-coherent randomness — persistent choices hash stable inputs, hw_random8() is only for ephemeral flicker — which is what makes the sim deterministic, runs reproducible by seed, and effects frame-rate-independent on the device.
- The wall gets the last word. Segment flags, recycled buffers, version-keyed caches: the three lessons no simulator could have taught, now encoded as guards, docs, and a dev server.

## 11 · Artifacts

Thing | Where
The simulator (interactive) | sign-preview/simulator/ — deep-linkable via ?fx=CHARGE%20Storm&pal=250
All effect logic (both targets) | wled/usermods/tedxfargo/charge_fx.h
Shim + QA + soak + visual harness | sim/ — qa.sh, test_native.sh, render_dump.mjs, render_sheets.py, serve.py
Rebuild the firmware tree from nothing | sh tools/setup_wled.sh --build
Operator handoff (workflows, hardware truths) | docs/HANDOFF-FIRMWARE.md
Design spec & executed plan | docs/superpowers/specs/2026-07-16-tedxfargo-effects-design.md, docs/superpowers/plans/2026-07-16-tedxfargo-effects-firstcut.md

← the sign build story the simulator wiring & WLED

TEDxFargo CHARGE 2026 · effects built July 16–17, 2026, by Blaine (at the browser, then at the wall) and Claude (in the loop) · 16 effects · 459 pixels · one header ⚡

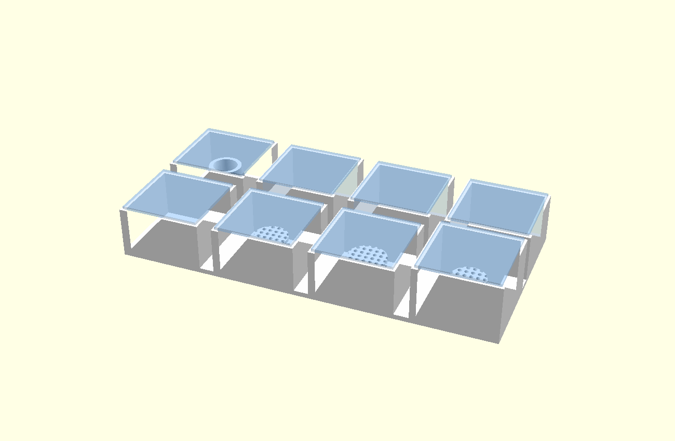
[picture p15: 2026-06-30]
docs/img/lens-matrix-assembled.png

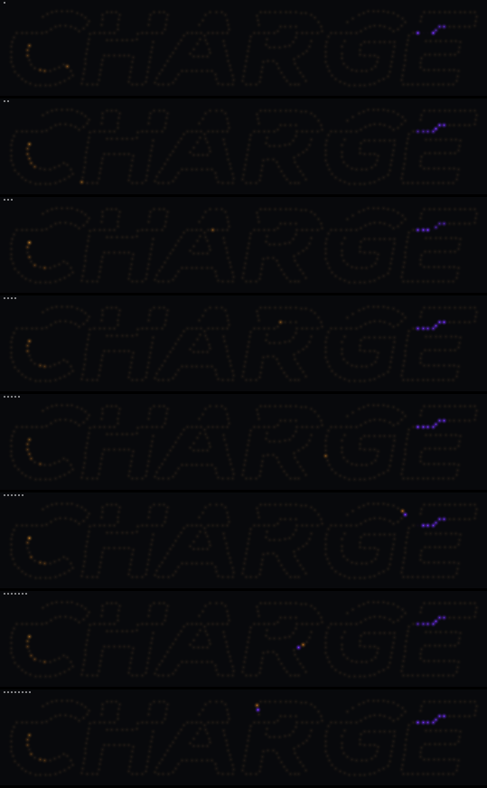
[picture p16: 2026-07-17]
docs/build-story/img/ants.png

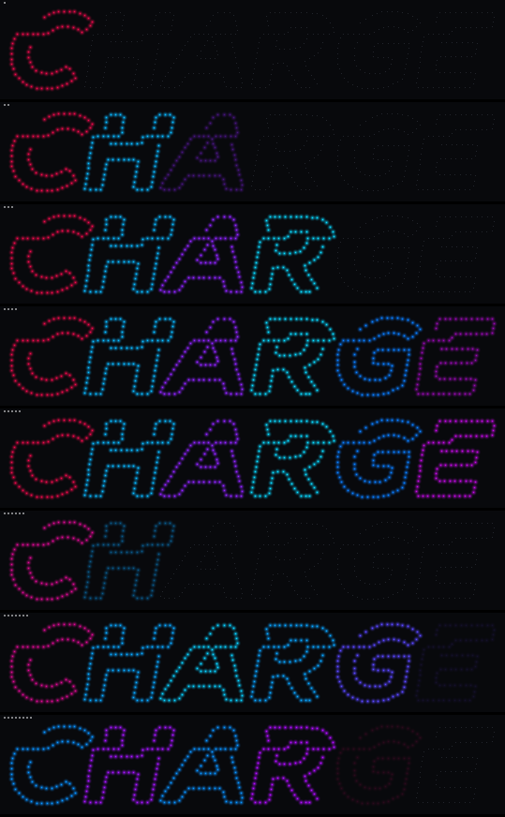
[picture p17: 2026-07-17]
docs/build-story/img/boot-letters.png

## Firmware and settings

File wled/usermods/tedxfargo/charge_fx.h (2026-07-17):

// TEDxFargo CHARGE — custom effect mode functions.
//
// SHARED SOURCE OF TRUTH: this exact file compiles into BOTH the WLED firmware
// (via tedxfargo.cpp, after #include "wled.h") and the browser simulator (via
// sim/sim_main.cpp, after #include "wled_shim.h"). It must therefore use only
// the API surface the shim mirrors:
//   SEGMENT.fill/.setPixelColorXY/.is2D/.speed/.intensity/.custom1..3/.check1..3
//   SEGENV.step/.aux0/.aux1/.call
//   strip.now, hw_random8(), qsub8(), color_fade(), color_blend(), RGBW32, BLACK
//   pgm_read_byte/pgm_read_word + the charge_geometry.h tables
// plus the two platform-glue functions declared below (charge_audio*), which
// tedxfargo.cpp implements from the audioreactive usermod and the sim
// implements from a JS-settable level (synthetic beat or real microphone).
// Do NOT include WLED headers here. (Editor lint on this file standalone is
// expected noise — it only compiles after wled.h or wled_shim.h.)
//
// DESIGN RULES for these effects:
// - Chain order IS tube order (greedy wiring), so "1D inside the letters"
//   means iterating a letter's contiguous chain range; the whole 0..458 chain
//   is one continuous tube path through all six letters.
// - Persistent randomness must be FRAME-COHERENT: derive it from charge_hash()
//   of stable inputs (letter, index, time window). hw_random8() is only for
//   ephemeral per-frame noise (flicker, sparks). This keeps every effect
//   deterministic in the simulator and frame-rate independent on the device.
// - Timers compare wrap-safe: (int32_t)(now - deadline) >= 0.
// - No allocation, no static mutable state; per-effect state only in SEGENV.
// - custom3 is a 5-bit slider in WLED (0..31) — avoid it; use custom1/2.
#pragma once
#include <stdint.h>
#include "charge_geometry.h"

#define CHARGE_CYAN     RGBW32(0, 255, 255, 0)     // electric CHARGE cyan
#define CHARGE_TEDX_RED RGBW32(235, 0, 40, 0)      // TEDx brand red (#EB0028)

// platform glue — smoothed audio level 0..255 and beat/peak flag.
// Firmware: audioreactive um_data (volumeSmth/samplePeak, with WLED's
// simulateSound fallback). Simulator: JS-fed (synthetic beat or microphone).
uint8_t charge_audio();
uint8_t charge_audio_peak();

// ---------- shared helpers over the geometry tables ----------
static inline uint16_t charge_lstart(uint8_t L) { return pgm_read_word(&CHARGE_LETTER_START[L]); }
static inline uint16_t charge_lcount(uint8_t L) { return pgm_read_word(&CHARGE_LETTER_COUNT[L]); }
static inline void charge_setpx(uint16_t i, uint32_t c) {
  SEGMENT.setPixelColorXY(pgm_read_byte(&CHARGE_COL[i]), pgm_read_byte(&CHARGE_ROW[i]), c);
}
// chain-position with wraparound (for effects that treat the chain as a loop)
static inline void charge_setpx_mod(int32_t i, uint32_t c) {
  int32_t n = CHARGE_NUM_PIXELS;
  charge_setpx((uint16_t)(((i % n) + n) % n), c);
}
// deterministic integer hash (lowbias32) — frame-coherent pseudo-randomness
static inline uint32_t charge_hash(uint32_t x) {
  x ^= x >> 16; x *= 0x7feb352dU; x ^= x >> 15; x *= 0x846ca68bU; x ^= x >> 16;
  return x;
}
// 0..255..0 triangle wave over `period` ms (period >= 2)
static inline uint8_t charge_tri8(uint32_t t, uint32_t period) {
  uint32_t ph = t % period, half = period / 2;
  uint32_t v = (ph < half) ? (ph * 255) / half : ((period - ph) * 255) / half;
  return (uint8_t)v;
}

// ---------- mini gradient palettes (goblin-curated, 4 stops each) ----------
// Effects with a "Palette" slider map it as index = custom / 32 (8 palettes).
struct ChargePal { uint32_t c[4]; };
static const ChargePal CHARGE_PALS[8] = {
  {{ CHARGE_CYAN, RGBW32(0,120,255,0), RGBW32(180,0,255,0), CHARGE_TEDX_RED }},   // 0 brand trip
  {{ RGBW32(255,30,0,0), RGBW32(255,110,0,0), RGBW32(255,220,40,0), RGBW32(255,255,255,0) }}, // 1 fire
  {{ RGBW32(255,0,0,0), RGBW32(255,255,0,0), RGBW32(0,255,80,0), RGBW32(0,80,255,0) }},       // 2 rainbow
  {{ RGBW32(40,255,40,0), RGBW32(0,200,80,0), RGBW32(180,255,0,0), RGBW32(230,255,230,0) }},  // 3 slime
  {{ RGBW32(255,0,180,0), RGBW32(120,0,255,0), RGBW32(0,255,255,0), RGBW32(255,255,0,0) }},   // 4 psychedelic
  {{ CHARGE_TEDX_RED, RGBW32(255,255,255,0), CHARGE_TEDX_RED, RGBW32(40,0,8,0) }},            // 5 TEDx
  {{ RGBW32(0,0,255,0), RGBW32(0,255,255,0), RGBW32(255,255,255,0), RGBW32(0,120,255,0) }},   // 6 electric ice
  {{ RGBW32(255,140,0,0), RGBW32(255,0,90,0), RGBW32(140,0,255,0), RGBW32(0,255,200,0) }},    // 7 sunset acid
};
static inline uint32_t charge_palette(uint8_t pal, uint8_t pos) {
  const ChargePal &P = CHARGE_PALS[pal & 7];
  uint8_t seg = pos / 85; if (seg > 2) seg = 2;
  uint8_t frac = (uint8_t)((pos - seg * 85) * 3);
  return color_blend(P.c[seg], P.c[seg + 1], frac);
}
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

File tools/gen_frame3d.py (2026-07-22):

#!/usr/bin/env python3
"""Generate docs/sign-preview/frame-3d.html — rotatable WebGL assembly view.
Loads the REAL rendered STLs, applies each part's install transform into
board coordinates (z=0 plate back, +z into the cavity), quantizes to int16,
and embeds everything in one self-contained page (no external libraries).
Board plates / bolt outline / pixels / controller are synthesized from the
layout data so the giant board meshes stay out of the page."""
import base64, json, math, re, struct

def grab(txt, name):
    return eval(re.search(re.escape(name) + r"\s*=\s*(\[.*?\]);", txt, re.S).group(1))

def load_stl(path):
    data = open(path, "rb").read()
    if data[:5] == b"solid" and b"facet" in data[:300]:
        tris, cur = [], []
        for line in data.decode(errors="replace").splitlines():
            line = line.strip()
            if line.startswith("vertex"):
                cur.append(tuple(float(v) for v in line.split()[1:4]))
                if len(cur) == 3:
                    tris.append(cur); cur = []
        return tris
    n = struct.unpack("<I", data[80:84])[0]
    out = []
    for i in range(n):
        f = struct.unpack("<9f", data[84 + i*50 + 12:84 + i*50 + 48])
        out.append([(f[0], f[1], f[2]), (f[3], f[4], f[5]), (f[6], f[7], f[8])])
    return out

bl = open("src/parts/board_layout.scad").read()
fl = open("src/parts/frame_layout.scad").read()
PXM = json.load(open("src/parts/bolt_pixmap.json"))["pixels"]
bb_plates, bb_paths = grab(bl, "bb_plates"), grab(bl, "bb_paths")
fr_joint = grab(fl, "fr_joint")
fr_leg, fr_feet, fr_handle = grab(fl, "fr_leg"), grab(fl, "fr_feet"), grab(fl, "fr_handle")
fr_ctl_ext = grab(fl, "fr_ctl_ext")
JX, JY = fr_joint
Z1 = 50.4

parts = []          # (group, color, tris)
def add(group, color, tris):
    parts.append((group, color, tris))

def xform(tris, fn):
    return [[fn(v) for v in t] for t in tris]

# frame segments: print = board - clip origin
for seg, (ox, oy) in {1: (-3.5, -3.5), 2: (205, -3.5),
                      3: (205, 300), 4: (-3.5, 300)}.items():
    add("frame", "#8b94a1", xform(load_stl(f"stl/frame_seg{seg}.stl"),
        lambda v, ox=ox, oy=oy: (v[0] + ox, v[1] + oy, v[2])))
# panels: print = Rx180 . (board + t)  ->  board = (x, ey1 - y, Z1 - z)
for i in range(4):
    ex0 = 0.3 if i in (0, 2) else JX - 2.7
    ey1 = JY + 2.7 if i in (0, 1) else 549.7
    add("panels", "#57637a", xform(load_stl(f"stl/frame_panel{i+1}.stl"),
        lambda v, a=ex0, b=ey1: (v[0] + a, b - v[1], Z1 - v[2])))
# straps: local (u, v, z) -> installed board coords
for n, fn in ((1, lambda v: (v[0], 255 - v[1], v[2])),
              (2, lambda v: (v[0], 255 - v[1], v[2])),
              (3, lambda v: (126 + v[1], v[0], v[2])),
              (4, lambda v: (153 + v[1], v[0], v[2]))):
    add("straps", "#7ad48a", xform(load_stl(f"stl/strap_s{n}.stl"), fn))
# legs, handles, feet, keys
leg = load_stl("stl/frame_leg.stl")
for lx, ly in fr_leg:
    add("hardware", "#e8ebef", xform(leg, lambda v, a=lx, b=ly: (v[0]+a, v[1]+b, v[2]+1)))
hnd = load_stl("stl/frame_handle.stl")
for h in fr_handle:
    cx = (h[2] + h[3]) / 2
    add("hardware", "#e8ebef", xform(hnd,
        lambda v, a=cx: (v[0] + a, v[1] + 575.5, v[2] + Z1 - 15)))
ft = load_stl("stl/frame_foot.stl")
for fx in fr_feet:
    add("hardware", "#e8ebef", xform(ft,
        lambda v, a=fx: (v[0] + a, v[2] - 9.5, v[1] + 23)))
key = load_stl("stl/frame_key.stl")
for fn in (lambda v: (JX + v[0], 3.5 + v[2], 19 + v[1]),
           lambda v: (JX + v[0], 542.5 + v[2], 19 + v[1]),
           lambda v: (3.5 + v[2], JY + v[0], 19 + v[1]),
           lambda v: (402.5 + v[2], JY + v[0], 19 + v[1])):
    add("hardware", "#e8ebef", xform(key, fn))

# synthesized board: plates, bolt ribbon, pixels, controller
def box(x0, y0, z0, x1, y1, z1):
    c = [(x0,y0,z0),(x1,y0,z0),(x1,y1,z0),(x0,y1,z0),
         (x0,y0,z1),(x1,y0,z1),(x1,y1,z1),(x0,y1,z1)]
    f = [(0,2,1),(0,3,2),(4,5,6),(4,6,7),(0,1,5),(0,5,4),
         (2,3,7),(2,7,6),(1,2,6),(1,6,5),(3,0,4),(3,4,7)]
    return [[c[a], c[b], c[d]] for a, b, d in f]
pl = []
for x0, x1, y0, y1 in bb_plates:
    pl += box(x0, y0, -2, x1, y1, 0)
add("board", "#1d232c", pl)
rib = []
for p in bb_paths:
    for i in range(len(p) - 1):
        a, b = p[i], p[i+1]
        rib.append([(a[0], a[1], -2), (b[0], b[1], -2), (b[0], b[1], -12)])
        rib.append([(a[0], a[1], -2), (b[0], b[1], -12), (a[0], a[1], -12)])
add("board", "#dfe3e8", rib)      # white channel liner walls
# pixel hardware, rear-visible: white collar liner rings through the plate
# + dark bullet bodies punching back through the strap pass holes
def ringpts(cx, cy, r, z, n=12):
    return [(cx + r*math.cos(6.2832*k/n), cy + r*math.sin(6.2832*k/n), z)
            for k in range(n)]
def tube(cx, cy, r, z0, z1, n=12):
    a, b = ringpts(cx, cy, r, z0, n), ringpts(cx, cy, r, z1, n)
    return [t for k in range(n) for t in
            ([a[k], a[(k+1) % n], b[(k+1) % n]], [a[k], b[(k+1) % n], b[k]])]
def disc(cx, cy, r, z, n=12):
    a = ringpts(cx, cy, r, z, n)
    return [[(cx, cy, z), a[k], a[(k+1) % n]] for k in range(n)]
def annulus(cx, cy, r0, r1, z, n=12):
    a, b = ringpts(cx, cy, r0, z, n), ringpts(cx, cy, r1, z, n)
    return [t for k in range(n) for t in
            ([a[k], b[k], b[(k+1) % n]], [a[k], b[(k+1) % n], a[(k+1) % n]])]
collars, bullets = [], []
for p in PXM:
    collars += tube(p["x"], p["y"], 8, -2, 2) + annulus(p["x"], p["y"], 6, 8, 2)
    bullets += tube(p["x"], p["y"], 6, 0, 14)
add("board", "#dfe3e8", collars)
add("board", "#2a323d", bullets)
# animated LED faces: front lens disc + rear glow cap per pixel (72 verts ea)
led_pos, led_meta = [], []
for p in PXM:
    for t in disc(p["x"], p["y"], 6, -2.3) + disc(p["x"], p["y"], 5, 14.3):
        led_pos += [c for v in t for c in v]
    led_meta.append({"c": p["chain"], "x": p["x"], "y": p["y"],
                     "z": 1 if p["color"] == "red" else 0})
ec = (fr_ctl_ext[0][0] + fr_ctl_ext[1][0]) / 2
add("controller", "#d9a017", box(-26.5, ec - 64.5, 0.4, -3.5, ec + 64.5, Z1))

# quantize + encode
enc, total = [], 0
for group, color, tris in parts:
    vid, verts, idx = {}, [], []
    for t in tris:
        for v in t:
            k = tuple(round(c, 2) for c in v)
            if k not in vid:
                vid[k] = len(verts); verts.append(k)
            idx.append(vid[k])
    mins = [min(v[i] for v in verts) for i in range(3)]
    maxs = [max(v[i] for v in verts) for i in range(3)]
    scale = [max((maxs[i] - mins[i]) / 32760.0, 1e-6) for i in range(3)]
    qv = b"".join(struct.pack("<3h", *[int(round((v[i] - mins[i]) / scale[i]))
                                       for i in range(3)]) for v in verts)
    qi = b"".join(struct.pack("<I", i) for i in idx)
    total += len(qv) + len(qi)
    enc.append({"g": group, "c": color, "n": len(idx),
                "min": mins, "sc": scale,
                "v": base64.b64encode(qv).decode(),
                "i": base64.b64encode(qi).decode()})
print(f"parts: {len(enc)}, payload {total/1024:.0f} KB raw")

LED = json.dumps({"pos": base64.b64encode(
    struct.pack("<%df" % len(led_pos), *led_pos)).decode(), "meta": led_meta})
DATA = json.dumps(enc)
page = """<title>Bolt backer frame — 3D assembly</title>
<style>
:root { --bg:#101318; --card:#171c23; --ink:#e8ebef; --mut:#97a0ac;
  --line:#2a323d; --accent:#ffc93c; }
@media (prefers-color-scheme: light) { :root { --bg:#eef0f3; --card:#ffffff;
  --ink:#1a2027; --mut:#5b6572; --line:#d7dce2; --accent:#c79616; } }
:root[data-theme="dark"] { --bg:#101318; --card:#171c23; --ink:#e8ebef;
  --mut:#97a0ac; --line:#2a323d; --accent:#ffc93c; }
:root[data-theme="light"] { --bg:#eef0f3; --card:#ffffff; --ink:#1a2027;
  --mut:#5b6572; --line:#d7dce2; --accent:#c79616; }
html, body { height:100%; }
body { margin:0; background:var(--bg); color:var(--ink); overflow:hidden;
  font:14px/1.4 -apple-system, "Segoe UI", system-ui, sans-serif; }
#c { position:fixed; inset:0; width:100%; height:100%; touch-action:none; }
#hud { position:fixed; top:14px; left:14px; background:var(--card);
  border:1px solid var(--line); border-radius:8px; padding:12px 14px;
  max-width:250px; }
#hud h1 { font-size:14px; margin:0 0 2px; }
#hud p { font-size:11px; color:var(--mut); margin:0 0 8px; }
label { display:inline-flex; align-items:center; gap:5px; margin:2px 10px 2px 0;
  font-size:12px; cursor:pointer; user-select:none; }
.sw { width:10px; height:10px; border-radius:2px; display:inline-block; }
</style>
<canvas id="c"></canvas>
<div id="hud">
  <h1>Bolt backer frame — assembly</h1>
  <p>drag rotate · wheel zoom · shift-drag pan<br>view from the back; front
  face (bolt) points away at start</p>
  <div id="tg"></div>
  <p style="margin:8px 0 2px">led effect</p><div id="fx"></div>
</div>
<script>
const PARTS = __DATA__;
const LEDS = __LED__;
const groups = {frame:true, panels:false, straps:true, hardware:true,
                board:true, controller:true, leds:true};
const gcol = {frame:"#8b94a1", panels:"#57637a", straps:"#7ad48a",
              hardware:"#e8ebef", board:"#dfe3e8", controller:"#d9a017",
              leds:"#ffc93c"};
const tg = document.getElementById("tg");
for (const g in groups) {
  const l = document.createElement("label");
  const cb = document.createElement("input");
  cb.type = "checkbox"; cb.checked = groups[g];
  cb.onchange = () => { groups[g] = cb.checked; };
  const sw = document.createElement("span");
  sw.className = "sw"; sw.style.background = gcol[g];
  l.append(cb, sw, document.createTextNode(g));
  tg.append(l);
}
const cv = document.getElementById("c");
const gl = cv.getContext("webgl2", {antialias:true});
const vs = `#version 300 es
in vec3 p; uniform mat4 mvp; out vec3 w;
void main(){ w = p; gl_Position = mvp * vec4(p, 1.0); }`;
const fs = `#version 300 es
precision highp float; in vec3 w; uniform vec3 col, eye; out vec4 o;
void main(){
  vec3 n = normalize(cross(dFdx(w), dFdy(w)));
  vec3 L = normalize(eye - w);
  float d = 0.34 + 0.62 * abs(dot(n, L)) + 0.18 * pow(abs(dot(n, L)), 24.0);
  o = vec4(col * d, 1.0); }`;
function sh(t, s){ const h = gl.createShader(t); gl.shaderSource(h, s);
  gl.compileShader(h); return h; }
const pr = gl.createProgram();
gl.attachShader(pr, sh(gl.VERTEX_SHADER, vs));
gl.attachShader(pr, sh(gl.FRAGMENT_SHADER, fs));
gl.linkProgram(pr); gl.useProgram(pr);
const uMvp = gl.getUniformLocation(pr, "mvp"),
      uCol = gl.getUniformLocation(pr, "col"),
      uEye = gl.getUniformLocation(pr, "eye");
const vs2 = `#version 300 es
in vec3 p; in vec3 c; uniform mat4 mvp; out vec3 vc;
void main(){ vc = c; gl_Position = mvp * vec4(p, 1.0); }`;
const fs2 = `#version 300 es
precision highp float; in vec3 vc; out vec4 o;
void main(){ o = vec4(vc, 1.0); }`;
const pr2 = gl.createProgram();
gl.attachShader(pr2, sh(gl.VERTEX_SHADER, vs2));
gl.attachShader(pr2, sh(gl.FRAGMENT_SHADER, fs2));
gl.linkProgram(pr2);
const uMvp2 = gl.getUniformLocation(pr2, "mvp");
function b64(s){ const b = atob(s), a = new Uint8Array(b.length);
  for (let i = 0; i < b.length; i++) a[i] = b.charCodeAt(i); return a.buffer; }
const meshes = PARTS.map(p => {
  const q = new Int16Array(b64(p.v)), nv = q.length / 3;
  const f = new Float32Array(q.length);
  for (let i = 0; i < nv; i++) for (let k = 0; k < 3; k++)
    f[i*3+k] = p.min[k] + q[i*3+k] * p.sc[k];
  const vao = gl.createVertexArray(); gl.bindVertexArray(vao);
  const vb = gl.createBuffer(); gl.bindBuffer(gl.ARRAY_BUFFER, vb);
  gl.bufferData(gl.ARRAY_BUFFER, f, gl.STATIC_DRAW);
  gl.enableVertexAttribArray(0);
  gl.vertexAttribPointer(0, 3, gl.FLOAT, false, 0, 0);
  const ib = gl.createBuffer(); gl.bindBuffer(gl.ELEMENT_ARRAY_BUFFER, ib);
  gl.bufferData(gl.ELEMENT_ARRAY_BUFFER, new Uint32Array(b64(p.i)), gl.STATIC_DRAW);
  const c = parseInt(p.c.slice(1), 16);
  return {vao, n: p.n, g: p.g,
          col: [(c>>16&255)/255, (c>>8&255)/255, (c&255)/255]};
});
// LED mesh: static positions + per-frame color buffer (72 verts/pixel)
const ledPos = new Float32Array(b64(LEDS.pos));
const nled = LEDS.meta.length;
const ledCol = new Float32Array(nled * 72 * 3);
const ledVao = gl.createVertexArray(); gl.bindVertexArray(ledVao);
const lpb = gl.createBuffer(); gl.bindBuffer(gl.ARRAY_BUFFER, lpb);
gl.bufferData(gl.ARRAY_BUFFER, ledPos, gl.STATIC_DRAW);
gl.enableVertexAttribArray(0); gl.vertexAttribPointer(0, 3, gl.FLOAT, false, 0, 0);
const lcb = gl.createBuffer(); gl.bindBuffer(gl.ARRAY_BUFFER, lcb);
gl.bufferData(gl.ARRAY_BUFFER, ledCol, gl.DYNAMIC_DRAW);
gl.enableVertexAttribArray(1); gl.vertexAttribPointer(1, 3, gl.FLOAT, false, 0, 0);
function hsv(h, s2, v){ const i = Math.floor(h*6), f = h*6 - i;
  const a = v*(1-s2), q = v*(1-f*s2), t2 = v*(1-(1-f)*s2);
  return [[v,t2,a],[q,v,a],[a,v,t2],[a,q,v],[t2,a,v],[v,a,q]][((i%6)+6)%6]; }
const FX = {
  "as-built": p => p.z ? [1,.30,.30] : [1,.78,.22],
  chase: (p,t) => { const d = (p.c - t*40%137 + 137) % 137;
    const v = Math.max(.04, 1 - d/14);
    return p.z ? [v,v*.28,v*.28] : [v,v*.78,v*.2]; },
  rainbow: (p,t) => hsv((p.c/137 + t*.10) % 1, 1, 1),
  wave: (p,t) => hsv(((p.x + p.y)/800 + t*.22) % 1, .92, 1),
  sparkle: (p,t) => { const s2 = Math.sin(p.c*127.1 +
      Math.floor(t*7)*311.7) * 43758.55, r = s2 - Math.floor(s2);
    return r > .9 ? [1,1,.92] : [.13,.09,.02]; },
  breathe: (p,t) => { const v = .25 + .75*(.5 + .5*Math.sin(t*2.2 -
      (p.x+p.y)/260));
    return p.z ? [v,v*.26,v*.26] : [v,v*.76,v*.2]; },
};
let fx = "chase";
const fxd = document.getElementById("fx");
for (const name in FX) {
  const b = document.createElement("button");
  b.textContent = name;
  b.style.cssText = "margin:2px 4px 2px 0;padding:3px 8px;font-size:11px;" +
    "border:1px solid var(--line);border-radius:5px;background:var(--card);" +
    "color:var(--ink);cursor:pointer";
  b.onclick = () => { fx = name;
    [...fxd.children].forEach(x => x.style.borderColor = "var(--line)");
    b.style.borderColor = "var(--accent)"; };
  if (name === fx) b.style.borderColor = "var(--accent)";
  fxd.append(b);
}
function ledTick(t){
  const f = FX[fx];
  for (let i = 0; i < nled; i++) {
    const c = f(LEDS.meta[i], t);
    for (let k = 0; k < 36; k++) ledCol.set(c, (i*72 + k)*3);
    const r = [c[0]*.45, c[1]*.45, c[2]*.45];
    for (let k = 36; k < 72; k++) ledCol.set(r, (i*72 + k)*3);
  }
  gl.bindBuffer(gl.ARRAY_BUFFER, lcb);
  gl.bufferSubData(gl.ARRAY_BUFFER, 0, ledCol);
}
let th = 0.6, ph = 0.42, R = 900, tgt = [205, 275, 15];
function mat(){
  const cw = cv.clientWidth, chh = cv.clientHeight;
  const eye = [tgt[0] + R*Math.cos(ph)*Math.sin(th),
               tgt[1] + R*Math.sin(ph),
               tgt[2] + R*Math.cos(ph)*Math.cos(th)];
  const f = norm(sub(tgt, eye)), s = norm(cross(f, [0,1,0])), u = cross(s, f);
  const V = [s[0],u[0],-f[0],0, s[1],u[1],-f[1],0, s[2],u[2],-f[2],0,
             -dot(s,eye), -dot(u,eye), dot(f,eye), 1];
  const n = 5, fa = 6000, a = cw/chh, t = Math.tan(0.45)*n;
  const P = [n/(t*a),0,0,0, 0,n/t,0,0, 0,0,-(fa+n)/(fa-n),-1,
             0,0,-2*fa*n/(fa-n),0];
  return [mul(P, V), eye];
}
const sub=(a,b)=>[a[0]-b[0],a[1]-b[1],a[2]-b[2]];
const dot=(a,b)=>a[0]*b[0]+a[1]*b[1]+a[2]*b[2];
const cross=(a,b)=>[a[1]*b[2]-a[2]*b[1],a[2]*b[0]-a[0]*b[2],a[0]*b[1]-a[1]*b[0]];
const norm=a=>{const l=Math.hypot(...a);return[a[0]/l,a[1]/l,a[2]/l];};
function mul(A,B){ const o=new Array(16);
  for(let r=0;r<4;r++)for(let c2=0;c2<4;c2++){let s2=0;
    for(let k=0;k<4;k++)s2+=A[k*4+r]*B[c2*4+k]; o[c2*4+r]=s2;} return o; }
let drag=0, px0=0, py0=0;
cv.addEventListener("pointerdown", e=>{drag=e.shiftKey?2:1;px0=e.clientX;py0=e.clientY;
  cv.setPointerCapture(e.pointerId);});
cv.addEventListener("pointermove", e=>{
  if(!drag) return;
  const dx=e.clientX-px0, dy=e.clientY-py0; px0=e.clientX; py0=e.clientY;
  if(drag===1){ th-=dx*0.006; ph=Math.max(-1.5,Math.min(1.5,ph+dy*0.006)); }
  else { const s=R*0.0012;
    const ey=[Math.cos(ph)*Math.sin(th),Math.sin(ph),Math.cos(ph)*Math.cos(th)];
    const rt=norm(cross([0,1,0],ey)), up=cross(ey,rt);
    tgt=[tgt[0]+rt[0]*dx*s+up[0]*dy*s, tgt[1]+rt[1]*dx*s+up[1]*dy*s,
         tgt[2]+rt[2]*dx*s+up[2]*dy*s]; }});
cv.addEventListener("pointerup", ()=>drag=0);
cv.addEventListener("wheel", e=>{e.preventDefault();
  R=Math.max(120,Math.min(3500,R*Math.exp(e.deltaY*0.001)));},{passive:false});
function bg(){
  const s=getComputedStyle(document.documentElement).getPropertyValue("--bg").trim();
  const c=parseInt(s.slice(1),16);
  return [(c>>16&255)/255,(c>>8&255)/255,(c&255)/255];
}
function frame(){
  const d=window.devicePixelRatio||1;
  if(cv.width!==cv.clientWidth*d||cv.height!==cv.clientHeight*d){
    cv.width=cv.clientWidth*d; cv.height=cv.clientHeight*d;}
  gl.viewport(0,0,cv.width,cv.height);
  const b=bg(); gl.clearColor(b[0],b[1],b[2],1);
  gl.enable(gl.DEPTH_TEST);
  gl.clear(gl.COLOR_BUFFER_BIT|gl.DEPTH_BUFFER_BIT);
  const [M,eye]=mat();
  gl.useProgram(pr);
  gl.uniformMatrix4fv(uMvp,false,new Float32Array(M));
  gl.uniform3fv(uEye,eye);
  for(const m of meshes){ if(!groups[m.g]) continue;
    gl.bindVertexArray(m.vao); gl.uniform3fv(uCol,m.col);
    gl.drawElements(gl.TRIANGLES,m.n,gl.UNSIGNED_INT,0); }
  if (groups.leds) {
    ledTick(performance.now()/1000);
    gl.useProgram(pr2);
    gl.uniformMatrix4fv(uMvp2,false,new Float32Array(M));
    gl.bindVertexArray(ledVao);
    gl.drawArrays(gl.TRIANGLES, 0, nled*72);
  }
  requestAnimationFrame(frame);
}
frame();
</script>"""
page = page.replace("__DATA__", DATA).replace("__LED__", LED)
open("docs/sign-preview/frame-3d.html", "w").write(page)
print("wrote docs/sign-preview/frame-3d.html (%d KB)" % (len(page) // 1024))

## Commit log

2026-06-24 Initial CHARGE LED sign: design spec + coupon STL generator
    Parametric OpenSCAD system. First deliverable is the stackup test coupon
    (3-cell depth ladder, merged press-fit collars, swappable diffuser panels)
    plus the approved design spec.
    [bullet-collar.stl, collar.scad, config.scad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]
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2026-06-25 Add slide-over diffuser caps; note spine connection approach in spec
    Flat drop-in panels printed too loose to grip. Add diffuser_cap(t): a diffuser
    top + skirt that slides over the OUTSIDE of any chimney (one cap fits all,
    works on the already-printed coupon), easy on/off for testing. Default
    cap_fit_clear=0.4 (0.20mm/side). Flat diffuser_panel kept for the final glued
    option. Also recorded the back-spine (2040 + T-nut) connection decision in spec.
    [cap_1mm.scad, cap_2mm.scad, cap_3mm.scad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]
2026-06-25 Replace slide-over cap with flanged-plug diffuser lid
    The touching chimney row leaves no side clearance for a skirt, so the cap can't
    seat. diffuser_lid(t) instead: a plug drops into the opening (snug slip, won't
    slide) and a flange overhangs ~the wall width to rest on the rim (can't fall in),
    lifting straight off for swaps. Works on all 3 chimneys of the existing coupon.
    Cap module kept for possible isolated-column use on the real letters.
    [cap_1mm.scad, cap_2mm.scad, cap_3mm.scad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]
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2026-06-25 Add 3x3 grid coupon; tighten lid plug to a friction fit
    coupon_body now takes a rows arg; coupon3x3 = 3 depth-ladder rows (9 wells,
    3 distances x 3 rows, ~105x105mm) for testing a full matrix of lens combos at
    once. Drop lid_plug_clear 0.5 -> 0.2 (0.10mm/side) after the loose first prints;
    PETG plug in a PLA hole grips well there.
    [config.scad, coupon.scad, coupon3x3.scad]
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2026-06-26 Add lightning-bolt test piece (option C): parametric shell + lens
    First real channel-letter piece from the generator. ~18mm channel (option C),
    372mm zig-zag centerline, 17 collars at ~22mm pitch (collision-safe spacing),
    15mm LED gap. Two parts: bolt_shell (rear-down) + bolt_lens (bolt-shaped diffuser
    with locating lip). 132x292mm, fits the bed, prints support-free. Validates the
    whole letter pipeline (SVG/path -> stroke -> collars -> lens) on a keepable piece.
    [bolt.scad, bolt_lens.scad, bolt_shell.scad]
2026-06-26 Add short (~10mm) bolt variant; bolt_shell wall height now a param
    bolt_shell(wall_h) lets one lens cap any bolt height. bolt_shell_short = ~10mm
    tall (~4mm gap) to A/B against the tall 15mm-gap bolt with the same lens.
    [bolt.scad, bolt_shell_short.scad]
2026-06-27 Tighten bolt pitch to ~17mm (22 px) + add snap-over lens cap
    Tighter marquee pitch (collar-limited). bolt_overcap: a cap that wraps the whole
    bolt's outside (skirt grips the 22mm outer) - the slide-over lens that only failed
    on touching coupon chimneys now works on the isolated bolt. Top = diffuser; set up
    for 2-filament (clear top + white skirt via slicer height change).
    [bolt.scad, bolt_overcap.scad]
2026-06-29 Add over-cap fit-test chunks (0.2/0.1/0.0mm skirt clearance)
    cap_chunk(clear, marks): short straight cap segment to slide onto the printed
    bolt and feel the fit, without reprinting the whole cap. Dots = tighter.
    Current over-cap is 0.3 (loose); dial in the winner then set cap_clear.
    [bolt.scad, cap_fit_0p0.scad, cap_fit_0p1.scad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]
2026-06-29 Add inner-lens fit slices + fix chiral over-cap/lens mirror
    bolt.scad:
    - Pre-mirror bolt_overcap + bolt_lens: they print face-down and are flipped to
    seat, and the bolt footprint is chiral, so the un-mirrored flip lands a
    backwards bolt that won't register. Mirroring makes the flipped part a mere
    rotation of the bolt footprint -> aligns by eye.
    - Add lens_chunk(clear, marks): a short straight slice of the inner lens
    (face + locating lip) to dial in the channel press-fit without printing a
    whole bolt.
    lens_fit_0p4/0p3/0p2/0p1: lip clearances 0.4/0.3/0.2/0.1mm (1-4 dots, more =
    tighter), all tighter than the loose 0.6mm default.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
    [bolt.scad, lens_fit_0p1.scad, lens_fit_0p2.scad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]
2026-06-29 Add integrated lit-lens diffusion test matrix (8 cells, dual-material)
    Single-print, dual-material (white body + clear optic) diffuser cells to find
    the best even/sourceless glow recipe -- the optical coupon for the eventual
    TEDxFargo letter strokes. Prints plate-down (no flip/chirality issue); pixel
    inserts from the back.
    - src/lens_cell.scad: parametric lit_cell families A (perforated-mask cavity),
    R (reflector cone), B (clear gyroid fill), C (TIR cone puck); matrix_white +
    matrix_clear emit two co-registered STLs for nozzle assignment.
    - 8-cell 4x2 tray, per-cell dot labels, connecting base slab.
    - Research-tuned: perforated semi-transparent mask close to the LED, gap ~15mm,
    white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
    [lens_cell.scad, lens_matrix_preview.scad, lens_matrix_section.scad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]
2026-06-30 Finalize bolt-lens fit: -0.2 press-fit + labeled fit ladder
    - bolt_lip_clear -> -0.2 (0.2mm interference press-fit), chosen from the n0p2
    slice; bolt_lens.stl now prints the firm-snap fit.
    - lens_chunk gains an optional debossed `label` (clearance value) alongside the
    dot count; all 7 fit slices labeled.
    - Add interference slices lens_fit_0p0 / n0p1 / n0p2 (0.0 / -0.1 / -0.2).
    [bolt.scad, lens_fit_0p0.scad, lens_fit_0p1.scad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]
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2026-06-30 Document confirmed bolt-lens fit: -0.2 = perfect snap (PETG on white PLA)
    bolt_lip_clear = -0.2 (0.2mm interference, lip O18.2 -> 18.0 channel) verified as
    a perfect snap-in on the printed full lens with a clear-PETG lip on a white-PLA
    base. Provenance noted in the param comment.
    [bolt.scad]
2026-06-30 Fix pixel clearance in all matrix cells
    Pixels couldn't seat — interior optics sat in the insertion path. Fixes:
    - led_void 13 -> 14 (barrel O12 + clearance + hole-shrink margin)
    - add led_clear = 2.5mm vertical headroom above the dome tip before any solid
    optic (the clear FILL/PUCK ceilings were flush with the dome -> jammed)
    - masks: support the perforated disc on 3 spokes from the cell WALLS at disc
    height (entirely above the pixel) instead of floor legs that clipped the barrel
    Verified: pixel-envelope-vs-geometry intersection is empty across all 8 cells
    (src/parts/lens_pixel_collision.scad) + visual section check (lens_pixel_check.scad).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
    [lens_cell.scad, lens_pixel_check.scad, lens_pixel_collision.scad]
2026-06-30 Fix mask support: floor legs with flared feet (no floating cantilever)
    The wall-spoke mask supports from the pixel-clearance fix were long horizontal
    cantilevers off the cell walls -> slicer flagged "floating, needs support" (and
    the cavity is sealed, so support is unremovable). Revert to FLOOR-anchored legs
    (self-supporting, ~15deg lean) but with FLARED FEET that splay clear of the pixel
    barrel, then lean in to the disc edge. No support needed; pixel clearance still
    verified empty by lens_pixel_collision.scad.
    [lens_cell.scad]
2026-06-30 Lock in validated specs (docs/locked-specs.md)
    Consolidate finalized, print-validated parameters:
    - bolt lens fit -0.2 now material-robust (clear PETG + clear PLA both snap perfectly)
    - pixel datasheet documented in config.scad (dome O8 / barrel O12 / flange O13.6x2 /
    tip-to-flange 5.5 / dome_clear 4.0)
    - matrix pixel clearance (led_void 14, led_clear 2.5, flared-leg masks)
    - Adafruit-verified diffuser print recipe + two-color 3MF regen
    [bolt.scad, config.scad]
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2026-07-01 Rework two-color bolt lens as in-layer white/clear STRIPES on the viewer face
    Replace the (wrong) through-thickness bilayer with the intended in-layer split on
    the bottom/bed (viewer) layers:
    - V1: WHITE center stripe over the LED line + clear edges
    - V2: CLEAR center stripe + WHITE edges
    Params: lens_stripe_w (12mm center width), lens_white_t (0.4mm bed depth; set to
    bolt_lens_t for a full-thickness stripe). Lip stays clear. Confirmed by top-down
    render; 3MFs via make_3mf.py (white->filament 1, clear->filament 2).
    [bolt.scad, bolt_lens_2c_preview.scad, bolt_lens_v1_clear.scad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]
2026-07-01 Add 5-LED straight stroke test box (integrated lens, print lens-up)
    The A0 recipe (white reflector shell + integrated clear lens over a 15mm air gap)
    as a short straight stroke at the bolt's 17mm pixel pitch, for trying the
    integrated-lens + fuzzy-skin path. Prints plate-down / lens-up (lens is the top
    surface -> fuzzy-skinnable); NO supports (lens is an ~18mm bridge on both walls);
    pixels plug into the 5 collars from below. Two-material 3MF via make_3mf.py
    (white shell -> filament 1, clear lens -> filament 2). Params: tb_n/pitch/inner/gap.
    [testbox.scad, testbox_clear.scad, testbox_preview.scad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]
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2026-07-02 Wire up converged specs + self-contained handoff doc
    - docs/HANDOFF.md: full onboarding brief for a fresh session (project, hardware,
    validated diffusion recipe, 3-color letter cross-section, faithful widened-outline
    letter plan, bolt, repo map, gotchas, next steps).
    - locked-specs.md: fuzzy V3 winner (1.5mm/0.8mm), 3-color cross-section, faithful
    widened neon outline (+3mm/side -> 18mm), NO letter split -> ~250mm cap (widest
    letter H), TIGHT ~17mm pitch -> ~470px (budget 600).
    - letter_viz.scad / svg_bbox.scad: planning helpers; sign-preview/ letter web view.
    [letter_viz.scad, svg_bbox.scad]
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2026-07-04 Billboard pipeline: graph-based extractor, whole-word extraction, panelizer
    - centerline.py: junction-cluster graph decomposition (fixes the A; pairs
    crossing tubes by straightest continuation), whole-word capable
    - panelize.py: chamfer clearance field, auto-kern (widens kissing gaps
    A|R +1.2, R|G +5.9mm), straight-biased corridor cuts, bed-fit report
    - cutpreview.py: PPM + HTML/SVG cut-approval preview
    - 6 pieces all fit (H at 316.0 limit); 457 px; ~2.3kg
    - plus: integrated bolt v2, letter C 3-color tile, fuzz V5/V6, N-color 3MF
    [bolt.scad, bolt2_clear.scad, bolt2_preview.scad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]
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2026-07-04 Panelizer: pixel de-conflict (chord-aware placement, 14.5mm flange floor) + even rail hardware
    442 px (2 dropped at the A crossing, 3 ends re-spread), min spacing 14.8mm.
    Screws every ~130mm along both bands, nudged 20mm off seams, >=2/band/piece.
    Preview draws final pixel dots; tube overlap render artifact fixed.
    [cutpreview.py, panelize.py]
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2026-07-04 Pixel placement: relaxation solver replaces greedy stack; user-caught end gap fixed
    Even arc placement with pinned ends + iterative slide-apart relaxation;
    residual 13.0-14.5mm pairs kept as 'snug' (flange is 13.6) instead of
    dropped. 454 px, 1 drop (A crossing), min 14.2mm, no uncovered gaps
    (worst 22.9mm on-path has a fold pixel 9.3mm from midpoint).
    [word_layout.scad]
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2026-07-04 Kill non-manifold fuzz slivers: dead-band bump heights around the lens plane
    Root cause: bumps peaking within microns of the lens top (coplanar-ish
    CGAL unions -> micro-sliver edges, flagged by Bambu on pieces 4-6).
    Fixes: 0.02 height floor, off-lattice base offset (0.1504), and a
    +-50um dead-band around the plane snap in gen_pieces. make_3mf.py now
    audits every mesh's edge topology at build time — all 18 bodies clean.
    [piece.scad]
2026-07-04 Bolt options A/B: element-5 extraction (outline @570 + spine @251), A panelized
    Extractor: raster (.pgm) input + --target-h absolute scaling; panelize:
    --labels arg. A (in-band solid-stroke bolt): 7 pieces all fit, 471 px,
    sign 1.67m. B (570mm outline board): 182x593, 2 plates, 85 px, 2 seam
    neon-breaks computed. Discovery: outline bolt needs full scale — at 45%
    the twin channels collide (pixel physics); small bolt = single tube.
    [aword_data.scad, bolt5_data.scad, bolt5s_data.scad]
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2026-07-04 Element-6 bolt board: the real logo panel, 4 plates, built + verified
    The wrong-vector blocker is resolved. Board = element 6 (flat-top bolt
    fused with the X, ONE outline — the logo's actual left panel) at logo
    proportion (panel 2.06x letter cap), with the billboard's red single-
    stroke zigzag inside, hand-fit and clearance-audited legal (26mm rule,
    zero violations; element 5 turns out to be the red's slim-bolt shape).
    Board 410x550, FOUR plates via PIECEWISE seams (y=255 + per-row x at
    126/153) — a full-height vertical seam always grazes the X's near-
    vertical legs. Composer (bolt_compose6.py) scans seams with graze/
    corner/tangent-apex protection and perpendicular-true pullbacks
    (13/s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
    [aword_data.scad, board_layout.scad, bolt5_data.scad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]
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2026-07-04 Continuous mode: no gaps anywhere (word bridged, board crosses seams)
    User feedback "smooth all around, no gaps between line segments":
    - Word: tools/bridge_word.py joins each letter's stroke-end openings
    (55-107mm) -> all six letters are closed neon loops (R's bowl its own
    loop). Cuts/kerning/pixels untouched (454 px). 18 bodies rebuilt,
    all six 3MFs manifold-clean, 2190g.
    - Board: outline bridged into one closed loop; channels CROSS the plate
    joints (7 hairline lens joints replace pullback breaks); pixels/
    collars kept >=12.5mm off seams; ONE global fuzz field so the lens
    texture is continuous across joints. 137 px -> sign 591.
    - clearance_audit: wrap-aware self-skip for closed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
    [board_layout.scad, bolt_piece.scad, word_layout.scad]
2026-07-04 Restore CHARGE to the approved design; bolt keeps continuous mode @20mm
    The letterform bridging (597f956) restyled an approved, finalized
    design — reverted at the user's direction. Scope now explicit and
    documented: "no gaps" applies to the BOLT BOARD ONLY; the letters'
    open strokes are the font.
    - word_cuts.json restored from the pre-bridge state: 454 px, original
    letterforms/cuts/kerning. 18 bodies re-rendered; black/white weights
    match the approved card exactly; all 3MFs manifold-clean.
    - Board back at 20mm pitch (the 22mm detour only offset the reverted
    bridge pixels): 137 px, continuous, seam-avoiding. All 3MFs clean.
    - Sign total 591 of EXACTLY 600 owned (user-confirmed; strin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
    [word_layout.scad]
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2026-07-04 Filament layout: black+clear right (AMS, black backup), white left
    User-chosen H2D layout. All ten 3MFs repacked with filament order
    1=black 2=clear 3=white (right-nozzle pair adjacent); build scripts
    emit the same order going forward. Verified: black/white per-layer
    alternation stays cross-nozzle (purge-free); the single black->clear
    swap at ~z21 happens after black finishes -> prime tower (right
    column, ON) absorbs the bumped 700-800mm3 flush; AMS backup only
    exists on the right, so black-the-heavy-consumer belongs there.
    [gen_pieces.py]
2026-07-04 Fuzz bake-off v7/v8: uniform + jittered pyramid facet textures
    make_fuzz.py --mode=pyramid|pyramid-jitter (deterministic square-pyramid
    lattice sampled at CELL/4; jitter randomizes peak height/offset per
    cell). Testbox 2color 3MFs packed for the PETG bake-off alongside
    v3-v6 (user idea: "uniform but scattered" faceted lens).
    [testbox_v78.scad]
2026-07-04 V9 disco testbox (3.5mm/1.2mm uniform pyramids) + wrapper scale fix
    pyramid dats are sampled at CELL/4; the wrapper now picks the right
    surface scale per variant (V9 first rendered at 57% size — rebuilt).
    [testbox_v78.scad]
2026-07-06 V8 lens texture is the standard (PETG bake-off winner)
    Jittered pyramid facets 2.0mm/0.6mm replace V3 random frost in both
    generators (word + board); scad surface scale 1.5 -> 0.5 (pyramid dats
    sample at cell/4). User verdict: brightest/clearest/most uniform of
    v3-v9; slight LED visibility common to all candidates. Layouts and
    pixel data verified byte-stable — clear bodies need re-render (10),
    black/white untouched.
    [bolt_piece.scad, piece.scad]
2026-07-06 V8 production fixes: floated facet field, cell/3 sampling, per-piece seeds
    Three changes proven on the C (zero manifold warnings, 226k tris vs
    427k at first attempt):
    - pyramid fields now sit 0.02mm proud of the lens plane (min value
    0.1704 vs base offset 0.1504) — ramps crossing the plane left
    tangency lines the sample dead-band can't catch (3 edges at S=4
    seed 7, 1 at S=3; zero after floating the field)
    - S=3 sampling (0.67mm): the 0.4 nozzle is the real resolution limit;
    S=4 doubled the mesh for no printable difference
    - per-piece dat seeds (7+i) for draw diversity
    scad surface scales updated to 0.6667 accordingly.
    [bolt_piece.scad, piece.scad]
2026-07-06 V8 lenses final: all ten rendered; sliver war concluded
    Root causes fixed across the day: floated field (no lens-plane
    contact), dead-band snap removed for pyramid dats (it CREATED a
    coplanar micro-sliver plane at top+0.05), max-union tents (no jitter
    cliffs -> no thin-triangle population), per-plate fuzz crops (board
    renders 2.6x lighter). Residual: R/G/E/B4 roll 2-3 micro-edges from
    OpenSCAD ASCII-export quantization at large coordinates — validated
    benign (Bambu warns-but-slices; its import Fix welds them). Documented
    in the card. stl_heal.py deleted (its degenerate-drop punched holes —
    wrong tool). V8 clear weights: word 315g, board 118g (sign 3,100g).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
    [board_layout.scad, bolt_piece.scad]
2026-07-06 Remove zip-tie holes (light leaks); wood screws stay
    User caught it on the sliced C: every Ø3.2 through-hole in the black
    face is a lit pinprick with the plenum full of LEDs. Ties removed from
    both generators; 6 screws/piece + 24 board screws unchanged. C black
    re-rendered + repacked (audit clean); other nine blacks pending user
    review of the C.
    [board_layout.scad, word_layout.scad]
2026-07-14 chore: commit the July-6 working-tree state (predates the strap round)
    Mesh heal + hard-fail audit in make_3mf.py, word repairs data + generator
    (alt A / G ends / R re-spacing, 459 px), qa_coverage.py ink-vs-geometry
    check, cut-preview legend. All of this was in production use but never
    committed — the seam-strap session found it while building on it.
    Claude-Session: https://claude.ai/code/session_011kidvM2iiPzEUY13YcFpwo
    [gen_cutpreview.py, make_3mf.py, make_repairs.py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]
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2026-07-14 feat: seam straps — continuous LEDs across the bolt-board joints
    Anchored pixel placement (boltboard.py): pins straddle pixels at ±9.5mm
    perpendicular at all 7 channel/seam crossings; the two shallow crossings
    (31°/29°) pin the pixel ON the seam with its collar embedded in a printed
    strap (plates get Ø13 bites; pixel seats 2mm deeper, inside the validated
    optics window). Pitch auto-solved to the 137 budget (21.5mm); worst
    seam-adjacent gap 23.5mm (was 34-58). Relaxation now respects the keepout;
    anchors walk to true perpendicular distance.
    4 white PETG splice straps (bracket.scad, ~226g) replace the y-seam wood
    rail: Ø17 chamfered pass-holes, captive M4 nut pockets (23 screws,
    channe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
    [board_layout.scad, bolt_piece.scad, bracket.scad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]
2026-07-14 qa: independent board+strap audit (43 checks) + T-junction pass-hole fix
    tools/qa_board.py re-measures placement physics and screw legality from the
    emitted data, probes strap/plate features at STL level, and edge-audits every
    mesh; writes board_qa.json (rendered in the preview page) and exits 1 on FAIL.
    Real bug it caught: a pixel at (183,225) whose flange overlaps strap S4's
    corner at the T-junction — pass-holes are now cut in EVERY strap a pixel
    overlaps, not just the first match (S4 re-rendered, 12 pass holes).
    Checker fixes: seam-segment band check in the crossing scan (the red zigzag
    crosses the x=153 LINE mid-plate, not the seam), and rim-annulus probes for
    hex/flange pockets (walls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
    [bracket_layout.scad]
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2026-07-14 feat: publishable story page + WLED 16.x compatibility fixes
    tools/gen_story.py -> docs/sign-preview/index.html: the build story
    (brief -> optics coupons -> font forensics -> bolt -> seam straps -> wiring
    -> signforge brief), embedding the real diagrams extracted from the
    generated preview pages; CSS neon hero, reduced-motion safe, self-contained.
    WLED 16.x verification (parser source + docs + release notes): ledmaps now
    emit "width"/"height" — the keys WS2812FX::deserializeMap actually reads
    ("w"/"h" were silently ignored); grid-indexed map arrays with -1 gaps
    confirmed correct; wiring page now recommends 16.0.1+ (ledmap bounds fix)
    and documents the 0.15+ boot quirk (re-save 2D config o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
    [gen_story.py, gen_wiring.py]
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2026-07-15 fix: WLED ledmaps must be byte-compact — "map":[ or zero cells load
    WS2812FX::deserializeMap (v16.0.1, FX_fcn.cpp) finds the map array with a raw
    byte search for the literal "map":[ , while width/height go through a real
    ArduinoJSON parse. json.dump()'s default `"map": [` (with a space) therefore
    loaded width/height and flipped isMatrix=true, but ZERO map cells: the failed
    f.find() consumed the file to EOF, so `while (f.available())` never ran and
    customMappingSize stayed 0. WLED fell back to identity mapping and crammed the
    chain row-major into the top rows — the sign lit with plausible colors that
    looked nothing like the design, and reported no error anywhere. The real-JSON
    `JsonArray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
    [gen_wiring.py, test_wled_ledmap.py]
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2026-07-16 feat: emit charge_geometry.h for the tedxfargo usermod + host consistency test
    gen_wiring.py now also bakes per-pixel geometry (letter, grid col/row,
    height-in-letter, x-across-sign, letter ranges) into a PROGMEM C header,
    from the same mapping pass as the ledmap so they can never drift.
    test_charge_geometry.py proves internal consistency and that every pixel's
    (col,row) round-trips through the committed ledmap.json.
    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
    [charge_geometry.py, gen_wiring.py, test_charge_geometry.py]
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2026-07-17 feat: 8 new geometry-aware effects — surge, comet, marquee, neon morph, pac-man, lava, ants, raider
    All lean on chain-order-is-tube-order (1D inside the letters, device stays 2D):
    - CHARGE Surge: current packets race the tube over a charged glow; random
    letter takes an arc-flash surge every few seconds (electricity theme)
    - CHARGE Comet: white-hot head + sparking cyan tail traces the whole neon path
    - CHARGE Marquee: retro theater-bulb chase, warm amber, ember unlit bulbs
    - CHARGE Neon Morph: letters drift cyan<->TEDx red, failing-neon buzz dropouts
    - CHARGE Pac-Man: per-letter maze run — pellets, chomping pac, pursuing ghost
    - CHARGE Lava: lava-lamp blobs rise/sink in each letter (hei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
    [charge_fx.h]
2026-07-17 feat: 4 goblin masterpieces + full param surfaces + sim QA suite + audio
    New effects (13 total now):
    - CHARGE Gravity: palette balls bounce in each letter — real decay physics
    (parabolic arcs, restitution 0.62) on the baked height axis, xnorm lanes,
    floor impact flashes, optional motion trails
    - CHARGE Fireworks: PS-style 1D fireworks ported to tube space, per letter —
    rockets climb, burst into palette sparks that spread ballistically and
    decay; Rate/Palette/Sparks/crackle controls
    - CHARGE Drip: goo beads swell at letter tops, gravity-drop through
    (x,height) space with stretchy trails, splash at the base; slime default
    - CHARGE Pulse: audio pumps palette energy into each lette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
    [charge_fx.h]
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
